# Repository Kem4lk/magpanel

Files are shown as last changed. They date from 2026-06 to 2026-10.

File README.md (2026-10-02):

# FM6363C 80x40 1/20-scan HUB75E panel - ESP32-S3 driver (deneysel port)

mrcodetastic'in **ESP32-PWM-MatrixPanel-DMA** (MBI5153, ESP32-S3) implementasyonunun
FM6363C cipine portu. Panel: P4 indoor 80x40, 1/20 scan, 74HC138 satir decode,
FM6363C S-PWM surucu. Register degerleri panelin fabrika .ssx profilinden alindi.

## Mimari
- **LCD peripheral (DMA)**: DCLK + 6 RGB SDI hatti + LE/LAT -> grayscale verisi ve komutlar
- **GPSPI2 octal (DMA, sonsuz dongu)**: GCLK + A..E adres hatlari (satir tarama)

## Kablolama (mevcut HUB75 baglantin korunuyor)
| HUB75 | Islev | GPIO |
|---|---|---|
| R1 G1 B1 | ust yari SDI | 4, 5, 6 |
| R2 G2 B2 | alt yari SDI | 7, 15, 16 |
| A B C D E | satir adresi | 18, 8, 3, 9, 13 |
| CLK | DCLK | 12 |
| LAT | LE (komut) | 10 |
| OE | **GCLK** | 11 |

## Sensörler ve tam bağlantı şeması
`hardware/` klasöründe koddan üretilen şema (`gen_schematic.py` → `schematic.svg/png`) ve
pin tablosu var: [hardware/README.md](hardware/README.md). HUB75 kablolaması değişmedi;
beş JSUMO modülü ESP'nin SAĞ başlığına takılır (hepsi 3V3 ile beslenir):

| Modül | Pin | GPIO |
|---|-----|---|
| LDR Sensor Board (3 pin, dijital) | DO | 1 (ADC1) |
| Microphone Sound Sensor (3 pin, dijital) | OUT | 42 |
| KY-040 Mechanic Encoder | CLK / DT / SW | 41 / 40 / 39 |
| DHT11 Temperature & Humidity | OUT | 47 |
| TTP223B Digital Touch | SIG | 21 |

Firmware tarafı (`include/sensors.h`, `include/sensor_logic.h`): enkoder = parlaklık,
enkoder/dokunmatik/çift alkış → uyku-uyan / sonraki uygulama / sonraki galeri / oto parlaklık
(web UI "Sensörler & kontroller" kartından eşlenir, NVS'te kalır); LDR ile oto parlaklık;
"Oda" (sıcaklık/nem/ışık/saat) ve "Ses" (VU) uygulamaları; 1 Hz `S:` telemetri + `/api/sensors`.

**KiCad taşıyıcı kart:** ESP32-S3-DevKitC-1 soketi, 2× 74HCT245 DIP-20 (3.3 → 5 V), üç HUB75E
çıkışı ve sensör başlıkları olan 2 katmanlı PCB. Şematik, PCB, gerber ve BOM koddan üretilir:
[hardware/kicad/README.md](hardware/kicad/README.md).

## Derleme
VS Code + PlatformIO eklentisi. Proje klasorunu ac -> Build -> Upload.
(`platformio.ini` ESP32-S3 DevKitC-1 icin hazir.)

## Test asamalari ve sorun giderme
1. **Duz kirmizi/yesil/mavi dolgular**: Temizse config + veri yolu calisiyor demektir.
   - Panel tamamen karanliksa: once `FM_GCLKS_PER_ROW`'u 148 yap (cift-kenar sayim ihtimali),
     olmadi GCLK frekansini dusur (spi_dma_seg_tx_loop.c).
   - Renkler yer degistirmisse: app_constants.hpp'de R/G/B pinlerini duzelt.
2. **Kose pikselleri**: Dort kose dogru yerde ve dogru renkteyse haritalama tamam.
   - Ust/alt yarilar ters ise R1<->R2 gruplarini degistir.
   - Satirlar 2'serli atliyorsa D ve E pinlerini degistir.
3. **Piksel yurutme**: x=0..79 duzgun soldan saga akmiyorsa izledigi sirayi not et:
   - 16'sarlik bloklar ters siradaysa: `FM6363_REVERSE_CHANNEL_ORDER 1` yap.
   - Daha karmasik bir desen varsa fabrika .ssx LookUpTab remap'ini ekleyecegiz (bende cozumu hazir).

## Bilinen belirsizlikler (ilk testte netlesecek)
- GCLK cift-kenar sayimi: 74 vs 148 GCLK/satir denemesi gerekebilir.
- VSYNC sirasinda GCLK duraklatma zamanlamasi hassas olabilir.
- Kanal sirasi (ch15 ilk mi) panel PCB'sine bagli.

## Guncelleme (OTA) ve tek komutla deploy
- Her panel `GITHUB_AUTO_OTA` ile `releases/latest`'teki `version.txt`'i yoklar; build
  numarasi artmissa `firmware.bin`'i indirip kurar. Kurulum sirasinda panelde **tum
  piksellerden olusan, alttan dolan loading ekrani** gosterilir (`drawOtaLoading`).
- "Yukle/deploy" demek icin: `tools/magpanel-mcp/` altindaki MCP sunucusu (repo kokundeki
  `.mcp.json` ile otomatik kayitli). Claude'a **"yukle"** dediginizde `deploy_update` araci
  CI'yi tetikler; firmware `latest` release'e gider ve internete bagli tum paneller otomatik
  guncellenir. Kurulum: [tools/magpanel-mcp/README.md](tools/magpanel-mcp/README.md).

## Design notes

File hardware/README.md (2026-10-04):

# MagPanel donanım — bağlantı şeması ve sensörler

ESP32-S3-DevKitC-1 + HUB75E LED panel (P4 80×120 ya da P1.86 172×86, 1–3 modül) +
beş JSUMO sensör/kontrol modülü. Şema **koddan üretilir** (`gen_schematic.py`, sadece
stdlib) — kasa gibi (`enclosure/generate_case.py`) parametrik: pin değişince script'i
düzelt, yeniden üret. Pin ataması `include/sensors.h` ve `include/app_constants.hpp`
ile birebir aynı olmalı.

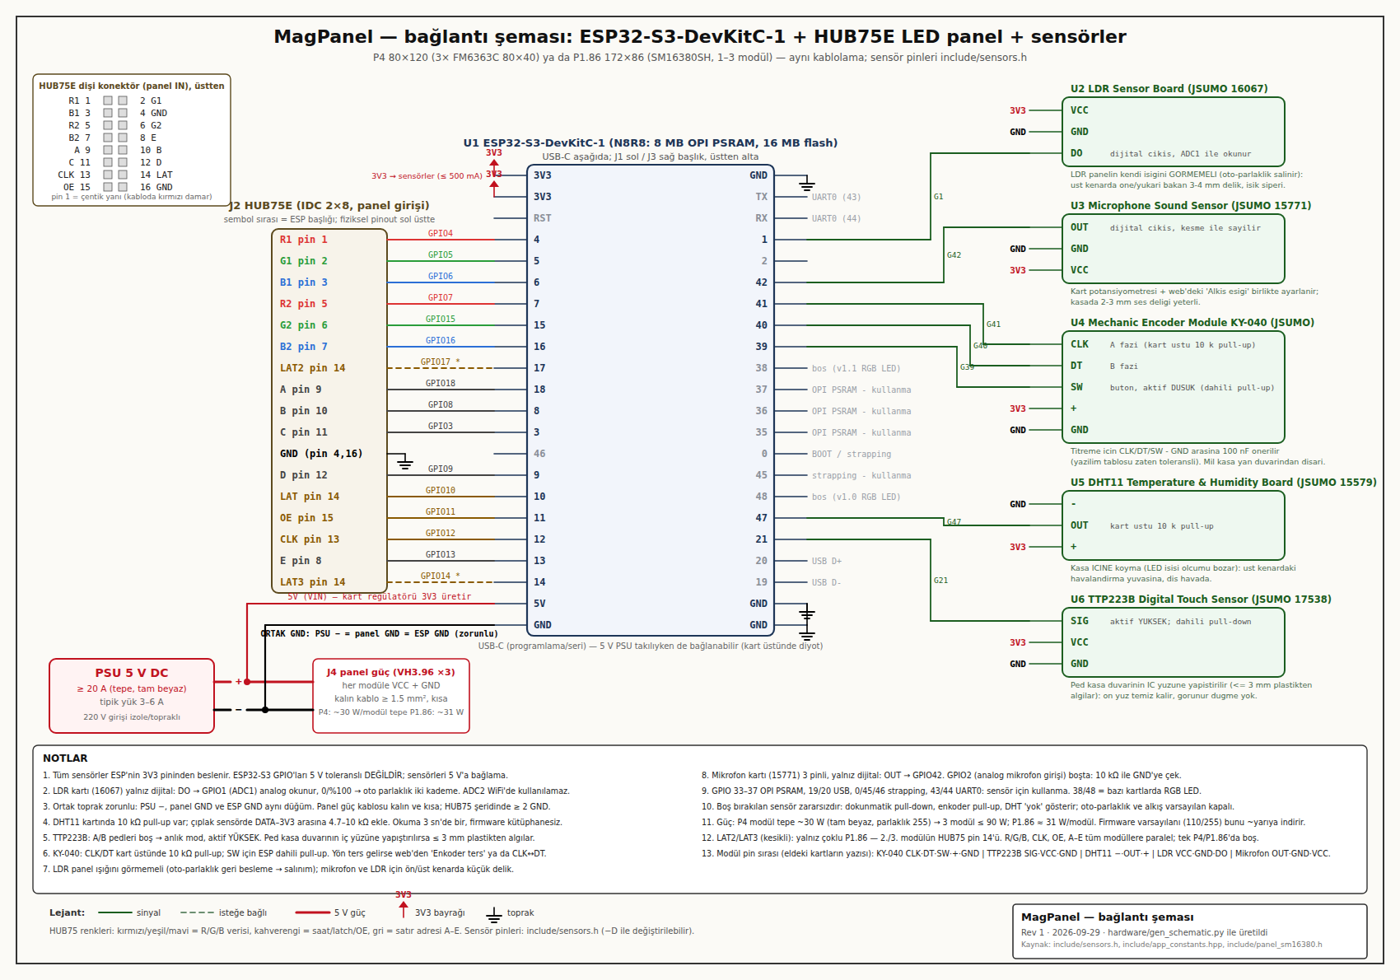
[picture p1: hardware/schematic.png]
MagPanel bağlantı şeması


Vektör: [`schematic.svg`](schematic.svg) · Üretici: [`gen_schematic.py`](gen_schematic.py)

## KiCad taşıyıcı kart (şematik + PCB)
Aynı bağlantıların üretilebilir hâli: DevKit soketi, 2× 74HCT245 (DIP-20) seviye dönüştürücü,
3× HUB75E çıkışı (LAT panel başına), 5 V giriş koruması ve sensör başlıkları. KiCad 8
projesi, gerber/BOM/CPL dosyaları ve üretici [`kicad/`](kicad/README.md) klasöründe.

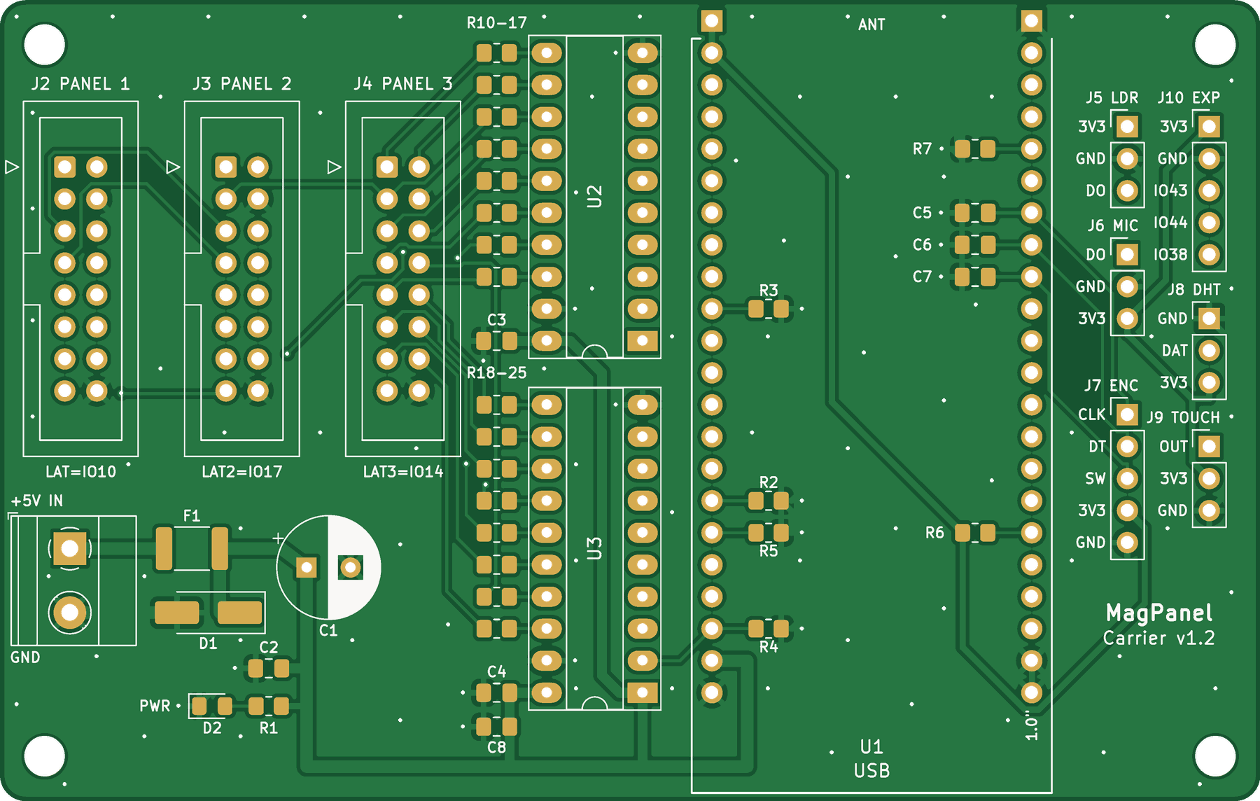
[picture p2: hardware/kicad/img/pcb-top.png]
MagPanel taşıyıcı kart


## Pin tablosu (ESP32-S3-DevKitC-1)

### HUB75E (değişmedi — `include/app_constants.hpp`)
| HUB75 pin | İşlev | GPIO | | HUB75 pin | İşlev | GPIO |
|---|---|---|---|---|---|---|
| 1 | R1 | 4 | | 9 | A | 18 |
| 2 | G1 | 5 | | 10 | B | 8 |
| 3 | B1 | 6 | | 11 | C | 3 |
| 4 | GND | GND | | 12 | D | 9 |
| 5 | R2 | 7 | | 13 | CLK (DCLK) | 12 |
| 6 | G2 | 15 | | 14 | LAT (LE) | 10 |
| 7 | B2 | 16 | | 15 | OE (P4: GCLK) | 11 |
| 8 | E | 13 | | 16 | GND | GND |

Çoklu P1.86 (2–3 modül, `include/panel_sm16380.h`): tüm modüller R/G/B, CLK, OE, A–E
hattını paylaşır; **2. modülün LAT'ı GPIO17, 3. modülün LAT'ı GPIO14** (şemada kesikli).

### Sensörler (`include/sensors.h`; `-DSENS_PIN_*` ile değiştirilebilir)
| Modül (JSUMO kodu) | Modül pini | GPIO | Mod | Not |
|---|---|---|---|---|
| LDR Sensor Board (16067) | DO | **1** (ADC1_CH0) | analog okuma | kart yalnız dijital: oto parlaklık iki kademe |
| Microphone Sound Sensor (15771) | OUT | **42** | giriş, pull-up | kart yalnız dijital: kesme sayımı, VU + çift alkış |
| (analog mikrofon girişi) | — | **2** (ADC1_CH1) | analog | eldeki kartta yok; boşta kalmasın (taşıyıcıda R7 10 kΩ GND) |
| Mechanic Encoder Module KY-040 | CLK (A) | **41** | giriş, pull-up | kesme, tam-adım tablo |
| KY-040 | DT (B) | **40** | giriş, pull-up | |
| KY-040 | SW | **39** | giriş, pull-up | aktif düşük; kısa/uzun basma |
| DHT11 Temperature & Humidity Board (15579) | OUT | **47** | open-drain + pull-up | 3 sn'de bir okuma |
| TTP223B Digital Touch Sensor (17538) | SIG | **21** | giriş, pull-down | aktif yüksek, anlık mod |
| hepsi | VCC / + | **3V3** | | 5 V'a BAĞLAMA (GPIO 5 V toleranslı değil) |
| hepsi | GND / − | GND | | |

Eldeki modüllerin pin sırası (kart baskısı, 2026-10-02 fotoğrafları): LDR **VCC GND DO**,
mikrofon **OUT GND VCC**, KY-040 **CLK DT SW + GND**, DHT11 **− OUT +**, TTP223B **SIG VCC GND**.
KiCad taşıyıcı kartındaki başlıklar aynı sırada; düz kablo çaprazlamaz.

**Neden bu pinler:** HUB75 ESP'nin sol başlığını (3–18) kullanır; sensörlerin hepsi sağ
başlığa düşer → şemada kablolar çaprazlaşmaz, kablolama kolay. Analog girişler zorunlu
olarak ADC1'de (GPIO1–10; ADC2 = GPIO11–20 WiFi açıkken okunamaz). Kullanılmayanlar:
19/20 USB, 33–37 OPI PSRAM, 0/45/46 strapping, 43/44 UART0, 38/48 devkit RGB LED'i.

## Güç
| | |
|---|---|
| PSU | 5 V DC, tepe için ≥ 20 A (P4 modül tam beyaz ~30 W ×3; P1.86 ≈ 31 W/modül). Tipik yük 3–6 A. |
| Panel | J4: her modüle VCC+GND, ≥ 1.5 mm² kısa kablo. HUB75 şeridinde en az 2 GND (pin 4 + 16). |
| ESP32 | PSU +5 V → devkit **5V** pini (VIN); kart regülatörü 3V3 üretir (sensörler ≤ 500 mA bütçesinde). USB aynı anda takılı olabilir (kart diyotlu). |
| Toprak | PSU −, panel GND ve ESP GND **aynı düğüm** (ortak GND şart; `BULGULAR.md`). |

Firmware varsayılan parlaklığı (110/255) tepe gücü kabaca yarıya indirir; oto parlaklık
karanlıkta daha da düşürür.

## Modül notları
- **TTP223B:** A/B pedleri boş → anlık mod, aktif YÜKSEK. Ped **kasa duvarının iç yüzüne**
  yapıştırılırsa ≤ 3 mm plastikten algılar; ön yüz temiz kalır (görünür düğme yok).
  Firmware GPIO21'i pull-down tutar → modül takılı değilken sahte tetik yok.
- **DHT11 kartı:** üzerinde 10 kΩ pull-up var; çıplak sensörde DATA–3V3 arasına 4.7–10 kΩ.
  Kasa **içine** koyma: LED paneli ısınır, oda sıcaklığı yanlış çıkar → üst kenardaki
  havalandırma yuvasına, dış havada. DHT22/AM2302 takılırsa `-DSENS_DHT22=1`.
- **KY-040:** CLK/DT kart üstünde 10 kΩ pull-up; SW için ESP dahili pull-up. Titreme için
  CLK/DT/SW–GND 100 nF önerilir (yazılım tablosu zaten sıçrama toleranslı; KiCad
  taşıyıcı kartında C5–C7 olarak var). Yön ters
  gelirse web'den "Enkoder ters" ya da CLK↔DT değiştir. Mil kasa yan duvarından dışarı,
  düğme takılır.
- **LDR kartı:** panelin **kendi ışığını görmemeli** (geri besleme → oto parlaklık salınımı):
  üst kenarda öne/yukarı bakan 3–4 mm delik + küçük ışık siperi. Eldeki kart 3 pinli ve
  yalnız karşılaştırıcı çıkışı (DO) veriyor: firmware GPIO1'i okur, sonuç 0 ya da %100 olur.
  Oto parlaklık böylece iki kademe çalışır; geçiş eşiği kart üstündeki trimpotla ayarlanır.
  Aydınlıkta parlaklık düşüyorsa web'den "LDR ters" işaretle. Kademesiz ayar için AO'lu
  (4 pinli) LDR kartı ya da çıplak LDR + 10 kΩ bölücü GPIO1'e bağlanmalı.
- **Mikrofon kartı:** eldeki kart 3 pinli (OUT, GND, VCC) ve yalnız dijital: OUT → GPIO42.
  Firmware DO tetiklerini "yüksek ses" sayar; VU göstergesi açık/kapalı çalışır.
  GPIO2 (analog mikrofon girişi) boşta kalırsa gürültü okur: taşıyıcı kartta R7 (10 kΩ) GND'ye çeker.
  Kart potansiyometresi + web'deki "Alkış eşiği" birlikte ayarlanır (ses çubuğu alkışta
  eşik çizgisini geçmeli, konuşmada geçmemeli). Kasada 2–3 mm ses deliği yeter.

## Kasa yerleşimi (enclosure/ ile uyum)
Kapalı difüzör ön yüz korunur; hiçbir sensör önden görünmez:
- **Üst kenar:** LDR deliği (öne bakan), mikrofon deliği, DHT11 havalandırma yuvası
  (mevcut kablo çıkışının yanı). `generate_case.py`'ye üst duvara üç delik + bir yuva
  eklemek yeterli (henüz eklenmedi — bkz. açık sorular).
- **Yan kenar:** enkoder mili (7 mm delik + somun), dokunmatik ped iç yüzde (işaret için
  dışa küçük bir kabartma/sticker).
- Modüller ESP'ye kısa (≤ 30 cm) jumper ile; DHT11 ve LDR için 3 damar, enkoder 5 damar.

## Yazılım tarafı (özet — ayrıntı `CLAUDE.md`)
- `include/sensor_logic.h`: saf C++ durum makineleri (enkoder tablosu, DHT çözme, alkış,
  buton, oto parlaklık) — `tools/test_sensor_logic.cpp` ile host'ta test edilir.
- `include/sensors.h`: pinler, kesmeler, bloklamayan DHT okuma, NVS `sensors`.
- Web UI "Sensörler & kontroller" kartı: canlı değerler, oto parlaklık, eylem eşlemeleri
  (enkoder bas / uzun bas / dokunmatik / çift alkış → uyku, sonraki uygulama, sonraki galeri,
  oto parlaklık), alkış eşiği, uyku düğmesi. WS `0x11` ayar, `0x12` uyku; `"S:"` 1 Hz
  telemetri, `"C:"` ayar, `"B:"` parlaklık; HTTP `/api/sensors`.
- Yeni uygulamalar: **Oda** (sıcaklık/nem/ışık/saat), **Ses** (VU geçmişi). Hava
  uygulamasına iç mekan satırı eklendi.

## Yeniden üretmek
```bash
python3 hardware/gen_schematic.py                     # schematic.svg (kesişim kontrolü yapar)
# PNG (Chromium headless; herhangi bir SVG→PNG aracı da olur):
chromium --headless=new --hide-scrollbars --window-size=1700,1400 \
  --screenshot=/tmp/s.png file://$PWD/hardware/schematic.svg
python3 -c "from PIL import Image; Image.open('/tmp/s.png').crop((0,0,1700,1190)).save('hardware/schematic.png')"
```

## Açık sorular / doğrulanacaklar
1. LDR yönü (ışıkta artan mı azalan mı) → web'de "LDR ters".
2. Kademesiz oto parlaklık istenirse AO'lu LDR kartı ya da çıplak LDR gerekir (eldeki kart dijital).
3. Kasaya sensör delikleri eklenecek mi (generate_case.py)?
4. Enkoder/dokunmatik varsayılan eylemleri: basma = uyku/uyan, uzun basma = sonraki
   uygulama, dokunmatik = uyku/uyan, çift alkış = kapalı. Web'den değiştirilebilir.

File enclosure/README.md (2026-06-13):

# MagPanel Difüzör Kasası — 320×480 mm (P4 / 80×120 px)

`case20mm.stl` (162×162×32 mm, **kare**, ince kabuk difüzör + egg-crate takviye)
tasarımının **32×48 cm** panele uyarlanmış hâli. Aspect-ratio 1:1 → 2:3
değiştiği ve duvarlar baskıya uygun kalınlaştırıldığı için basit ölçekleme
yerine **parametrik olarak yeniden üretildi** (`generate_case.py`).

Seçimler: **kapalı difüzör ön** · **2×2 fayans** (yatağa sığsın) · **duvar montaj özelliği yok**.

## Ölçüler
| | |
|---|---|
| Dış ölçü | **326.3 × 486.3 × 31.2 mm** |
| Panel yuvası (iç) | **321.5 × 481.5 mm**, derinlik **14 mm** (panel 320×480 + 0.75 mm boşluk/kenar) |
| Ön difüzör kabuğu | 1.2 mm (ışık süzülür) |
| Egg-crate / ışık boşluğu | 16 mm, hücre adımı ~20 mm (16 hücre/genişlik) |
| Dış duvar | 2.4 mm |
| Fayans (×4) | **163.1 × 243.1 × 31.2 mm** → en az ~**245 × 170 mm** yatak gerekir |

## Parçalar (`stl/`)
- `tile_top_left/right`, `tile_bottom_left/right` — 4 fayans
- `splice_center` (4 vida) + `splice_Vtop/Vbot/Hrt/Hlf` (2'şer vida) — 5 ek plaka
- `full_case_1piece.stl` — referans tek parça (büyük yatak / CNC / dış üretim için)
- **Vida:** ~12 × **M3 kendinden kılavuzlu (self-tapping) × 12 mm**, silindir/düz baş

## Baskı
- **Yön:** her fayansı **ön yüz (difüzör) yatağa dönük** bas → düz, pürüzsüz ön; kaburgalar yukarı, destek gerekmez.
- **Difüzör için yarı saydam malzeme** (natürel/beyaz PLA, ya da "ışık geçiren" filament). Işığı eşit dağıtmak için ön kabuk dolu (%100) basılmalı; ön yüzde 4-5 katı düz tut.
- Duvarlar 1.2–2.4 mm → 0.4 mm nozül, **3–6 duvar (perimeter)** yeterli, iç dolgu ~%10.
- Plakalar düz, desteksiz basılır.

## Montaj
1. 4 fayansı ön yüz aşağı, masaya diz (egg-crate yukarı).
2. Ek plakaları arka (egg-crate) tarafından dikişlerin üstüne yerleştir; plakalar yuvalara gömülür, üstü kaburga düzlemiyle aynı hizada kalır. `splice_center` ortadaki 4'lü kavşağı, diğer 4 plaka dikiş ortalarını kenetler.
3. M3 vidaları plakadan boss'lara sık (kendinden kılavuz). Vida başları gömülü kalır, **panel düzlemini engellemez.**
4. LED paneli **LED yüzü öne (difüzöre) bakacak** şekilde yuvaya yatır; kaburga üstüne oturur. Kabloyu üst kenardaki yuvadan çıkar.

## ⚠️ Bilmen gerekenler / seçenekler
- **Ağırlık/süre:** ~**616 cm³ ≈ 764 g** plastik, toplam baskı uzun. Hafifletmek için `generate_case.py` içinde `n_cells_x`'i azalt (örn. 10 → daha seyrek ızgara), `t_front`/`rib_t`'yi 1.0'a indir.
- **Egg-crate ışık yolunda:** orijinaldeki gibi kaburgalar difüzör ile LED arasında → difüzörde **hafif ızgara/gölge deseni** olur (dekoratif "glow" görünümü). **Net görüntü** istiyorsan kaburgaları ışık yolundan çıkaran **"temiz ışık odası"** varyantını üretebilirim (söyle, yaparım).
- **Dikiş çizgisi:** fayanslar düz birleşir (butt); ön yüzde çok ince bir dikiş izi görülebilir. İstersen ışık sızdırmaz bindirme (ship-lap) eklerim.
- **Panel tutuşu:** yuvanın arkası açık; duvara asılınca panel duvarla tutulur. Taşımada düşmemesi için köşelere küçük tutucu tırnak/bant eklenebilir.
- **Panel ölçüsünü doğrula:** yuva, modülün **fiziksel dış ölçüsü 320×480 mm** ve **≤14 mm kalınlık** varsayımıyla yapıldı. Seninki farklıysa `panel_W/H`, `pocket_d`, `clr`'yi güncelle.

## Yeniden üretmek / ayarlamak
```bash
pip install trimesh manifold3d numpy
python3 generate_case.py        # stl/ klasörünü üretir
```
Tüm ölçüler `generate_case.py` başındaki `P` sözlüğünde. Panel boyutu, duvar,
derinlik, hücre sıklığı, bölme ve vida ölçüleri oradan değiştirilir.

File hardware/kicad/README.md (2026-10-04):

# MagPanel Carrier — KiCad 8 şematik + PCB

ESP32-S3-DevKitC-1'i soketle taşıyan, üç HUB75E çıkışı (P4 tek panel ya da P1.86 1–3 modül)
ve beş JSUMO sensör başlığı olan iki katmanlı taşıyıcı kart. Kasa (`enclosure/generate_case.py`)
ve bağlantı şeması (`hardware/gen_schematic.py`) gibi her şey **koddan üretilir**:
[`gen_carrier.py`](gen_carrier.py). Pin, parça ya da yerleşim değişirse dosyanın başındaki
tabloları düzelt ve yeniden üret. KiCad'de elle yapılan değişiklik bir sonraki üretimde kaybolur.

Kart üst yüz

| | |
|---|---|
| Kart | 100 × 63.5 mm, 2 katman, 1.6 mm FR4, köşelerde 4× M3 |
| İz genişliği | sinyal 0.25 mm, 3V3 0.5 mm, 5 V / VIN 0.8–1.0 mm |
| Kurallar | boşluk ≥ 0.15 mm, via 0.6/0.3 mm, kenar 0.3 mm (JLCPCB standart 2 katman) |
| El lehimi | en küçük parça 0805, el lehimi pedleri, parçalar arası ≥ 0.5 mm (DRC kuralı) |
| GND | iki katmanda döküm + dikiş via'ları |
| Doğrulama | ERC 0, DRC 0 ihlal, 0 bağlanmamış, şematik↔PCB farkı 0 |

Doğrulama satırı `fab` aşamasında her seferinde yeniden kontrol edilir. Biri sıfır değilse
gerber üretilmez.

**Evde yapmak için** iki sürüm var. İkisi de Elegoo Saturn 3 Ultra ile pozlanır ve yazıcıya hazır
`.goo` dosyalarıyla gelir: negatif dry film için `saturn3/`, Positiv 20 gibi pozitif lak için
`saturn3-pozitif/`.
- Tek yüz, 150 × 100 mm: yalnız alt bakır, tek pozlama, bakır yüzde 3 tel. DevKit pin adları
  soket sıralarının iç tarafında bakırda yazılı. Anlatım: [`TEK-YUZ.md`](TEK-YUZ.md).
- Çift yüz, 100 × 63.5 mm: kaplamasız delik, SMD'ler altta, 33 telli via. Anlatım:
  [`DIY.md`](DIY.md).

## Dosyalar
| Yol | İçerik |
|---|---|
| `magpanel-carrier/` | KiCad 8 projesi: `.kicad_pro`, `.kicad_sch`, `.kicad_pcb`, `.kicad_dru` |
| `magpanel-carrier/MagPanel.kicad_sym`, `MagPanel.pretty/` | DevKit sembolü ve soket footprint'i |
| `fab/magpanel-carrier-gerber.zip` | gerber + delik dosyaları (doğrudan yüklenir) |
| `fab/magpanel-carrier-bom.csv` | tam malzeme listesi |
| `fab/magpanel-carrier-jlc-bom.csv`, `fab/magpanel-carrier-jlc-cpl.csv` | JLCPCB SMT montajı (yalnız SMD, LCSC numaralı) |
| `fab/magpanel-carrier-robotistan-bom.xlsx`, `fab/magpanel-carrier-robotistan-pnp.xlsx` | Robotistan SMT montajı (yalnız SMD, LCSC numaralı) |
| `fab/magpanel-carrier-bomlist.xlsx` | Türkçe BOM şablonu: Fabrika Kodu, Açıklama, Designatör, Malzeme Kılıfı, Adet (yalnız SMD) |
| `fab/magpanel-carrier-schematic.pdf` | şematik (A3) |
| `fab/magpanel-carrier-1to1.pdf` | 1:1 yerleşim testi (A4, ölçek çubuklu) |
| `magpanel-carrier-ss/`, `fab-ss/` | ev yapımı tek yüz sürüm, 150 × 100 mm, bkz. [`TEK-YUZ.md`](TEK-YUZ.md) |
| `magpanel-carrier-diy/`, `fab-diy/` | ev yapımı çift yüz sürüm, bkz. [`DIY.md`](DIY.md) |
| `img/` | şematik ve kart görselleri |

Şematik: [`img/schematic.png`](img/schematic.png) · Alt yüz: [`img/pcb-bottom.png`](img/pcb-bottom.png)

## Devre
1. **5 V giriş ve koruma.** Vida klemensi J1, 1.5 A PTC sigorta F1 ve SMAJ5.0A TVS D1'den
   geçer. Ters kutupta D1 iletir ve F1 açar. Ardından 470 µF + 10 µF ile DevKit'in **5V**
   pinine ve tamponlara gider. Panel gücü bu karttan geçmez: PSU'dan panele kalın kablo.
   Kartın kendi tüketimi 1 A'in altındadır.
2. **DevKit soketi U1.** İki adet 1×22 dişi soket. Sağ sıra 1.0" (25.40 mm) uzakta: eldeki
   N16R8 klonu (2× USB-C) 1:1 baskı testinde bu sıraya oturdu. Resmi Espressif kartı 0.9"
   (22.86 mm) kullanır; onun için `DEVKIT_RIGHT_ROWS` değiştirilip yeniden üretilir. Anten
   kartın üst kenarından dışarı taşar, USB alt kenardadır.
3. **Seviye dönüştürücü.** İki CD74HCT245E (DIP-20, soketli), 3.3 V mantığı 5 V'a çevirir
   (DIR = 5 V, /OE = GND). HCT girişleri TTL eşiklidir, 3.3 V yüksek seviyeyi 5 V beslemede
   güvenle okur; düz 74HC245 bu iş için uygun değildir. A pinleri DevKit pinleriyle aynı
   2.54 mm adımda, bir iki satır kayarak kısa ve kesişmeyen izlerle bağlanır.
   LAT, LAT2, LAT3 ve OE'de 10 kΩ pull-down var: açılışta GPIO'lar sürülmezken panel karanlık
   kalır. P4'te OE hattı GCLK taşır, P1.86'da aktif-yüksek OE darbesi.
4. **HUB75E çıkışları J2–J4.** Her hatta bir 33 Ω seri direnç (R10–R25, 0805) kablo
   yansımalarını bastırır. Dirençler tek sütundadır, her biri kendi tampon pininin hizasında.
   Bütün hatlar paraleldir, yalnız LAT panel başına ayrıdır:

   | Konnektör | LAT | Kullanım |
   |---|---|---|
   | J2 PANEL 1 | IO10 | P4 ve P1.86 |
   | J3 PANEL 2 | IO17 | yalnız çoklu P1.86 |
   | J4 PANEL 3 | IO14 | yalnız çoklu P1.86 |

5. **Sensör başlıkları (3.3 V).** Pin sırası eldeki JSUMO modüllerinin baskısıyla aynıdır,
   düz kablo çaprazlamaz. GPIO'lar `include/sensors.h` ile aynıdır, her pin serigrafide yazılıdır.

   | Başlık | Modül baskısı | Kart sırası | GPIO |
   |---|---|---|---|
   | J5 LDR | VCC GND DO | 3V3, GND, DO | DO → IO1 |
   | J6 MIC | OUT GND VCC | DO, GND, 3V3 | OUT → IO42 |
   | J7 ENC | CLK DT SW + GND | CLK, DT, SW, 3V3, GND | IO41 / IO40 / IO39 |
   | J8 DHT | − OUT + | GND, DAT, 3V3 | OUT → IO47 |
   | J9 TOUCH | SIG VCC GND | OUT, 3V3, GND | SIG → IO21 |
   | J10 EXP | | 3V3, GND, IO43, IO44, IO38 | genişleme |

   LDR ve mikrofon modülleri yalnız dijital çıkışlıdır. LDR'nin DO'su IO1'den okunur ve oto
   parlaklık iki kademe çalışır. Mikrofonun OUT'u IO42 kesmesine gider. Analog mikrofon girişi
   IO2 boşta gürültü okumasın diye R7 (10 kΩ) onu GND'ye çeker. C5–C7 enkoder için RC filtre,
   R6 DHT11 veri hattı pull-up'ıdır.

GPIO tablosu ve modül notları: [`../README.md`](../README.md).

## Yeniden üretmek
Gerekenler: KiCad 8 (`pcbnew` python modülü ve `kicad-cli`), Java 21+ (Freerouting için),
görseller için Chromium ya da Chrome (`CHROME=/yol` ile verilebilir).

```bash
cd hardware/kicad
PY=/usr/bin/python3        # Linux: KiCad'in python'u
# macOS: PY=/Applications/KiCad/KiCad.app/Contents/Frameworks/Python.framework/Versions/Current/bin/python3
$PY gen_carrier.py sch     # şematik + proje + semboller (yalnız stdlib)
$PY gen_carrier.py pcb     # yerleşim, kart çerçevesi, kilitli 5 V ana hat, SMD GND via'ları
$PY gen_carrier.py route   # Freerouting 2.1.0 + GND dökümü + dikiş via'ları
$PY gen_carrier.py fab     # ERC/DRC kapısı + gerber/delik/BOM/CPL/PDF + görseller
$PY gen_carrier.py all     # hepsi sırayla
$PY gen_carrier.py --ss all    # ev yapımı tek yüz: magpanel-carrier-ss/ ve fab-ss/ (TEK-YUZ.md)
$PY gen_carrier.py --diy all   # ev yapımı çift yüz: magpanel-carrier-diy/ ve fab-diy/ (DIY.md)
```

- `route` Freerouting jar'ını yoksa `work/` altına indirir (yaklaşık 67 MB).
- Freerouting deterministik değildir: her çalıştırma farklı ama eşdeğer bir yönlendirme
  verir. Aşama, DRC temiz çıkana kadar en çok 10 kez dener. Freerouting bağlantıyı tamam
  sayıp KiCad kopuk görürse mevcut izlerle bir tamamlama turu daha çalışır.
- `work/` ara dosyalar içindir ve git'e girmez.

## Sipariş ve montaj
- **PCB:** `fab/magpanel-carrier-gerber.zip` yükle. 2 katman, 1.6 mm, HASL ya da ENIG.
- **Önce 1:1 test:** `fab/magpanel-carrier-1to1.pdf` dosyasını yazıcıda %100 ölçekle bas,
  alttaki 100 mm çizgiyi cetvelle doğrula, gerçek parçaları deliklere oturt.
- **SMT montaj (isteğe bağlı):** bütün SMD parçalar üst yüzdedir. Montaj dosyalarında yalnız
  bunlar var (33 parça, 8 satır); delikli parçalar elle lehimlenir. Koordinatlar kartın sol-alt
  köşesine göredir, gerber ve delik dosyaları da aynı orijini kullanır. Parçaların LCSC
  numaraları `gen_carrier.py` içindeki `SMT_PARTS` tablosundadır ve LCSC'de stoklu olarak
  doğrulandı (2026-10-02). Yönler KiCad'den gelir: yerleşim önizlemesinde D1'in katot bandı
  sağda (+5V), D2'nin katodu solda (GND) olmalı.
  - JLCPCB: `jlc-bom.csv` ve `jlc-cpl.csv`.
  - Robotistan: `robotistan-bom.xlsx` ve `robotistan-pnp.xlsx` (örnek dosyalarıyla aynı sütunlar).
    BOM'daki Quantity kart başına adettir.
  - Türkçe şablon isteyen servisler: `bomlist.xlsx` (Fabrika Kodu = MPN, Adet kart başına).

### Robotistan PCB servisi
| Form alanı | Seçim |
|---|---|
| Gerber | `fab/magpanel-carrier-gerber.zip` |
| Katman, kalınlık, ölçü | 2 katman, 1.6 mm, 100 × 63.5 mm |
| Via kaplaması | Tented (maskeli), tasarım buna göre |
| Dizgi yüzeyi | Üst |
| Edge Rails/Fiducials | Robotistan tarafından eklenecek (kartta ray ve fiducial yok) |
| Komponent yerleşimi onayı | Evet (D1 ve D2'nin yönü kontrol edilsin) |
| BOM / Pick and Place | `robotistan-bom.xlsx` / `robotistan-pnp.xlsx` |

Raylar eklenirse kartlar raylı gelir. Ray kırılarak ayrılır ya da "Teslimattan önce panel ayırma"
seçilir.

### Elle lehim
Kart havyayla lehimlenecek şekilde çizildi:

| | v1.1 | v1.2 |
|---|---|---|
| Seri dirençler | 4× dizi 4×0603, komşu pedler arası 0.35 mm | 16× 0805, komşu pedler arası 1.14 mm |
| SMD ayak izi | standart ped | el lehimi pedi (dışa uzun) |
| En dar parça aralığı (courtyard) | 0.16 mm | 0.58 mm |
| 0.5 mm kuralına göre ihlal | 13 | 0 |
| HUB75 başlık gövdeleri arası | 2.4 mm | 3.8 mm |
| DevKit altındaki SMD pedi ile soket gövdesi arası | 1.2 mm | 1.6 mm |
| DIP soket pedi | 1.6 mm yuvarlak | 2.4 × 1.6 mm uzun |

- Parçalar arası en az 0.5 mm bir DRC kuralıdır (`el_lehim_aralik`). İhlal varsa gerber çıkmaz.
- Via'lar maskeyle örtülüdür, pede yakın via lehimi emmez. GND pinleri dökümle termal kolla
  bağlıdır, havya ısıyı kaybetmez.
- D1 (TVS) anodu J1'in GND pinine doğrudan kalın izle gider. Ters kutupta F1'i açan akım yolu kısadır.

Montaj sırası (alçaktan yükseğe, kart masada düz durur):
1. SMD'ler: 0805 dirençler ve kondansatörler, D2, sonra F1 ve D1. D1 ve D2'nin katodu serigrafideki
   kapalı uca bakar. DevKit altındakiler (R2–R7, C5–C7) soketlerden önce lehimlenmeli.
   SMT dizgi yaptırıldıysa bu adım hazır gelir.
2. İki DIP-20 soket. Çentik serigrafideki çentikle aynı yöne.
3. Altı pin başlık (sensörler).
4. Üç HUB75 kutu başlığı. Kutunun çentiği serigrafideki boşluğa (sola) gelir.
5. Vida klemensi J1, kablo girişi kart kenarına bakar.
6. Elektrolitik C1, uzun bacak (+) kare pede.
7. DevKit'in iki 1×22 dişi soketi en son. DevKit soketlere takılıyken lehimlenirse sıralar hizalı kalır.

İlk açılış: tamponlar ve DevKit takılı değilken 5 V ver. PWR yanmalı, DevKit soketinin 5V ve GND
pinleri arasında 5 V ölçülmeli. Sonra 74HCT245'leri (çentik aynı yöne) ve DevKit'i tak.

Başlıkların yan yana durması sorun değildir: hatlar zaten paraleldir, fiş kutunun içine oturur.
Çok çıkışlı HUB75 adaptör kartlarında başlıklar genelde bundan da sık dizilir. BOM düz kutu başlık
der. Kollu (kilitli) başlıklar daha uzundur ve bu yerleşime sığmaz.

## Açık sorular
1. Pasifler SMD varsayıldı: 0805 direnç ve kondansatör, 1812 PTC, SMA TVS (hepsi el lehimi pedli).
   Elinde delikli parçalar varsa ayak izleri `FP` tablosundan değiştirilip yeniden üretilir.
2. 5 V klemens 5.08 mm adımlı, elektrolitik 8 mm çaplı ve 3.5 mm bacak aralıklı varsayıldı.
3. Kasa: `enclosure/generate_case.py` henüz bu kart için ayak ve sensör deliği içermiyor.
   Montaj delikleri köşelerden 3.5 mm içeride.
4. Yönlendirme otomatiktir ve 10–20 MHz HUB75 için yeterlidir. KiCad'de elle güzelleştirme
   yapılabilir ama `route` yeniden çalışınca kaybolur.

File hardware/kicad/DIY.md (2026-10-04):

# Ev yapımı çift yüz kart: Elegoo Saturn 3 Ultra + dry film ya da Positiv 20

Aynı şematiğin evde yapılacak sürümü. Kart çizimi ayrı bir KiCad projesidir
(`magpanel-carrier-diy/`), çıktılar `fab-diy/` altındadır. Hepsi `gen_carrier.py --diy` ile
üretilir, fabrika kartının dosyalarına dokunmaz. Pozlama dosyaları Saturn 3 Ultra içindir (12K
ekran, 11520 × 5120 piksel). Düz Saturn 3 için bkz. 1. adım.

Tek yüz plaket için ayrı, daha büyük bir kart var: 150 × 100 mm, tek pozlama, 3 tel. Bkz.
[TEK-YUZ.md](TEK-YUZ.md).

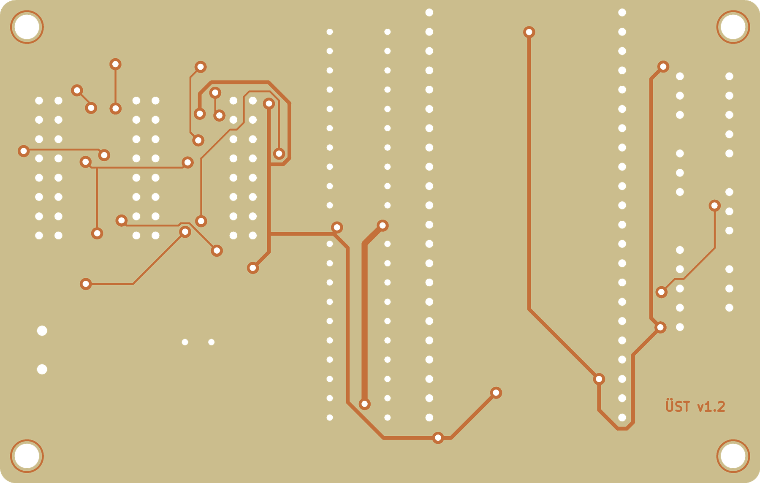
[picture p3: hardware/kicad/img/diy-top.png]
Ev yapımı kart, üst yüz


## Fabrika kartından farkı
| | Fabrika kartı (`fab/`) | Ev yapımı kart (`fab-diy/`) |
|---|---|---|
| Delik kaplaması | var | yok, her via'ya tel |
| Delikli parça pedleri | iki yüzde | yalnız altta, lehim alttan |
| SMD parçalar | üstte | altta |
| Üst katman | sinyal ve GND | yalnız via'lar arası köprü izleri |
| Sinyal izi / boşluk | 0.25 / 0.2 mm | 0.25 / 0.2 mm |
| Güç ve GND | 0.5–1.0 mm | 0.5–1.0 mm, boşluk 0.3 mm |
| Via | 0.6 / 0.3 mm | 1.6 / 0.8 mm, 33 adet |
| GND dökümü | iki yüzde | yalnız altta |
| Lehim maskesi, serigrafi | var | yok, montaj için 1:1 çizim |

Delikler kaplamasız olduğu için soket ve başlık pinleri yalnız alttan lehimlenir. Bu yüzden
delikli pedlerin bakırı sadece alttadır. Üst katmandaki izler iki via arasında köprü kurar,
parça pinine dokunmaz. Her via bir tel parçasıdır ve iki yüzden lehimlenir.

Üç HUB75 başlığı aynı yönde yan yana durur. Ortak hatlar başlık pinlerinin arasından geçmek
zorundadır, via'ların çoğu bu bölgededir. 0.3 mm iz ve 0.25 mm boşlukla aynı kart 40–45 via
istiyordu. Üst katmanda montaj deliklerinin çevresinde hizalama halkaları ve köşede "ÜST v1.2",
altta "ALT v1.2" yazısı var. Yazılar pozlamanın yönünü doğrular.

## Dosyalar
| Dosya | İçerik |
|---|---|
| `fab-diy/saturn3/*.goo` | yazıcıya hazır pozlama dosyaları, tablo 1. adımda |
| `fab-diy/magpanel-carrier-diy-gerber.zip` | gerber ve delik dosyaları, tablo aşağıda |
| `fab-diy/magpanel-carrier-diy-assembly-bottom.pdf` | alt yüz 1:1, alttan bakış: SMD'ler ve izler |
| `fab-diy/magpanel-carrier-diy-assembly-top.pdf` | üst yüz 1:1: delikli parçalar, köprü izleri, via'lar |
| `fab-diy/magpanel-carrier-diy-bom.csv` | malzeme listesi |
| `img/diy-top.png`, `img/diy-bottom.png` | görseller |

Zip içindekiler:
| Dosya | Ne için |
|---|---|
| `…-B_Cu.gbl` | alt bakır |
| `…-F_Cu.gtl` | üst bakır |
| `…-Edge_Cuts.gko` | kart dış hattı. UVtools kartın yerini bundan bulur, ışık vermez |
| `…-Hizalama.gbr` | hizalama çerçevesi: kart kenarından 0.5 mm dışarıda 3 mm ışıklı bant |
| `…-PTH.drl`, `…-NPTH.drl` | delikler. PTH.drl pozlamada pedlere matkap merkez noktası da koyar |
| `…-B_Mask.gbs`, `…-F_Mask.gts` | isteğe bağlı UV lehim maskesi |

## Malzemeler
| Malzeme | Not |
|---|---|
| Çift yüz bakır plaket | FR4 1.6 mm, 35 µm |
| Negatif dry film | mavi fotorezist film, iki yüz için |
| Laminatör ya da ütü | 100–110 °C |
| Sodyum karbonat (çamaşır sodası) | banyo: litrede 10 g, 25–30 °C |
| Sodyum persülfat ya da demir 3 klorür | aşındırma |
| Sodyum hidroksit (kostik) | film sökme: litrede 30–50 g |
| Matkap uçları | tablodaki çaplar, matkap standı |
| Via teli | 0.6 mm kalaylı bakır tel ya da kesilmiş direnç bacağı |
| Koruma | UV gözlük, eldiven, plastik kaplar |

Delikler:
| Çap | Adet | Nerede |
|---|---|---|
| 0.8 mm | 75 | 33 via, iki DIP soket, C1 |
| 1.0 mm | 114 | DevKit soketleri, HUB75 başlıkları, sensör başlıkları |
| 1.3 mm | 2 | klemens J1 |
| 3.2 mm | 4 | montaj delikleri |

## 1. Pozlama dosyaları
`fab-diy/saturn3/` içindeki dosyalar USB belleğe kopyalanıp doğrudan basılır.

| Dosya | Ne yapar | Süre |
|---|---|---|
| `pozlama-testi.goo` | 6 şerit: 60, 65 … 85 s. 5 s'lik eşit pozlamalar birikir | 120 s + 17 × 5 s |
| `alt-60s.goo` … `alt-85s.goo` | alt bakır + çerçeve + pedlerde matkap merkez noktası | 120 s + adındaki süre |
| `ust-60s.goo` … `ust-85s.goo` | üst bakır, aynalı + çerçeve | 120 s + adındaki süre |
| `cerceve.goo` | yalnız hizalama çerçevesi: yerleştirmeyi denemek için, şart değil | 120 s |

Her dosyanın ilk katmanı 2 dakika yalnız hizalama çerçevesini yakar. Kart bu sürede yerleştirilir,
pozlama sonra kendiliğinden başlar. Dosyayı durdurup yenisini başlatmak gerekmez, kart kaymaz.
Bakır dosyaları testteki altı süre için ayrı ayrı var: testte en iyi şerit hangisiyse aynı süreli
dosyayı bas. Bu filmle Saturn 3 Ultra'da 70–80 s iyi sonuç veriyor, test bu aralığı ortalar. Başka bir süre için: `DIY_EXPOSURE=25 $PY gen_carrier.py --diy fab` (virgülle birden
çok süre), ya da [UVtools](https://github.com/sn4k3/UVtools)'ta dosyayı aç, **Tools → Edit print
parameters**, yalnız Exposure time'ı değiştir. Bottom exposure time yerleştirme süresidir.

**Pozitif lak (Positiv 20).** Işık alan yer çözülür, negatif filmin tersi. `fab-diy/saturn3-pozitif/`
dosyalarını kullan: kartın içinde renkler ters, adlar `pozitif-` ile başlar. Kaplama, banyo ve sökme
farkları [TEK-YUZ.md](TEK-YUZ.md)'deki tabloda.

**Yazıcı modeli.** Dosyaların başlığındaki makine adı `ELEGOO Saturn 3 Ultra`. Yazıcı başka modelin
dosyasını format hatasıyla reddedebilir. Ekran iki modelde aynıdır. Düz Saturn 3 için:
`GOO_MACHINE='ELEGOO Saturn 3' $PY gen_carrier.py --diy fab`.

**Kendi dosyanı yapmak istersen** ya da yazıcı dosyayı açmazsa: Chitubox ya da Lychee'de kendi
yazıcın için küçük bir küp dilimle, `.goo` olarak kaydet, UVtools 7'de aç ve **Tools → PCB
exposure** aracını seç. Araç dosyanın katmanlarını silip pozlama görüntüsünü koyar. Bu dosyada
yerleştirme katmanı olmaz: kartı önce `cerceve.goo` ile yerleştir, durdur, sonra bakır dosyasını
başlat.

| Kaydet | Eklenecek dosyalar | Mirror |
|---|---|---|
| `cerceve.goo` | Edge_Cuts.gko, Hizalama.gbr | kapalı |
| `alt.goo` | Edge_Cuts.gko, B_Cu.gbl, Hizalama.gbr, PTH.drl | kapalı |
| `ust.goo` | Edge_Cuts.gko, F_Cu.gtl, Hizalama.gbr | açık |

| Ayar | Değer | Neden |
|---|---|---|
| Merge files into a single layer | açık | bakır, çerçeve ve delik noktaları tek pozlamada |
| Invert color | kapalı | negatif film: ışık alan yer sertleşir, altındaki bakır kalır |
| Anchor | Middle center | kart ekranın ortasına gelir, ışık orada en düzgün |
| Offset X / Y | 0 | |
| Exposure time | test süresi, `cerceve.goo` için 120 s | |
| Flip vertically | açık | varsayılan |
| Enable anti-aliasing | kapalı | |
| PTH.drl satırı | Size scale 0.4, Invert polarity işaretsiz | UVtools delikleri zaten karanlık çizer: pedin ortasında bakırsız nokta kalır |
| Edge_Cuts.gko satırı | board outline işaretli | `.gko` uzantısını kendisi tanır. Kartın yeri bu dosyadan hesaplanır |

Çerçeve simetriktir. Mirror görüntüyü çerçevenin, yani kartın tam ortasından aynalar. Bu ayarlarla
üç dosyada çerçeve aynı yere, ekranın ortasına düşer: UVtools 7.0.1 komut satırıyla üretilip
ölçüldü.

## 2. Kâğıtla prova
Hazneyi ve tablayı çıkar. Ekrana beyaz kâğıt koy, `alt-60s.goo`'yu ve `ust-60s.goo`'yu sırayla
başlat: her biri 2 dakika çerçeve, sonra 60 s desen. Telefon kamerasıyla yukarıdan bak. 405 nm
ışığa çıplak gözle uzun bakma.
- Çerçevenin tamamı ekranda görünmeli.
- `alt-60s.goo`'da "ALT v1.2", `ust-60s.goo`'da "ÜST v1.2" yazısı **ters** görünmeli. Bakır yüz
  ekrana bakar, yukarıdan kartın sırtını görürsün. Bir dosyada yazı düz görünüyorsa o dosyanın
  Mirror ayarını değiştir.
- İki yazı çerçevenin aynı köşesinde olmalı. Öyleyse kart 5. adımda sağdan sola çevrilir.
  Farklı köşelerdeyse yazıcı dikey aynalıyor: kartı çevirirken ön ve arka kenar yer değiştirsin.
- Yazıcı başlarken kolunu aşağı indirir. Tabla takılı değilken kol ekrana inmez, ama kolun nereye
  kadar indiğine bu provada bak. Kartın üstüne koyacağın ağırlık ondan alçak olsun.

## 3. Pozlama süresi testi
Filmin hassasiyeti markadan markaya değişir. `pozlama-testi.goo` altı süreyi tek seferde dener.
1. Yaklaşık 100 × 28 mm'lik bir plaket şeridine film lamine et (4. adımdaki gibi).
2. Dosyayı başlat. İlk 2 dakika yalnız çerçeve yanar, iç boşluğu 101 × 29 mm. Bu sürede şeridi
   film yüzü aşağıda çerçevenin ortasına koy, üstüne cam ve ağırlık. Altı şeridin tamamı
   plaketin altında kalmalı (96 × 24 mm). Pozlama sonra kendiliğinden başlar.
3. Banyo et (6. adım). Etiketler film yüzünde düz okunur, yukarıdan bakınca terstir.
4. Doğru süre: film kalkmayan şeritler içinde 0.2 mm çizgi aralıkları açık kalan ve pedlerin
   arasından geçen iz pedlere değmeyen en kısa süre. Uzun süre aralıkları kapatır, kısa süre
   filmi banyoda kaldırır.

## 4. Kartı hazırla
1. Plaketi 100.0 × 63.5 mm kes. Kenarları zımparala: çapak ekranı çizer.
2. Bakırı ince bulaşık teli ve deterjanla parlayana kadar temizle, durula, kurula.
   Parmak izi bırakma.
3. Sarı ışıkta ya da loş odada iki yüze film lamine et. Filmin yumuşak iç koruyucusunu soy,
   sert dış koruyucu üstte kalsın. Kabarcık bırakma.
4. Kartın bir uzun kenarının kalınlık yüzüne keçeli kalemle çizgi çek. Bu ön kenardır, iki
   pozlamada da yazıcının önüne bakar.

## 5. Hizala ve pozla
1. Hazne ve tabla takılı değil. Ekranı alkolle sil.
2. Testte seçtiğin sürenin alt dosyasını başlat, örneğin `alt-75s.goo`. İlk 2 dakika yalnız
   çerçeve yanar. Kartı film yüzü aşağıda, ön kenarı öne bakacak şekilde çerçevenin içine koy.
   Dört kenarda da eşit, ince karanlık boşluk kalsın (0.5 mm). Telefonla yakından bak.
3. Üstüne düz bir cam ve hafif bir ağırlık koy. Kart ekrana tam otursun ve kaymasın. 2 dakika
   dolunca bakır kendiliğinden pozlanır, bitmesini bekle. Yetişemezsen dosyayı durdur, baştan başlat.
4. Kartı kitap sayfası çevirir gibi çevir: sol ve sağ kenar yer değiştirir, ön kenar yine önde.
5. Aynı süreli üst dosyasını başlat, örneğin `ust-75s.goo`, ve kartı aynı şekilde ortala.

Sağ ve sol boşluğun eşitliği önemlidir. Çevirme yüzünden sağ-sol kayma iki yüz arasında iki
katına çıkar: 0.1 mm kayma via'larda 0.2 mm kaçıklık yapar. Via halkası 0.4 mm, buna dayanır.
Ön-arka kayma iki yüzü birlikte kaydırır, hizalamayı bozmaz.

## 6. Banyo, aşındırma, film sökme
1. Pozlamadan sonra 15 dakika beklet. İki yüzün dış koruyucusunu soy.
2. Banyo: litrede 10 g sodyum karbonat, 25–30 °C. Yumuşak fırçayla 1–3 dakika. Işık almamış film
   erir, altındaki bakır parlar. Bol suyla durula.
3. Kontrol: iki yazı da kendi yüzünde düz okunmalı. Kopuk izi asetat kalemiyle tamamla,
   köprüyü maket bıçağıyla kazı.
4. Aşındır: sodyum persülfat 40–50 °C'de 10–20 dakika, kabı salla. İki yüz birlikte aşınır.
5. Filmi sök: sodyum hidroksit çözeltisinde 1–2 dakika, sonra durula.
6. Bakır çabuk kararır. Hemen lehimlenmeyecekse kimyasal kalay ya da ince lak sür.

## 7. Delme
- Alt yüzden, pedlerin ortasından del. Merkez noktaları ucu ortalar.
- Önce bütün delikleri 0.8 mm ile aç, sonra büyükleri büyüt. Kayma azalır.
- Montaj delikleri hizalama halkalarının tam ortasındadır.

## 8. Via telleri ve montaj
1. **Via telleri ilk iş.** Teli geçir, iki yüzden lehimle, iki yüzde de dibinden kes. 12 via
   HUB75 başlıklarının, biri U3 soketinin altında kalır. Üstteki lehimi yassı bırak, başlık düz
   otursun.
2. **SMD'ler alt yüze.** `assembly-bottom.pdf` alttan bakıştır. D1 ve D2'nin katot bandı
   çizimdeki kapalı uca gelir.
3. **Delikli parçalar** üstten takılır, alttan lehimlenir: DIP soketler, sensör başlıkları,
   HUB75 başlıkları, klemens, C1. DevKit soketleri en son.
4. **Ölçüm.** Her via'nın iki pedi arasında süreklilik olmalı. HUB75 başlıklarında komşu pinler
   arasında kısa devre olmamalı. Sonra [README](README.md)'deki ilk açılış adımları.

## Tek yüz sürüm
Tek yüz plaketle yapılacak sürüm ayrı bir karttır: 150 × 100 mm, tek pozlama, bakır yüzde 3 tel,
DevKit pin adları bakırda yazılı. Anlatım ve dosyalar: [TEK-YUZ.md](TEK-YUZ.md).

## İsteğe bağlı: UV lehim maskesi
Delmeden önce alt yüze UV lehim maskesi sür. UVtools'ta Edge_Cuts.gko ve B_Mask.gbs ile yeni dosya
yap: **Invert color açık**, Invert area "Inside the board outline only". Ped açıklıkları karanlık
kalır, gerisi sertleşir. Pozlamadan sonra sertleşmeyen maskeyi alkolle sil.

## Yeniden üretmek
```bash
cd hardware/kicad
$PY gen_carrier.py --diy sch     # aynı şematik, ayrı proje
$PY gen_carrier.py --diy pcb     # SMD'ler alta, delikli pedler yalnız altta, üstte delik yasakları
$PY gen_carrier.py --diy route   # 6 deneme, DRC temiz olanlardan en az vialı kalır
$PY gen_carrier.py --diy fab     # gerber + çerçeve + delik + montaj çizimleri + .goo + görseller
```

- `fab` aşaması ERC/DRC sıfır değilse durur. Ayrıca iki bakır katmanın sınır kutusunun kartın
  tam ortasında olduğunu denetler: çerçeve eklenmese de aynalama ekseni kartın ortasında kalır.
- `.goo` dosyaları için UVtools 7 komut satırı gerekir (`UVtoolsCmd`, PATH'te ya da
  `UVTOOLS_CMD=/yol`). Yoksa bu adım atlanır, gerber'ler yine üretilir.
- Freerouting 2.1.0 komut satırında geçiş sınırını uygulamıyor. Bu yüzden her çalıştırmaya süre
  sınırı verilir (4 dakika, tamamlama turu 2 dakika). Takılan deneme elenir.

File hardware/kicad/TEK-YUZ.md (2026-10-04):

# Tek yüz kart, 150 × 100 mm: Elegoo Saturn 3 Ultra + dry film ya da Positiv 20

Aynı şematiğin tek yüz plaketle yapılan sürümü. Bakır yalnız alt yüzde, kart 150 × 100 mm.
Ayrı KiCad projesidir (`magpanel-carrier-ss/`), çıktılar `fab-ss/` altındadır. Hepsi
`gen_carrier.py --ss` ile üretilir, fabrika ve çift yüz kartın dosyalarına dokunmaz. Pozlama ve
kimya adımları çift yüz kartla aynıdır, ayrıntılar [DIY.md](DIY.md)'de. Bu sayfa farkları anlatır.

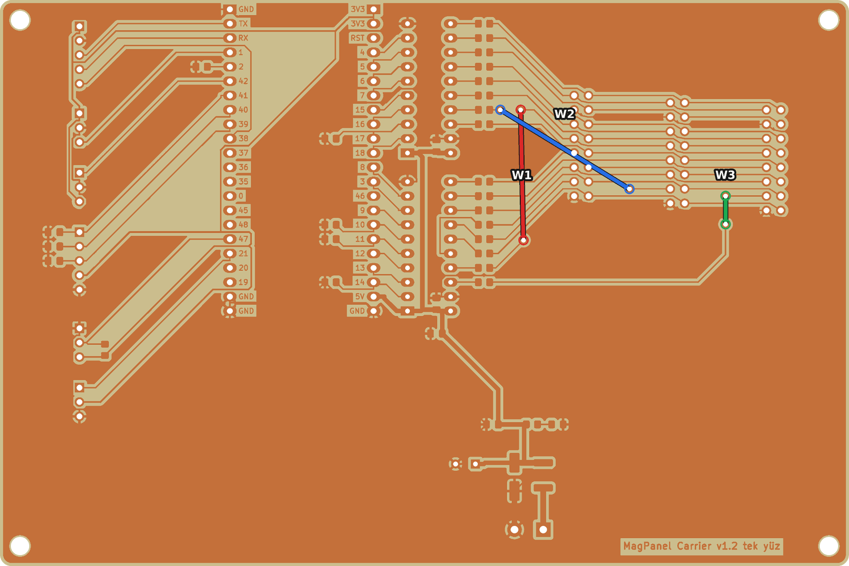
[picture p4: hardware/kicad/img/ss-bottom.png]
Tek yüz kart, bakır yüz, alttan bakış


| | Çift yüz ev yapımı (`fab-diy/`) | Tek yüz (`fab-ss/`) |
|---|---|---|
| Kart | 100 × 63.5 mm | 150 × 100 mm |
| Plaket | çift yüz | tek yüz, FR4 1.6 mm |
| Pozlama | 2, kart çevrilerek | 1 |
| Tel | 33 via teli | 3 köprü teli, toplam kesim 105 mm |
| Sinyal izi / boşluk | 0.25 / 0.2 mm | 0.25 / 0.25 mm |
| DevKit pin adları | yok | bakır yüzde, soket sıralarının iç tarafında |

## Yerleşim
Soldan sağa: üç HUB75 başlığı (J4 PANEL 3, J3 PANEL 2, J2 PANEL 1), seri 33R sütunu, iki
74HCT245, DevKit, sensör başlıkları. 5 V girişi alt kenarda, klemensin kablosu aşağıdan girer.
DevKit'in altı boştur, USB fişleri takılabilir.

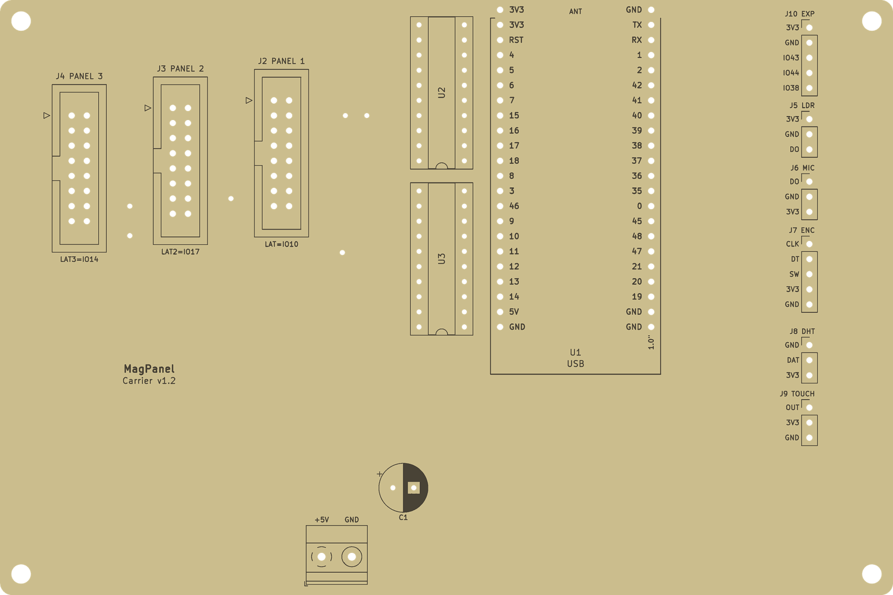
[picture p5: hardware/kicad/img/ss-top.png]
Tek yüz kart, parça yüzü


- HUB75 şeridi elle yerleştirilmiş sabit izlerdir. Başlıklar 1.27 mm kademelidir. Şerit üç
  başlıktan pinlerin arasından geçer: 2.54 mm adımlı iki pinin arasından bir iz, iz 0.25 mm, pede
  en az 0.27 mm boşluk. Şeritteki sıra başlığın pin sırasıdır.
- CLK, U3 soketinin içinden dolaşıp sütundaki yerine girer. Bunun için tel gerekmez.
- HUB75 başlıklarının 1 numaralı pedi yuvarlaktır. Kare pedin köşesi şerit izine fazla
  yaklaşıyordu. Pin 1'i başlığın kilit çentiğinden ve üst yüz çiziminden bul.
- Geri kalanı Freerouting çeker, ama yalnız alt katmanı kullanmaya zorlanır. Üst katman
  kullanmak çok pahalıya sayılır. Her deneme KiCad DRC'siyle denetlenir. DRC temiz olanlardan en az
  telli olan kalır.

## DevKit pin adları
Soket sıralarının iç tarafında, her pinin yanında yazılıdır. Adlar modülün üzerindeki baskıyla
aynıdır: GPIO numarası (4, 5, 15 …), TX, RX, 3V3, 5V, GND, RST. Bakır yüzden bakınca düz okunur.
Yazıların çevresi bakırsızdır. Yazı 0.9 mm, çizgi 0.18 mm. İki yazının arasından bir iz geçer.
Aynı adlar üst yüz çiziminde de var.

## Teller
Üç hat tek katmanda yol bulamaz. Üç başlığa giden 13 ortak hat bir şerit oluşturur ve şeritteki
sıra başlık pin sırasıdır. Firmware'in ESP32 pin sırası ise E'yi şeridin altına, LAT2'yi
şeridin içine koyar. LAT2 ve LAT3'ün başlık pinleri de şeridin içinde, CLK ile OE arasında kalır.

| Tel | Hat | Nereden nereye | Düz | Kesim |
|---|---|---|---|---|
| W1 | E (HUB_ADDR_E) | 33R sütununun altı, OE'nin altı → J2'nin önü, B2 ile A arası | 23 mm | 40 mm |
| W2 | LAT2 | 33R sütunu, B2 ile A arası → J2 ile J3 arası | 27 mm | 45 mm |
| W3 | LAT3 | J3 ile J4 arası: şeridin altından CLK ile OE arasına | 5 mm | 20 mm |

Teller bakır yüzdedir ve yalıtımlıdır, uçları tel pedlerine lehimlenir. İletkeni 0.5–0.6 mm
olan tek damarlı tel kullan. Haritadaki çizgi yalnız hangi iki pedin bağlanacağını gösterir. Teli
lehim noktalarının üstünden geçirmeden götür, gerekirse bir damla yapıştırıcıyla sabitle. Kesim
boyu, düz mesafenin 1.3 katı artı iki uç için 10 mm'dir, 5 mm'ye yuvarlanır.

Teller ister parça yüzünden de geçebilir. Tel pedlerini 0.8 mm del ve teli üstten geçir. Altı
pedin hiçbiri bir parçanın altında kalmaz. W2 ise J2 başlığının gövdesinin etrafından dolaşır.

## Dosyalar
| Dosya | İçerik |
|---|---|
| `fab-ss/saturn3/pozlama-testi.goo` | 6 şeritli süre testi: 60, 65 … 85 s |
| `fab-ss/saturn3/alt-60s.goo` … `alt-85s.goo` | bakır + çerçeve + pedlerde matkap merkez noktası, adındaki süre kadar |
| `fab-ss/saturn3/cerceve.goo` | yalnız hizalama çerçevesi, 120 s. Yerleştirmeyi denemek için, şart değil |
| `fab-ss/saturn3-pozitif/` | Positiv 20 gibi pozitif lak için aynı dosyalar, kartın içinde renkler ters: `pozitif-pozlama-testi.goo`, `pozitif-alt-60s.goo` … `pozitif-alt-85s.goo` |
| `fab-ss/magpanel-carrier-ss-gerber.zip` | B_Cu, Edge_Cuts (`.gko`), Hizalama, PTH/NPTH delik, B_Mask |
| `fab-ss/magpanel-carrier-ss-teller.pdf` | A4, %100 ölçek: alttan bakış tel haritası, tel listesi, tellerin olduğu bölge büyük |
| `fab-ss/magpanel-carrier-ss-teller.csv` | tel listesi: uçların koordinatı (alttan bakış, sol-alt köşeden), mesafe, kesim |
| `fab-ss/magpanel-carrier-ss-assembly-bottom.pdf` | bakır yüz 1:1, alttan bakış: SMD'ler, izler, tel pedleri |
| `fab-ss/magpanel-carrier-ss-assembly-top.pdf` | parça yüzü 1:1: delikli parçalar, pin adları |
| `fab-ss/magpanel-carrier-ss-bom.csv` | malzeme listesi, çift yüz kartla aynı parçalar |
| `img/ss-bottom.png`, `img/ss-top.png` | görseller |

Her `.goo` dosyasının ilk 2 dakikasında yalnız hizalama çerçevesi yanar. Plaket bu sürede
yerleştirilir, pozlama sonra kendiliğinden başlar. Bakır dosyası testteki altı süre için ayrı ayrı
var: testte en iyi şerit hangisiyse aynı süreli dosyayı bas. Bu filmle Saturn 3 Ultra'da 70–80 s
iyi sonuç veriyor, test bu aralığı ortalar.

Dosyalar Saturn 3 Ultra içindir, başlıktaki makine adı `ELEGOO Saturn 3 Ultra`. Yazıcı başka
modelin dosyasını format hatasıyla reddedebilir. Ekran iki modelde aynıdır. Düz Saturn 3 için
dosyaları `GOO_MACHINE='ELEGOO Saturn 3'` ile yeniden üret (aşağıda).

Kendi pozlama dosyanı UVtools ile yaparsan [DIY.md](DIY.md)'deki tablo geçerli. Alt bakır için
Edge_Cuts.gko, B_Cu.gbl, Hizalama.gbr ve PTH.drl dosyalarını ekle, Mirror kapalı kalsın.

## Pozitif lak (Positiv 20)
Kontakt Chemie Positiv 20 gibi pozitif lakta ışık alan yer banyoda çözülür. Bu, negatif filmin
tersidir: `saturn3/` dosyalarıyla kart ters çıkar, izler aşınır, aralıklar kalır. Pozitif lak için
`fab-ss/saturn3-pozitif/` dosyalarını kullan. Kartın içinde renkler ters, çerçeve aynı. Adlar
`pozitif-` ile başlar, yazıcının belleğinde negatif dosyalarla karışmaz.

| Adım | Negatif dry film | Positiv 20 |
|---|---|---|
| Kaplama | lamine, 100–110 °C | ince ve eşit sprey, karanlıkta 24 saat ya da 70 °C'de 15–20 dakika kurut |
| Pozlamadan sonra | 15 dakika bekle | beklemek gerekmez |
| Banyo | litrede 10 g sodyum karbonat, 25–30 °C | litrede 7 g sodyum hidroksit, oda sıcaklığı, 30–90 s |
| Testte doğru süre | film kalkmamış, aralıklar açık | zemin tamamen açılmış, ince çizgiler yerinde |
| Sökme | litrede 30–50 g sodyum hidroksit | aseton ya da izopropil alkol |

Kâğıtla provada kartın çoğu karanlık, izlerin çevresindeki ince aralıklar aydınlık görünür. Yazılar
yine yukarıdan ters görünmeli. Lak tamamen kurumamışsa ekrana yapışır.

## Yapım
[DIY.md](DIY.md)'deki adımlar, şu farklarla:

1. **Plaket** 150 × 100 mm tek yüz. Eldeki plaket bu ölçüdeyse kesmek gerekmez. Kenarları
   zımparala, bakırı temizle.
2. **Pozlama testi** aynı: `fab-ss/saturn3/pozlama-testi.goo`.
3. **Kâğıtla prova.** Ekrana beyaz kâğıt koy, `alt-60s.goo`'yu bas: 2 dakika çerçeve, sonra
   60 s desen. Desende kart adı ve pin adları **ters** görünmeli: bakır yüz ekrana bakar,
   yukarıdan kartın sırtını görürsün. Çerçeve 157 × 107 mm, ekranın ortasındadır. Ekran
   218.88 × 122.88 mm, yanlarda 31 mm, üstte ve altta 8 mm kalır.
4. **Pozlama.** Tek yüze film lamine et. Testte seçtiğin sürenin dosyasını başlat, örneğin
   `alt-75s.goo`. İlk 2 dakika yalnız çerçeve yanar: plaketi film yüzü aşağıda çerçevenin
   ortasına koy, üstüne cam ve hafif ağırlık. Sonra bakır kendiliğinden pozlanır. Kart çevrilmez.
5. **Banyo, aşındırma, film sökme** aynı. Kontrolde pin adları bakır yüzde düz okunmalı.
6. **Delme.** Bakır yüzden, pedlerin ortasından del:

| Çap | Adet | Nerede |
|---|---|---|
| 0.8 mm | 42 | iki DIP soket, C1 |
| 1.0 mm | 114 | DevKit soketleri, HUB75 başlıkları, sensör başlıkları |
| 1.3 mm | 2 | klemens J1 |
| 3.2 mm | 4 | montaj delikleri |
| 0.8 mm | 6 | tel pedleri, isteğe bağlı |

## Montaj sırası
1. **SMD'ler bakır yüze.** `assembly-bottom.pdf` alttan bakıştır. D1 ve D2'nin katot bandı
   çizimdeki kapalı uca gelir. Kart düz yatarken lehimlemek kolay, bu yüzden ilk iş.
2. **Delikli parçalar** üstten takılır, alttan lehimlenir: DIP soketler, sensör başlıkları,
   HUB75 başlıkları, klemens, C1. DevKit soketleri en son.
3. **Teller**, bakır yüzde, tablodaki gibi.
4. **Ölçüm.** Her telin iki ucu arasında süreklilik olmalı. HUB75 başlıklarında komşu pinler
   arasında kısa devre olmamalı. Sonra [README](README.md)'deki ilk açılış adımları.

PWR LED'i (D2) bakır yüzdedir. Kart DevKit dışarı bakacak şekilde takılırsa LED panele bakar.

## Doğrulama
| Kontrol | Sonuç |
|---|---|
| ERC | 0 bulgu |
| DRC | 0 ihlal, 0 bağlanmamış, 0 şematik farkı |
| Teller | KiCad bağlantı denetimi: üst katman silinip teller iz olarak eklenince 0 bağlanmamış |
| Pozlama dosyaları | UVtools 7.0.1 katman görüntüsünde çerçeve 157.0 × 107.0 mm, ekranın ortasında. Yerleştirme katmanının çerçevesi bakır katmanındakiyle piksel piksel aynı |
| Pozitif dosyalar | kart dış hattının içinde negatifin tam tersi, dışı aynı. Test şeritlerinin zemini 60–85 s, deseni 0 s ışık alıyor |

Kartın kendisi henüz yapılıp denenmedi. Pozlama süresini önce test şeridiyle bul.

## Yeniden üretmek
```bash
cd hardware/kicad
$PY gen_carrier.py --ss sch     # aynı şematik, ayrı proje
$PY gen_carrier.py --ss pcb     # yerleşim, sabit HUB75 şeridi ve 3 tel, pin adları
$PY gen_carrier.py --ss route   # Freerouting, 6 deneme: DRC temiz olanlardan en az telli kalır
UVTOOLS_CMD=/yol/UVtoolsCmd $PY gen_carrier.py --ss fab
```

- Başka pozlama süreleri: `DIY_EXPOSURE=25` ya da `DIY_EXPOSURE=25,35` ile `fab`. Düz Saturn 3:
  `GOO_MACHINE='ELEGOO Saturn 3'`.

- Freerouting bazen "tamam" der ama çıktı dosyasına birkaç ağı hiç yazmaz. KiCad bunları kopuk
  görür. `route` önce tamamlama turu çalıştırır, yine kopuk kalan denemeyi eler.
- Yerleşim `ss_place()`, sabit izler `ss_hub_tracks()` içindedir. Başlık aralığını ya da
  sütunu değiştirirsen sabit izler kendi kendine uyar. Kontroller yanlış geometride durur.

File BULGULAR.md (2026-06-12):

# FM6363C 80x40 1/20 Panel + ESP32-S3 — Teknik Bulgular ve Durum

## Panel kimliği
- KingColor P4-2121-80x40-2S, FM6363C S-PWM sürücü (DriveChipType=51074), 74HC138 satır decode
- Renk başına 10 çip (UR1-10/UG/UB): yarı başına 5'li zincir, 16 kanal/çip
- Konnektör: standart HUB75E pinout (serigrafiyle doğrulandı)
- Fabrika .ssx profili çözüldü: CFG1 R/G/B=0x13F0/0x13B0/0x13B0, CFG2=0xF39D/0xE79D/0xD79D,
  CFG3=0x60B6, CFG4(default)=0x5A00/0x5A70/0x5A70; GCLKMaxNum=73 (74 GCLK/satır),
  GCLKDeadTime=3, VSYNC LE=3, PRE_ACT=14; LookUpTab = birebir kimlik (remap yok)

## Kanıtlanmış protokol bilgisi
- LE komutları: DATA_LATCH=1, VSYNC=3, WR_CFG1/2/3/4=4/6/8/10, EN_OP=12, DIS_OP=13, PRE_ACT=14
- Init: PRE_ACT, EN_OP, sonra her register öncesi PRE_ACT (calismasi dogrulandi)
- Frame başı (gerçek kontrolcü kaydı): LE=14,12,3 (PRE_ACT, EN_OP, VSYNC)
- KRİTİK KEŞİF: HUB75 modunda (cfg1[5:4]=11) çip, gelen satır verisini O ANKİ HARİCİ
  ADRESİN seçtiği SRAM satırına yazıyor (adres-eşzamanlı yazım). Asenkron tarama+veri
  mimarisi bu yüzden satır-değişken içeriği dağıtıyor; satır-sabit içerik (dolgular) etkilenmiyor.
  Gerçek alıcı kartlar her satırın verisini o satırın tarama dilimi içinde gönderir.

## Ölçülmüş eşleme (kalibrasyonla)
- X tam aynalı: x' = 79 - x (blok sırası b→4-b VE blok içi kanal c→15-c, ikisi de ters)
- Yarılar takaslı: fiziksel ÜST yarı ← R2/G2/B2, ALT yarı ← R1/G1/B1
- Satır eşleme: senkron motorda kimlik + ofset (runtime row_offset ile taranabilir)

## Donanım notları
- Ortak GND şart; 2 GND bağlı. Jumper'larla DCLK ≤ 2.5MHz güvenli; 7MHz sınırda
- HUB75 OE pini = GCLK; CLK = DCLK; LAT = LE

## Yazılım mimarileri
1. v13 (çift motor: LCD=veri, GPSPI2=GCLK+adres): Dolgu/RGB döngüsü/satır-sabit içerik KUSURSUZ.
   Satır-değişken içerik adres-eşzamanlı yazım yüzünden dağılıyor. Yedeği: include/Matrix_v13_backup.h
2. syncengine (tek motor: LCD d0-d6=veri/LAT, d7=GCLK, d8-12=A-E): Yatay içerik artık
   görünüyor; satır hizası (row_offset) ve segment-içi renk karışması (veri/GCLK bit zamanlaması)
   henüz çözülmedi. Mevcut kod bu mimaride.

## Kalan iş ve önerilen yol
- Logic analyzer ile DCLK/LE/GCLK dalga biçimini kılavuz Şekil/Tablolarıyla karşılaştırmak
  (en hızlı bitirme yolu). Şüpheliler: LE kenarının DCLK fazına göre konumu, GCLK'nın
  latch anındaki durumu, satır dilimi içinde veri→GCLK sıralaması.
- Alternatif: HD-R500 benzeri alıcı kart (garanti çözüm, .ssx hazır).
- Topluluk: mrcodetastic/ESP32-PWM-MatrixPanel-DMA issue'larında FM6363 portu açıkça davet
  edilmiş durumda; bu bulgular oraya taşınabilir.

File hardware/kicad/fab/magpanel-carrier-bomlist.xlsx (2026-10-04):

Fabrika Kodu | Açıklama | Designatör | Malzeme Kılıfı | Adet
CL21A106KAYNNNE | 10uF 25VDC ±10% X5R (Samsung) | C2,C8 | 0805 | 2
CC0805KRX7R9BB104 | 100nF 50VDC ±10% X7R (YAGEO) | C3,C4,C5,C6,C7 | 0805 | 5
SMAJ5.0A | TVS Diode 5V 400W Unidirectional (Littelfuse) | D1 | SMA (DO-214AC) | 1
KT-0805G | Green LED 525nm (Hubei KENTO) | D2 | 0805 | 1
MF-MSMF150-2 | PTC Resettable Fuse 6V 1.5A hold 3A trip (BOURNS) | F1 | 1812 | 1
0805W8F2201T5E | 0805 2.2K Ohms 1% 1/8W (UNI-ROYAL) | R1 | 0805 | 1
0805W8F1002T5E | 0805 10K Ohms 1% 1/8W (UNI-ROYAL) | R2,R3,R4,R5,R6,R7 | 0805 | 6
0805W8F330JT5E | 0805 33 Ohms 1% 1/8W (UNI-ROYAL) | R10,R11,R12,R13,R14,R15,R16,R17,R18,R19,R20,R21,R22,R23,R24,R25 | 0805 | 16

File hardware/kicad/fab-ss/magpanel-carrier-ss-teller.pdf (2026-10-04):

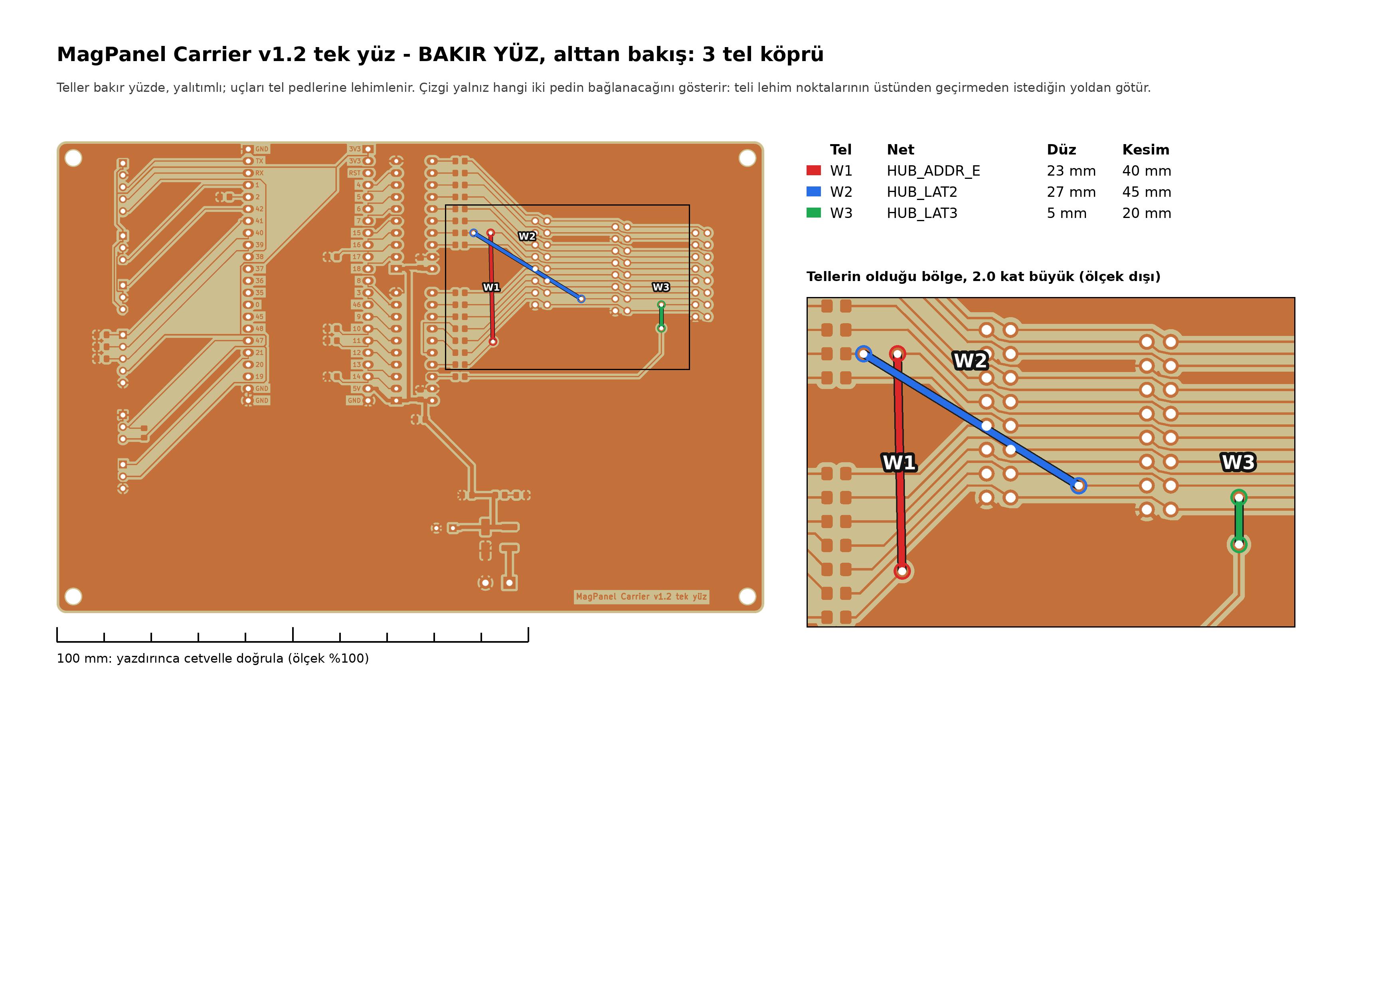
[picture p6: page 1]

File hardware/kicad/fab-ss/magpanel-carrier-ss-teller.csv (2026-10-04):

Tel,Net,Uc A alttan bakis (x | y mm),Uc B alttan bakis (x | y mm),Duz mesafe (mm),Kesim (mm)
W1,HUB_ADDR_E,92.00 | 80.62,92.50 | 57.58,23.0,40
W2,HUB_LAT2,88.40 | 80.62,111.23 | 66.65,26.8,45
W3,HUB_LAT3,128.23 | 60.40,128.23 | 65.38,5.0,20

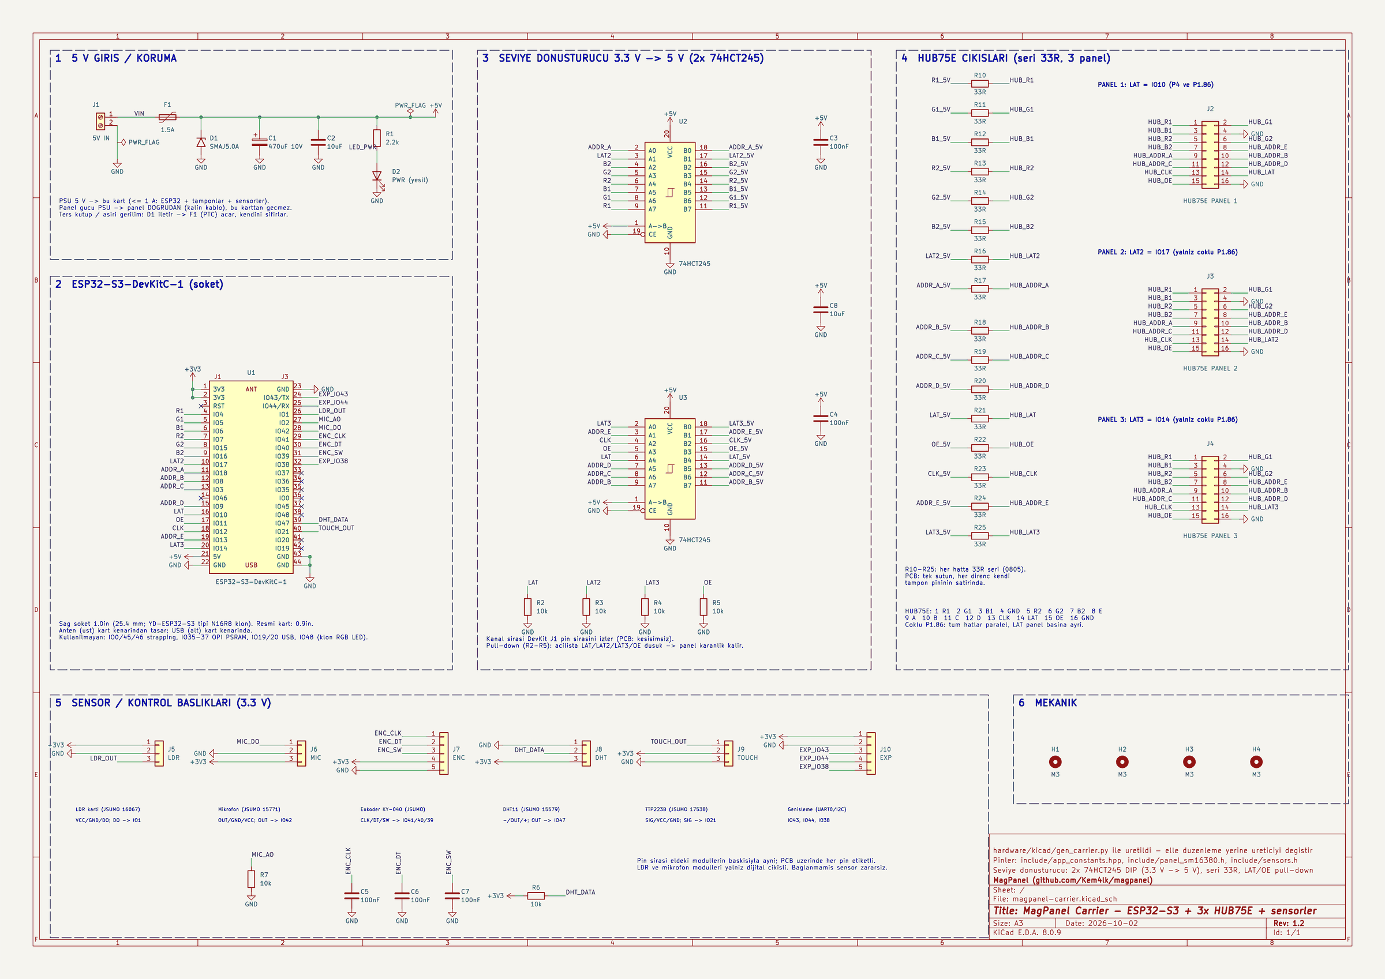
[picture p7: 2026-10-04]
hardware/kicad/img/schematic.png

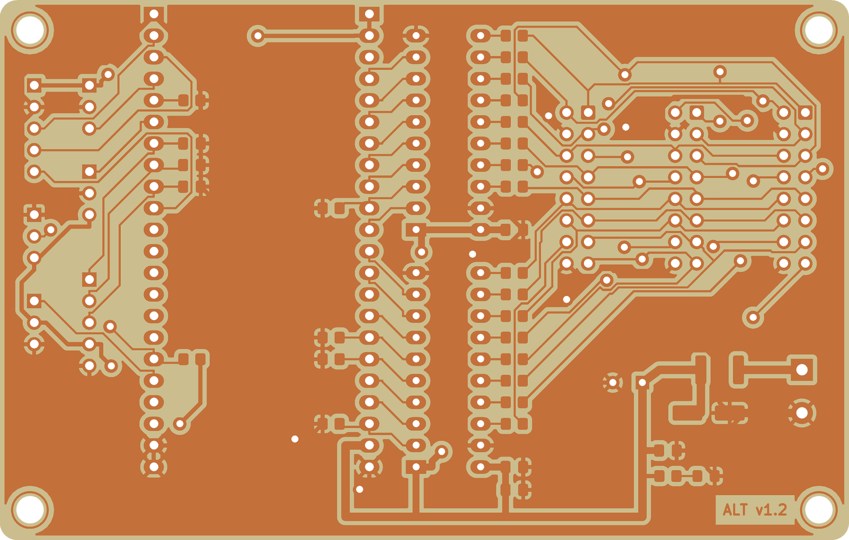
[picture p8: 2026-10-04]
hardware/kicad/img/diy-bottom.png

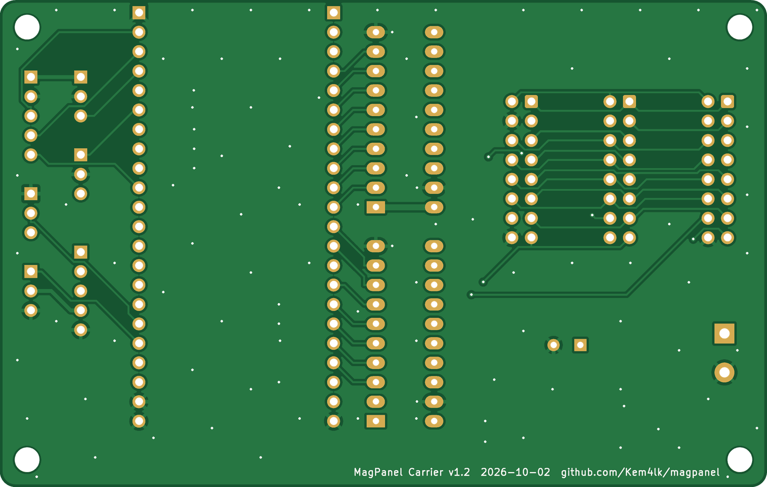
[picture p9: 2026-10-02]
hardware/kicad/img/pcb-bottom.png

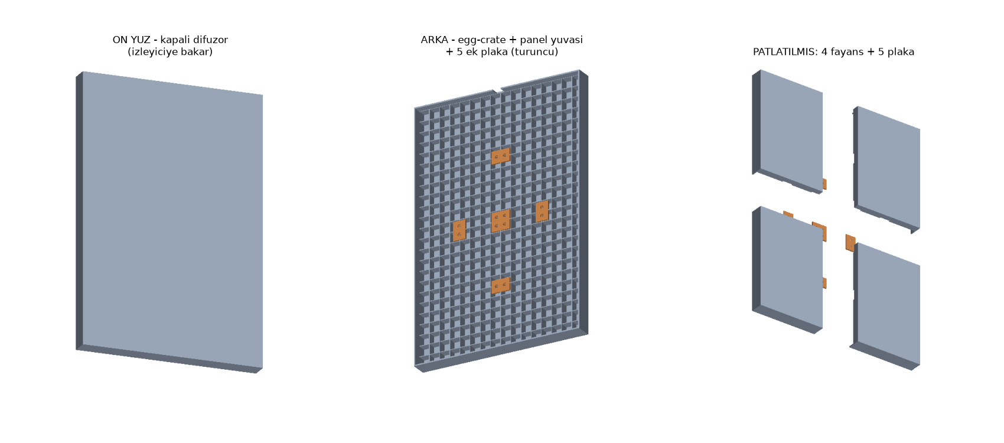
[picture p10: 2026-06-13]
enclosure/preview_hero.png

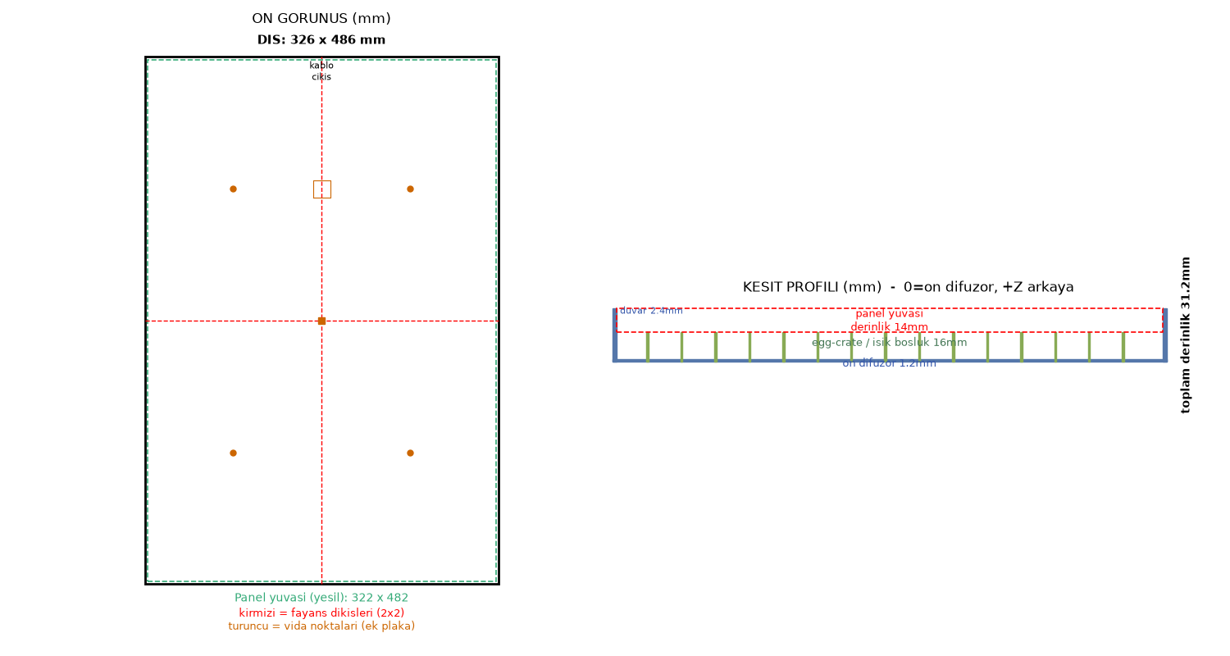
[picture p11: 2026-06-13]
enclosure/dimensions.png

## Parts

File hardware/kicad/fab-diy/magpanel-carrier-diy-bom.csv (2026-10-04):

Ref | Adet | Deger | Footprint | Montaj | Uretici | Parca / MPN | LCSC | Not
C1 | 1 | 470uF 10V | CP_Radial_D8.0mm_P3.50mm | THT |  | Elektrolitik 470 uF 10 V, D8 P3.5 (low ESR) |  | 5 V giris tamponu (kablo enduktansi, tampon anahtarlama akimlari)
C2 | 1 | 10uF | C_0805_2012Metric_Pad1.18x1.45mm_HandSolder | SMD | Samsung | CL21A106KAYNNNE | C15850 | 5 V giris seramik dekuplaj
C3 C4 | 2 | 100nF | C_0805_2012Metric_Pad1.18x1.45mm_HandSolder | SMD | YAGEO | CC0805KRX7R9BB104 | C49678 | 74HCT245 VCC dekuplaj (pin 20 yaninda)
C5 C6 C7 | 3 | 100nF | C_0805_2012Metric_Pad1.18x1.45mm_HandSolder | SMD | YAGEO | CC0805KRX7R9BB104 | C49678 | Enkoder RC debounce (modul 10k + 100nF ~ 1 ms)
C8 | 1 | 10uF | C_0805_2012Metric_Pad1.18x1.45mm_HandSolder | SMD | Samsung | CL21A106KAYNNNE | C15850 | Tamponlar icin yerel 5 V yigin kapasitesi
D1 | 1 | SMAJ5.0A | D_SMA_Handsoldering | SMD | Littelfuse | SMAJ5.0A | C83329 | TVS: ters kutup/asiri gerilimde iletir -> F1 acar
D2 | 1 | PWR (yesil) | LED_0805_2012Metric_Pad1.15x1.40mm_HandSolder | SMD | Hubei KENTO | KT-0805G | C2297 | 5 V var gostergesi
F1 | 1 | 1.5A | Fuse_1812_4532Metric_Pad1.30x3.40mm_HandSolder | SMD | BOURNS | MF-MSMF150-2 | C89648 | Kendini sifirlayan sigorta: asiri akim / ters kutupta (D1 iletir) acar
J1 | 1 | 5V IN | TerminalBlock_Phoenix_MKDS-1,5-2-5.08_1x02_P5.08mm_Horizontal | THT |  | Phoenix MKDS 1,5/2-5,08 (1714955) ya da esdegeri |  | 5 V DC giris (PSU). Panel gucu PSU -> panel dogrudan; bu kart <= 1 A ceker.
J2 | 1 | HUB75E PANEL 1 | IDC-Header_2x08_P2.54mm_Vertical | THT |  | Kutu baslik (box header) 2x8 2.54 mm, duz |  | HUB75E panel cikisi: LAT = IO10 (P4 ve P1.86)
J3 | 1 | HUB75E PANEL 2 | IDC-Header_2x08_P2.54mm_Vertical | THT |  | Kutu baslik (box header) 2x8 2.54 mm, duz |  | HUB75E panel cikisi: LAT2 = IO17 (yalniz coklu P1.86)
J4 | 1 | HUB75E PANEL 3 | IDC-Header_2x08_P2.54mm_Vertical | THT |  | Kutu baslik (box header) 2x8 2.54 mm, duz |  | HUB75E panel cikisi: LAT3 = IO14 (yalniz coklu P1.86)
J5 | 1 | LDR | PinHeader_1x03_P2.54mm_Vertical | THT |  | Pin header 1x3 2.54 mm erkek (Dupont) |  | LDR karti (JSUMO 16067) - VCC/GND/DO; DO -> IO1
J6 | 1 | MIC | PinHeader_1x03_P2.54mm_Vertical | THT |  | Pin header 1x3 2.54 mm erkek (Dupont) |  | Mikrofon (JSUMO 15771) - OUT/GND/VCC; OUT -> IO42
J7 | 1 | ENC | PinHeader_1x05_P2.54mm_Vertical | THT |  | Pin header 1x5 2.54 mm erkek (Dupont) |  | Enkoder KY-040 (JSUMO) - CLK/DT/SW -> IO41/40/39
J8 | 1 | DHT | PinHeader_1x03_P2.54mm_Vertical | THT |  | Pin header 1x3 2.54 mm erkek (Dupont) |  | DHT11 (JSUMO 15579) - -/OUT/+; OUT -> IO47
J9 | 1 | TOUCH | PinHeader_1x03_P2.54mm_Vertical | THT |  | Pin header 1x3 2.54 mm erkek (Dupont) |  | TTP223B (JSUMO 17538) - SIG/VCC/GND; SIG -> IO21
J10 | 1 | EXP | PinHeader_1x05_P2.54mm_Vertical | THT |  | Pin header 1x5 2.54 mm erkek (Dupont) |  | Genisleme (UART0/I2C) - IO43, IO44, IO38
R1 | 1 | 2.2k | R_0805_2012Metric_Pad1.20x1.40mm_HandSolder | SMD | UNI-ROYAL | 0805W8F2201T5E | C17520 | PWR LED akim siniri (~1 mA)
R2 R3 R4 R5 | 4 | 10k | R_0805_2012Metric_Pad1.20x1.40mm_HandSolder | SMD | UNI-ROYAL | 0805W8F1002T5E | C17414 | Pull-down: acilista GPIO surulmezken LAT/OE dusuk -> panel karanlik
R6 | 1 | 10k | R_0805_2012Metric_Pad1.20x1.40mm_HandSolder | SMD | UNI-ROYAL | 0805W8F1002T5E | C17414 | DHT11 DATA pull-up (ciplak sensor icin; modul uzerindekiyle paralel sorun degil)
R7 | 1 | 10k | R_0805_2012Metric_Pad1.20x1.40mm_HandSolder | SMD | UNI-ROYAL | 0805W8F1002T5E | C17414 | IO2 (analog mikrofon girisi) bosta gurultu okumasin: eldeki mikrofon modulu yalniz dijital
R10 R11 R12 R13 R14 R15 R16 R17 R18 R19 R20 R21 R22 R23 R24 R25 | 16 | 33R | R_0805_2012Metric_Pad1.20x1.40mm_HandSolder | SMD | UNI-ROYAL | 0805W8F330JT5E | C17634 | Seri sonlandirma: kablo yansimalarini/zil (ringing) bastirir
U1 | 1 | ESP32-S3-DevKitC-1 | ESP32-S3-DevKitC-1_Socket | THT |  | ESP32-S3 N16R8 klon (YD-ESP32-S3 tipi, siralar arasi 1.0in) + 2x 1x22 disi soket (2.54 mm) |  | ESP32-S3-DevKitC-1 uyumlu gelistirme karti (eldeki: N16R8 klon, 2x USB-C); 2x22 disi soket. Sag sira 1.0in (25.4 mm); resmi Espressif karti 0.9in.
U2 U3 | 2 | 74HCT245 | DIP-20_W7.62mm_Socket_LongPads | THT |  | CD74HCT245E (PDIP-20) + 20 pin DIP soket |  | Octal bus transceiver, HCT = TTL girisli (3.3 V mantik 5 V beslemede gecerli); DIR=+5V (A->B), /OE=GND

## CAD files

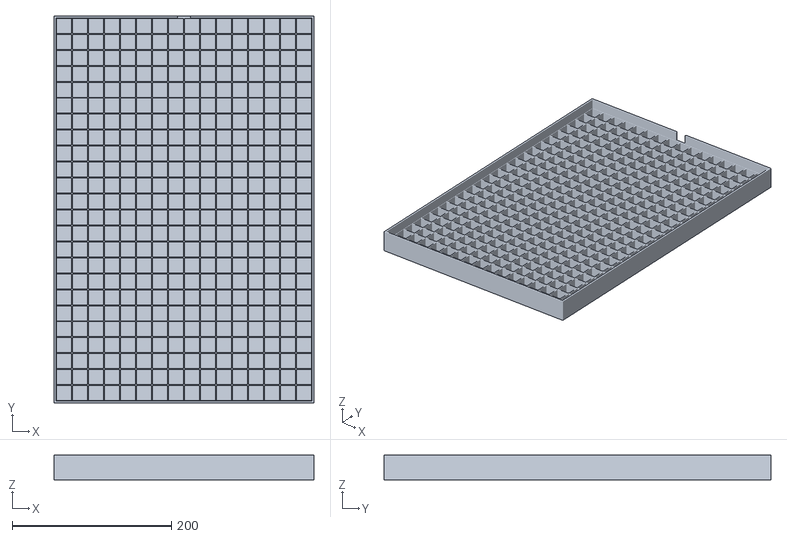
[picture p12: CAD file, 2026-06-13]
enclosure/stl/full_case_1piece.stl
326.3 x 486.3 x 31.2

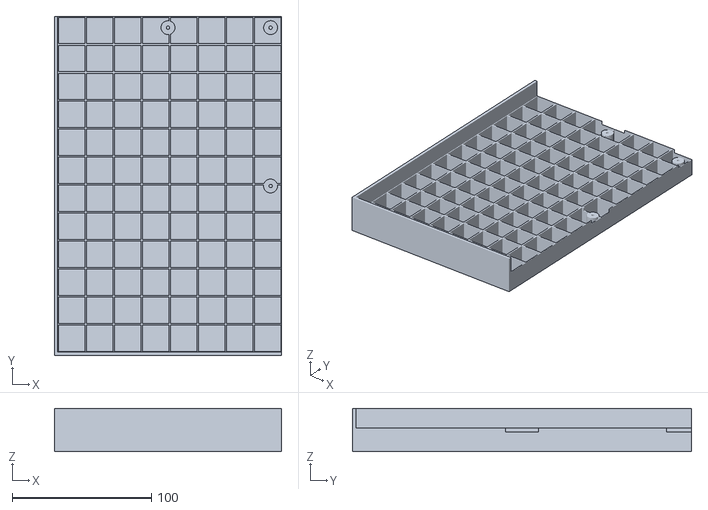
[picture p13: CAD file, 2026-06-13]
enclosure/stl/tile_bottom_left.stl
163.1 x 243.1 x 31.2

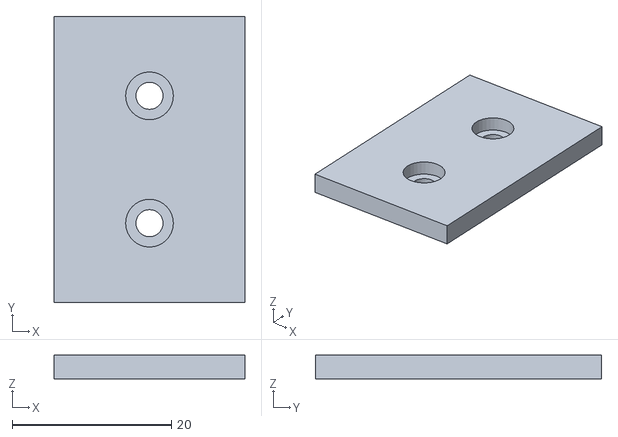
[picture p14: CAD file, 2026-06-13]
enclosure/stl/splice_Hrt.stl
24.0 x 36.0 x 3.00

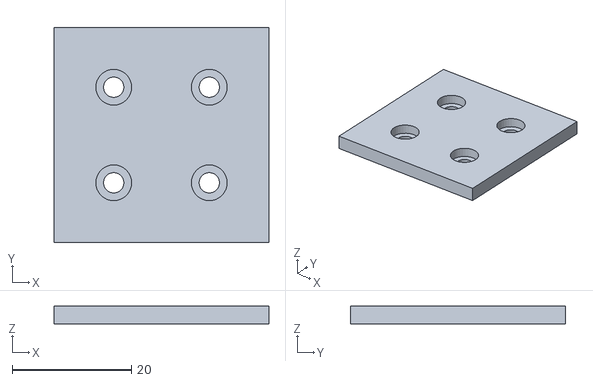
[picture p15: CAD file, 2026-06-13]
enclosure/stl/splice_center.stl
36.0 x 36.0 x 3.00

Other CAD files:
enclosure/stl/tile_top_right.stl
enclosure/stl/tile_bottom_right.stl
enclosure/stl/splice_Hlf.stl
enclosure/stl/splice_Vbot.stl
enclosure/stl/tile_top_left.stl
enclosure/stl/splice_Vtop.stl

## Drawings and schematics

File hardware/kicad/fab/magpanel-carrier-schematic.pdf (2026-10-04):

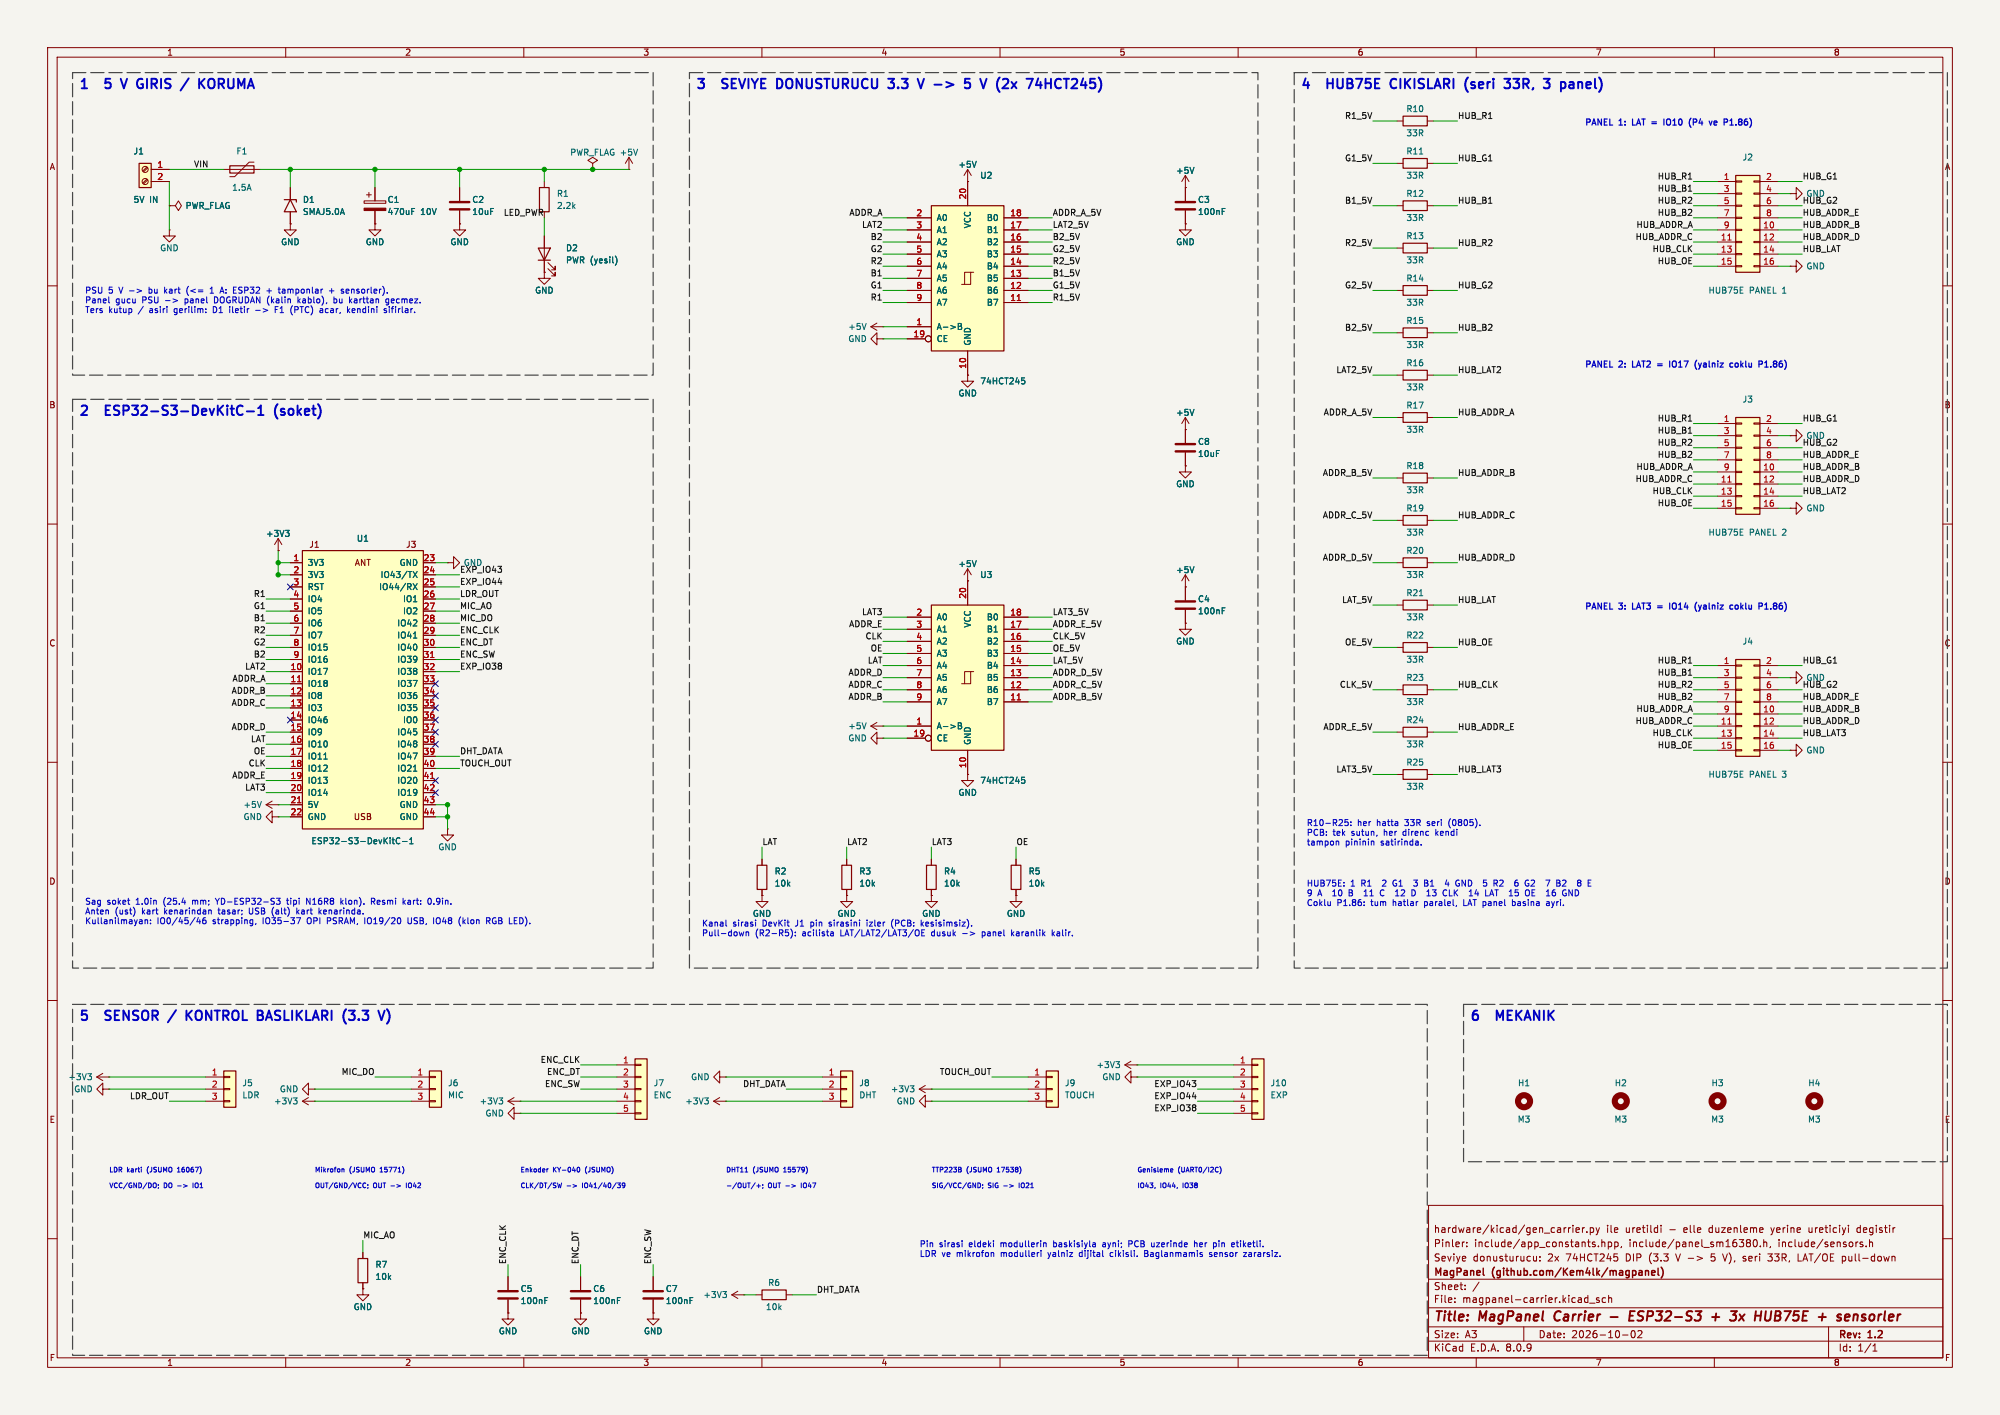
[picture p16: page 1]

9 A 10 B 11 C 12 D 13 CLK 14 LAT 15 OE 16 GND

Seviye donusturucu: | | 2x 74HCT245 | DIP (3.3 V -> include/panel_sm16380.h, | 5 V), seri 33R, | include/sensors.h | LAT/OE pull-down Pinler: include/app_constants.hpp,

+ 3x HUB75E + sensorler File: magpanel-carrier.kicad_sch Sheet: / MagPanel (github.com/Kem4lk/magpanel) Id: 1/1 Title: MagPanel Carrier - ESP32-S3

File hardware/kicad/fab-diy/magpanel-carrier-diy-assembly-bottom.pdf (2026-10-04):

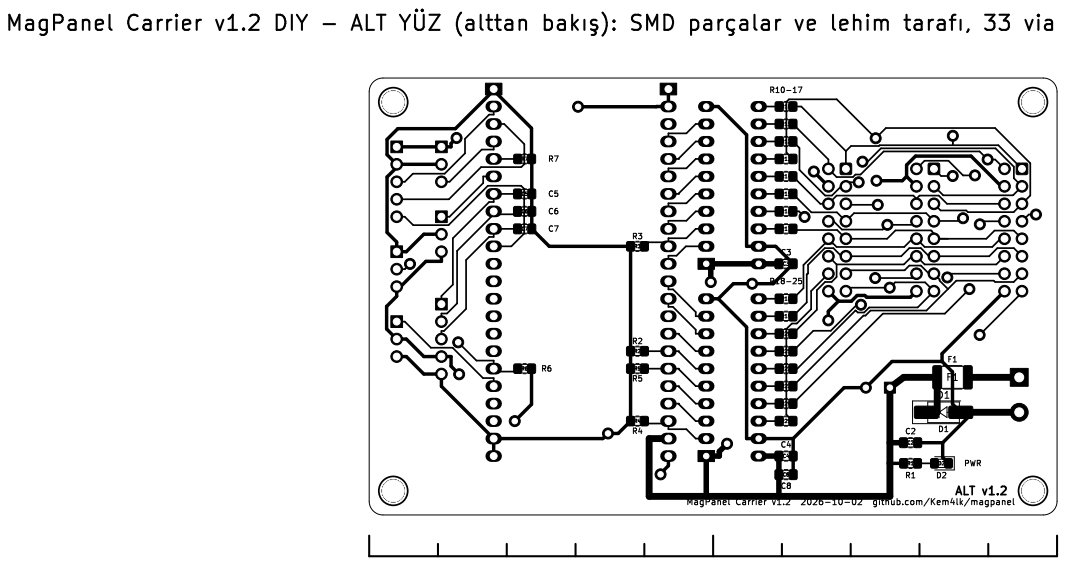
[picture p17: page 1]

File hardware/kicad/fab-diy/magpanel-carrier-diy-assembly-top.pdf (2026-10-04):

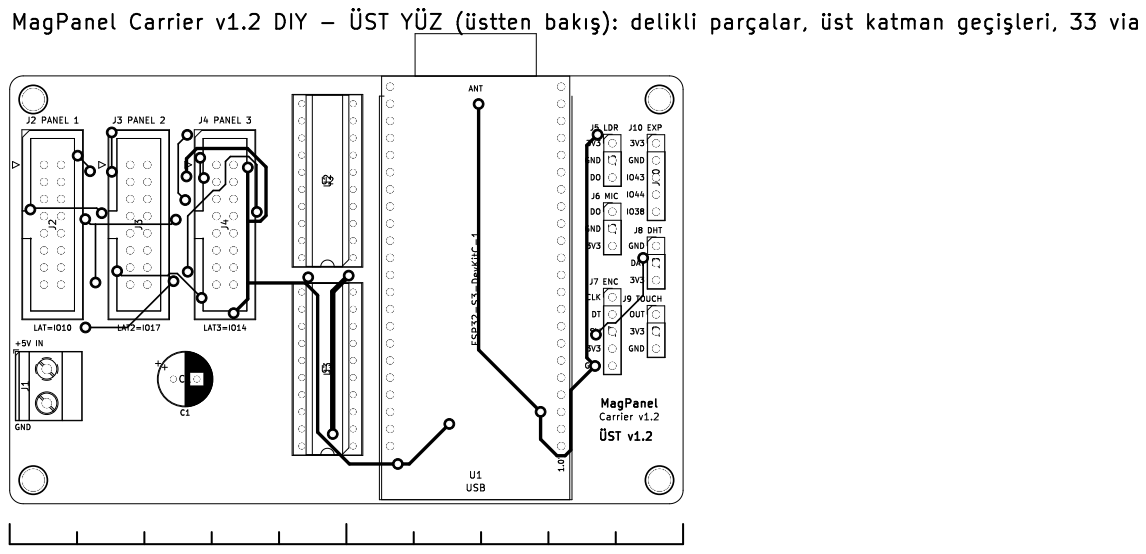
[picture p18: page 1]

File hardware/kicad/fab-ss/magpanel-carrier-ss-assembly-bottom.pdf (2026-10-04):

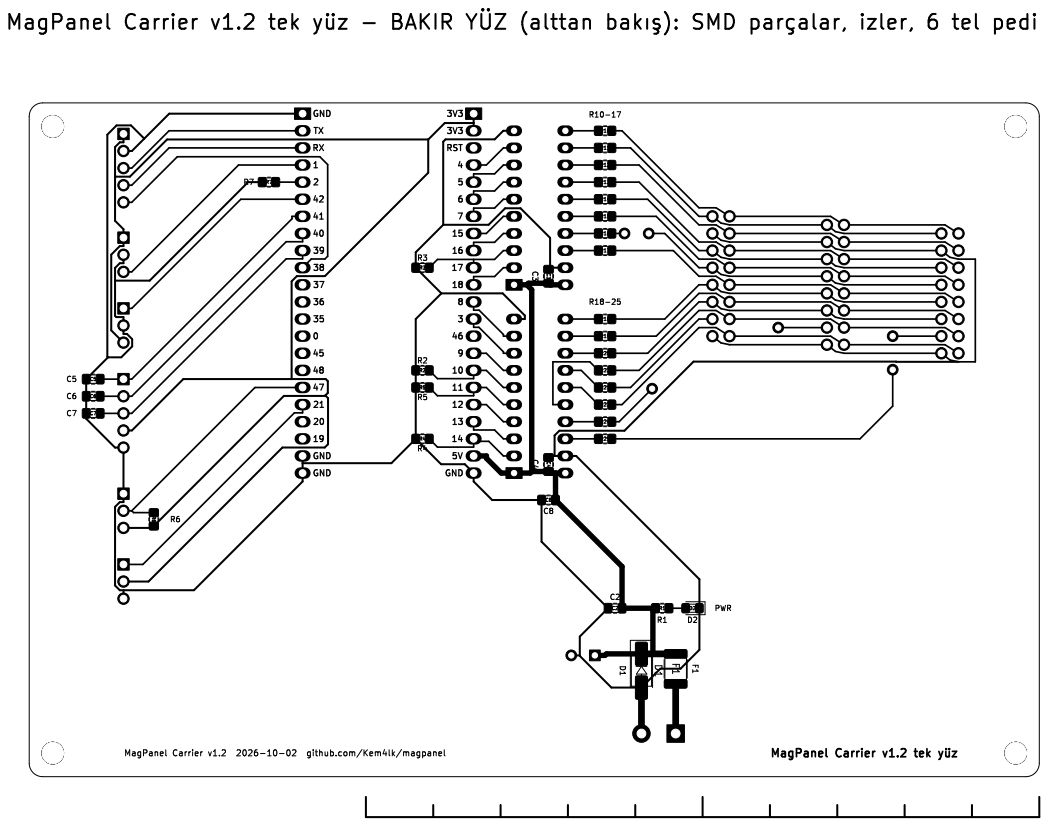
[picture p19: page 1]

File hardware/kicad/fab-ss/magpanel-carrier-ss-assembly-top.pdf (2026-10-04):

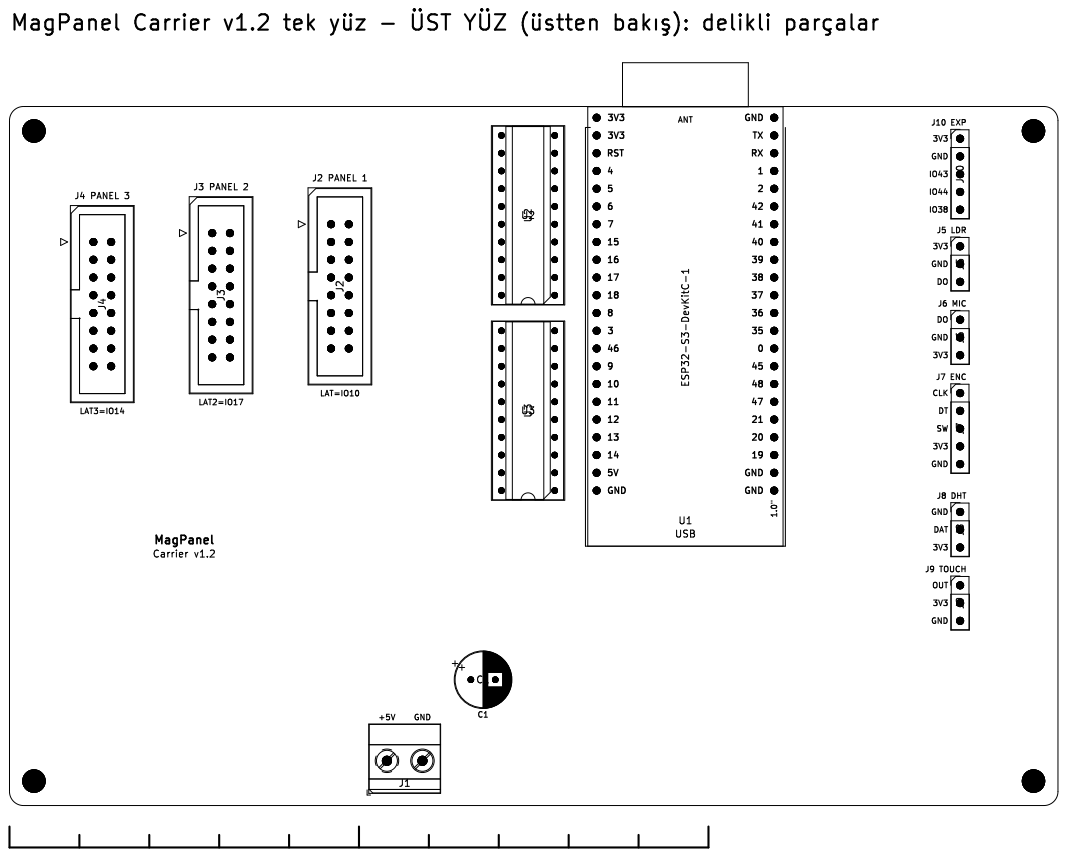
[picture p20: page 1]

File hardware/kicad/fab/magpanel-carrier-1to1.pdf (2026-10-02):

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

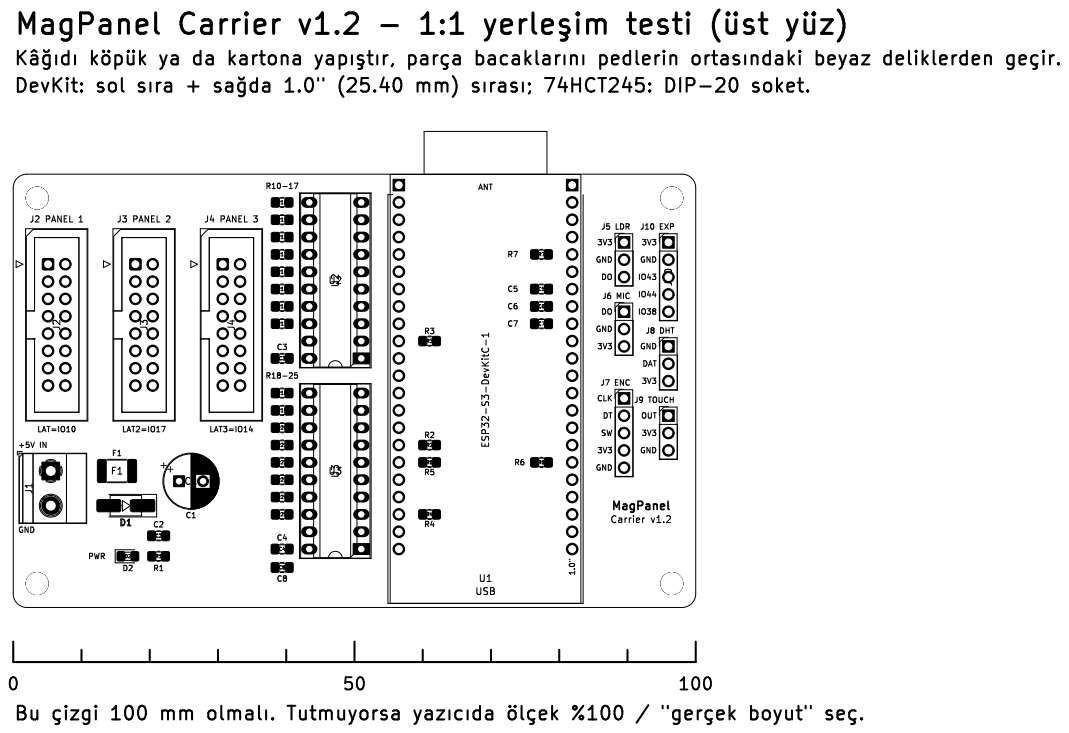
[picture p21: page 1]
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

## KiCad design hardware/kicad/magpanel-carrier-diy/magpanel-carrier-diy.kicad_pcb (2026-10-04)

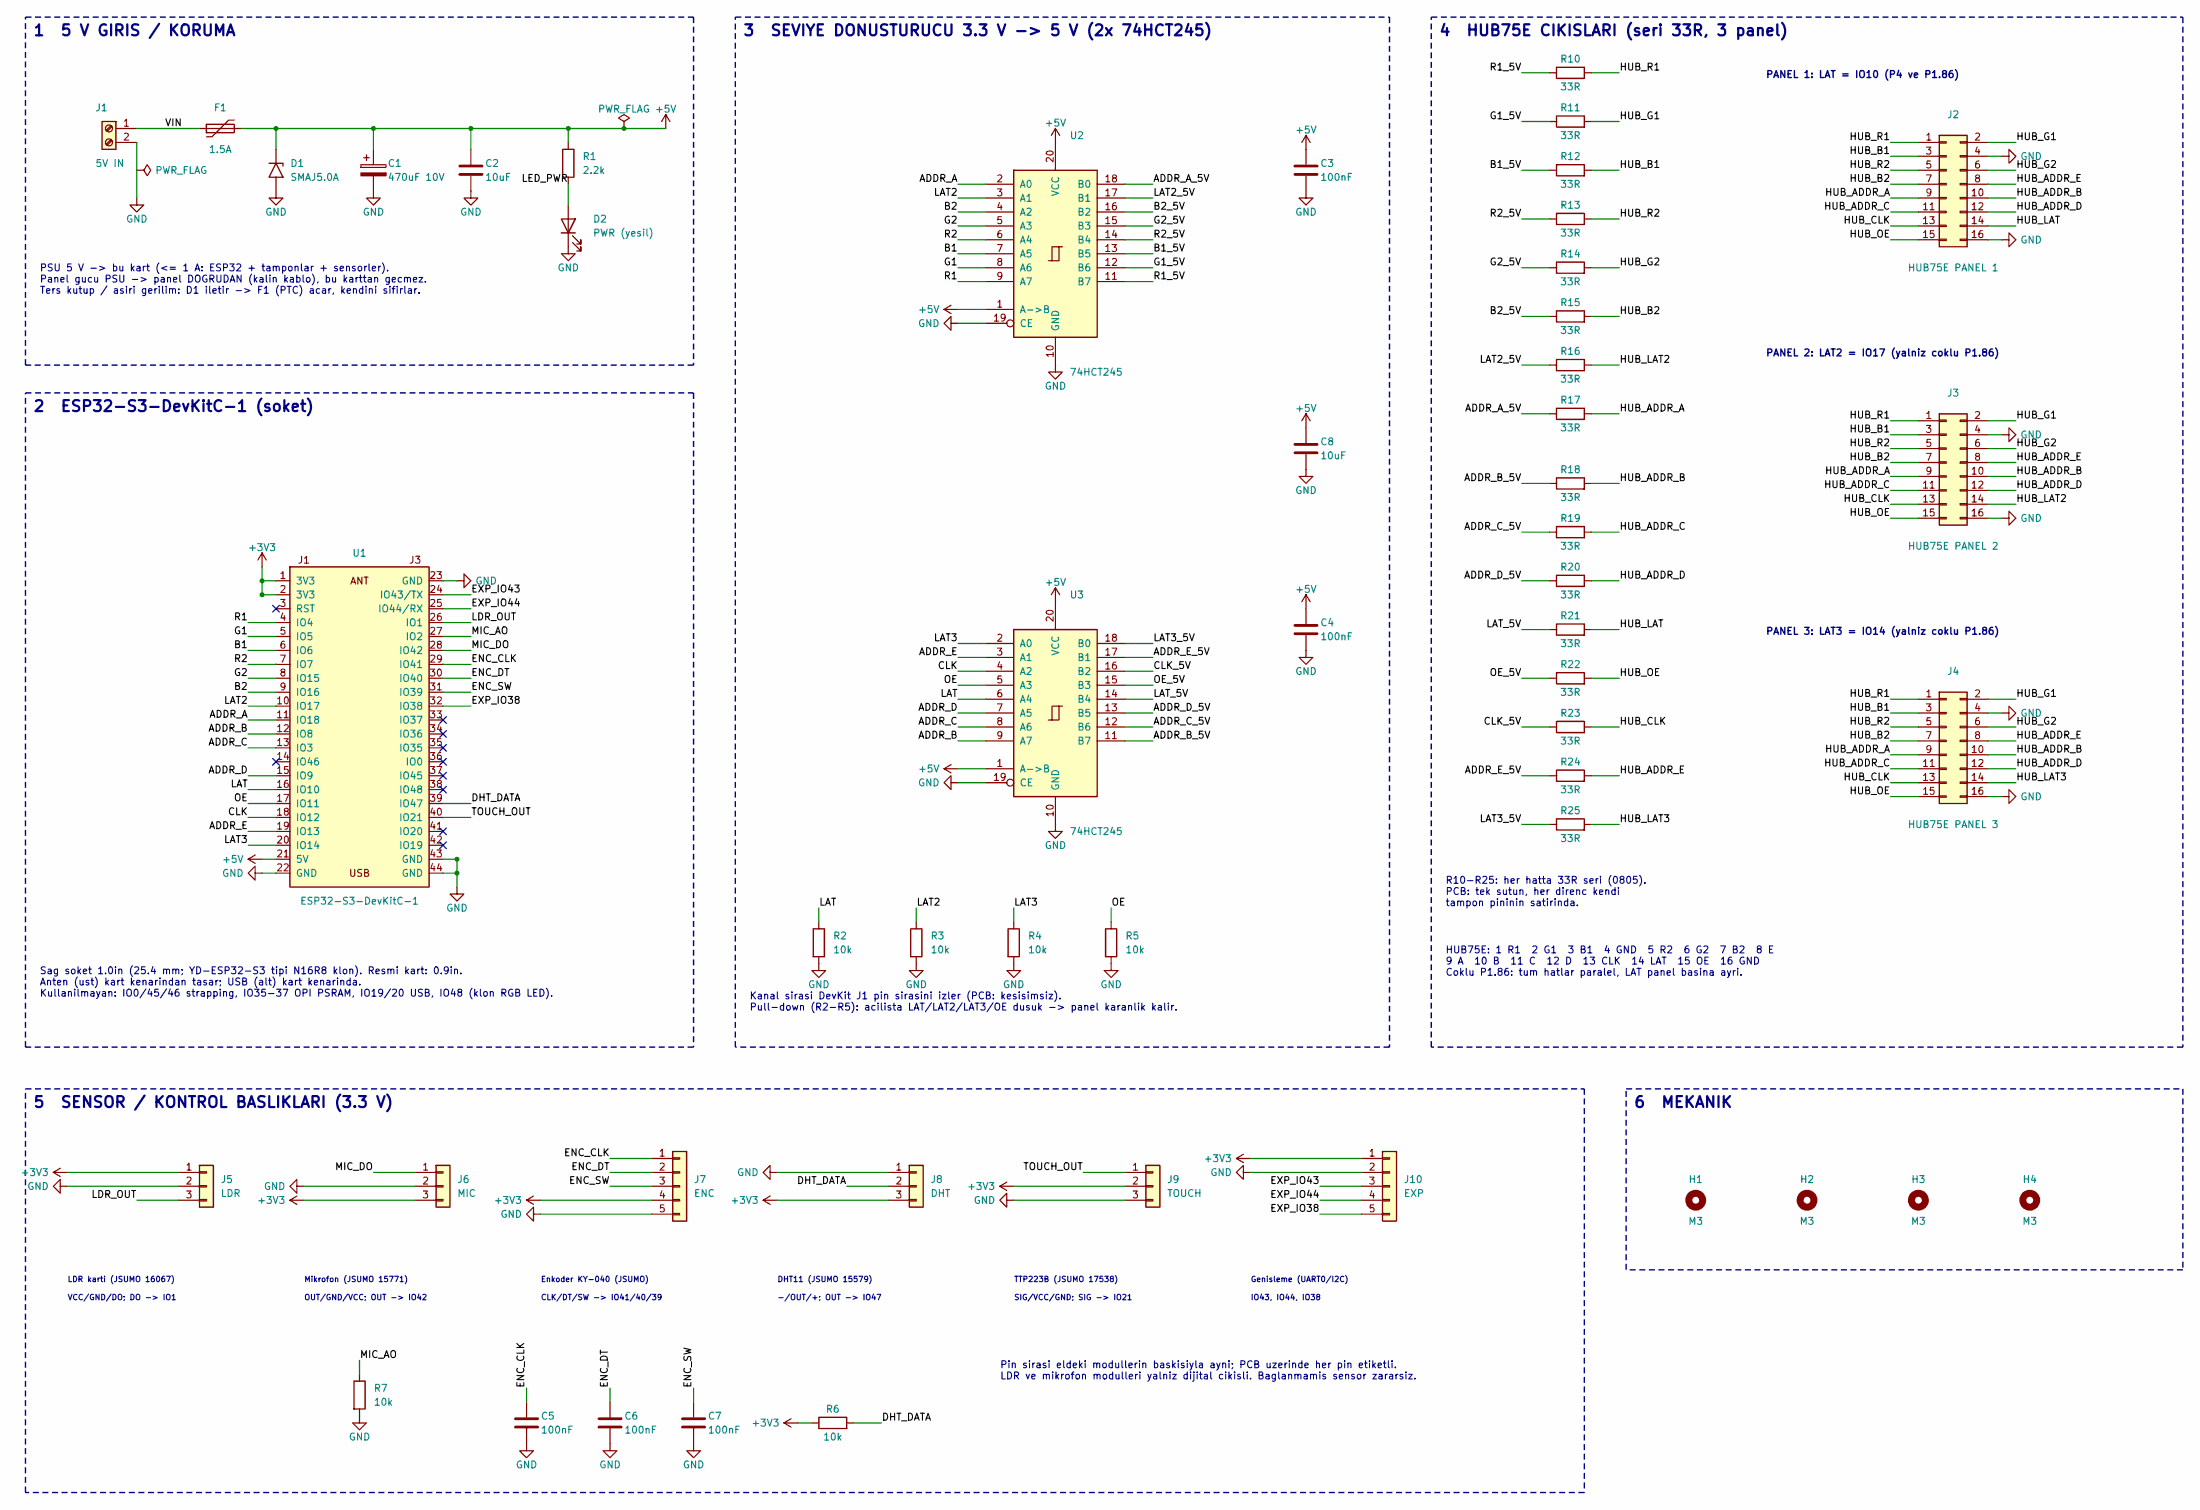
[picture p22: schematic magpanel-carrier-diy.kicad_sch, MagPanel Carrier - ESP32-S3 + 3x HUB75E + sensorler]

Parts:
C1: 470uF 10V; CP_Radial_D8.0mm_P3.50mm; MPN Elektrolitik 470 uF 10 V, D8 P3.5 (low 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
C2, C8: 10uF; C_0805_2012Metric_Pad1.18x1.45mm_HandSolder; MPN CL21A106KAYNNNE; LCSC C15850
C3, C4, C5, C6, C7: 100nF; C_0805_2012Metric_Pad1.18x1.45mm_HandSolder; MPN CC0805KRX7R9BB104; LCSC C49678
D1: SMAJ5.0A; D_SMA_Handsoldering; MPN SMAJ5.0A; LCSC C83329
D2: PWR (yesil); LED_0805_2012Metric_Pad1.15x1.40mm_HandSolder; MPN KT-0805G; LCSC C2297
F1: 1.5A; Fuse_1812_4532Metric_Pad1.30x3.40mm_HandSolder; MPN MF-MSMF150-2; LCSC C89648
H1, H2, H3, H4: M3; MountingHole_3.2mm_M3
J1: 5V IN; TerminalBlock_Phoenix_MKDS-1,5-2-5.08_1x02_P5.08mm_Horizont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; MPN Phoenix MKDS 1,5/2-5,08 (1714955) ya da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
J2: HUB75E PANEL 1; IDC-Header_2x08_P2.54mm_Vertical; MPN Kutu baslik (box header) 2x8 2.54 mm, d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
J3: HUB75E PANEL 2; IDC-Header_2x08_P2.54mm_Vertical; MPN Kutu baslik (box header) 2x8 2.54 mm, d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
J4: HUB75E PANEL 3; IDC-Header_2x08_P2.54mm_Vertical; MPN Kutu baslik (box header) 2x8 2.54 mm, d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
J5: LDR; PinHeader_1x03_P2.54mm_Vertical; MPN Pin header 1x3 2.54 mm erkek (Dupont)
J6: MIC; PinHeader_1x03_P2.54mm_Vertical; MPN Pin header 1x3 2.54 mm erkek (Dupont)
J7: ENC; PinHeader_1x05_P2.54mm_Vertical; MPN Pin header 1x5 2.54 mm erkek (Dupont)
J8: DHT; PinHeader_1x03_P2.54mm_Vertical; MPN Pin header 1x3 2.54 mm erkek (Dupont)
J9: TOUCH; PinHeader_1x03_P2.54mm_Vertical; MPN Pin header 1x3 2.54 mm erkek (Dupont)
J10: EXP; PinHeader_1x05_P2.54mm_Vertical; MPN Pin header 1x5 2.54 mm erkek (Dupont)
R1: 2.2k; R_0805_2012Metric_Pad1.20x1.40mm_HandSolder; MPN 0805W8F2201T5E; LCSC C17520
R2, R3, R4, R5, R6, R7: 10k; R_0805_2012Metric_Pad1.20x1.40mm_HandSolder; MPN 0805W8F1002T5E; LCSC C17414
R10, R11, R12, R13, R14, R15, R16, R17, R18, R19, R20, R21, R22, R23, R24, R25: 33R; R_0805_2012Metric_Pad1.20x1.40mm_HandSolder; MPN 0805W8F330JT5E; LCSC C17634
U1: ESP32-S3-DevKitC-1; ESP32-S3-DevKitC-1_Socket; MPN ESP32-S3 N16R8 klon (YD-ESP32-S3 tipi, 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
U2, U3: 74HCT245; DIP-20_W7.62mm_Socket_LongPads; MPN CD74HCT245E (PDIP-20) + 20 pin DIP soket

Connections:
+3V3: J5.1, J6.3, J7.4, J8.3, J9.2, J10.1, R6.1, U1.1 (3V3), U1.2 (3V3)
+5V: C1.1, C2.1, C3.1, C4.1, C8.1, D1.1 (A1), F1.2, R1.1, U1.21 (5V), U2.1 (A->B), U2.20 (VCC), U3.1 (A->B), U3.20 (VCC)
/ADDR_A: U1.11 (IO18), U2.2 (A0)
/ADDR_A_5V: R17.1, U2.18 (B0)
/ADDR_B: U1.12 (IO8), U3.9 (A7)
/ADDR_B_5V: R18.1, U3.11 (B7)
/ADDR_C: U1.13 (IO3), U3.8 (A6)
/ADDR_C_5V: R19.1, U3.12 (B6)
/ADDR_D: U1.15 (IO9), U3.7 (A5)
/ADDR_D_5V: R20.1, U3.13 (B5)
/ADDR_E: U1.19 (IO13), U3.3 (A1)
/ADDR_E_5V: R24.1, U3.17 (B1)
/B1: U1.6 (IO6), U2.7 (A5)
/B1_5V: R12.1, U2.13 (B5)
/B2: U1.9 (IO16), U2.4 (A2)
/B2_5V: R15.1, U2.16 (B2)
/CLK: U1.18 (IO12), U3.4 (A2)
/CLK_5V: R23.1, U3.16 (B2)
/DHT_DATA: J8.2, R6.2, U1.39 (IO47)
/ENC_CLK: C5.1, J7.1, U1.29 (IO41)
/ENC_DT: C6.1, J7.2, U1.30 (IO40)
/ENC_SW: C7.1, J7.3, U1.31 (IO39)
/EXP_IO38: J10.5, U1.32 (IO38)
/EXP_IO43: J10.3, U1.24 (IO43/TX)
/EXP_IO44: J10.4, U1.25 (IO44/RX)
/G1: U1.5 (IO5), U2.8 (A6)
/G1_5V: R11.1, U2.12 (B6)
/G2: U1.8 (IO15), U2.5 (A3)
/G2_5V: R14.1, U2.15 (B3)
/HUB_ADDR_A: J2.9, J3.9, J4.9, R17.2
/HUB_ADDR_B: J2.10, J3.10, J4.10, R18.2
/HUB_ADDR_C: J2.11, J3.11, J4.11, R19.2
/HUB_ADDR_D: J2.12, J3.12, J4.12, R20.2
/HUB_ADDR_E: J2.8, J3.8, J4.8, R24.2
/HUB_B1: J2.3, J3.3, J4.3, R12.2
/HUB_B2: J2.7, J3.7, J4.7, R15.2
/HUB_CLK: J2.13, J3.13, J4.13, R23.2
/HUB_G1: J2.2, J3.2, J4.2, R11.2
/HUB_G2: J2.6, J3.6, J4.6, R14.2
/HUB_LAT: J2.14, R21.2
/HUB_LAT2: J3.14, R16.2
/HUB_LAT3: J4.14, R25.2
/HUB_OE: J2.15, J3.15, J4.15, R22.2
/HUB_R1: J2.1, J3.1, J4.1, R10.2
/HUB_R2: J2.5, J3.5, J4.5, R13.2
/LAT: R2.1, U1.16 (IO10), U3.6 (A4)
/LAT2: R3.1, U1.10 (IO17), U2.3 (A1)
/LAT2_5V: R16.1, U2.17 (B1)
/LAT3: R4.1, U1.20 (IO14), U3.2 (A0)
/LAT3_5V: R25.1, U3.18 (B0)
/LAT_5V: R21.1, U3.14 (B4)
/LDR_OUT: J5.3, U1.26 (IO1)
/LED_PWR: D2.2 (A), R1.2
/MIC_AO: R7.1, U1.27 (IO2)
/MIC_DO: J6.1, U1.28 (IO42)
/OE: R5.1, U1.17 (IO11), U3.5 (A3)
/OE_5V: R22.1, U3.15 (B3)
/R1: U1.4 (IO4), U2.9 (A7)
/R1_5V: R10.1, U2.11 (B7)
/R2: U1.7 (IO7), U2.6 (A4)
/R2_5V: R13.1, U2.14 (B4)
/TOUCH_OUT: J9.1, U1.40 (IO21)
/VIN: F1.1, J1.1
GND: C1.2, C2.2, C3.2, C4.2, C5.2, C6.2, C7.2, C8.2, D1.2 (A2), D2.1 (K), J1.2, J2.4, J2.16, J3.4, J3.16, J4.4, J4.16, J5.2, J6.2, J7.5, J8.1, J9.3, J10.2, R2.2, R3.2, R4.2, R5.2, R7.2, U1.22 (GND), U1.23 (GND), U1.43 (GND), U1.44 (GND), U2.10 (GND), U2.19 (CE), U3.10 (GND), U3.19 (CE)

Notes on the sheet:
1 5 V GIRIS / KORUMA
PSU 5 V -> bu kart (<= 1 A: ESP32 + tamponlar + sensorler). Panel gucu PSU -> panel DOGRUDAN (kalin kablo), bu karttan gecmez. Ters kutup / asiri gerilim: D1 iletir -> F1 (PTC) acar, kendini sifirlar.
2 ESP32-S3-DevKitC-1 (soket)
Sag soket 1.0in (25.4 mm; YD-ESP32-S3 tipi N16R8 klon). Resmi kart: 0.9in. Anten (ust) kart kenarindan tasar; USB (alt) kart kenarinda. Kullanilmayan: IO0/45/46 strapping, IO35-37 OPI PSRAM, IO19/20 USB, IO48 (klon RGB LED).
3 SEVIYE DONUSTURUCU 3.3 V -> 5 V (2x 74HCT245)
Kanal sirasi DevKit J1 pin sirasini izler (PCB: kesisimsiz). Pull-down (R2-R5): acilista LAT/LAT2/LAT3/OE dusuk -> panel karanlik kalir.
4 HUB75E CIKISLARI (seri 33R, 3 panel)
R10-R25: her hatta 33R seri (0805). PCB: tek sutun, her direnc kendi tampon pininin satirinda.
PANEL 1: LAT = IO10 (P4 ve P1.86)
PANEL 2: LAT2 = IO17 (yalniz coklu P1.86)
PANEL 3: LAT3 = IO14 (yalniz coklu P1.86)
HUB75E: 1 R1 2 G1 3 B1 4 GND 5 R2 6 G2 7 B2 8 E 9 A 10 B 11 C 12 D 13 CLK 14 LAT 15 OE 16 GND Coklu P1.86: tum hatlar paralel, LAT panel basina ayri.
5 SENSOR / KONTROL BASLIKLARI (3.3 V)
LDR karti (JSUMO 16067)
VCC/GND/DO; DO -> IO1
Mikrofon (JSUMO 15771)
OUT/GND/VCC; OUT -> IO42
Enkoder KY-040 (JSUMO)
CLK/DT/SW -> IO41/40/39
DHT11 (JSUMO 15579)
-/OUT/+; OUT -> IO47
TTP223B (JSUMO 17538)
SIG/VCC/GND; SIG -> IO21
Genisleme (UART0/I2C)
IO43, IO44, IO38
Pin sirasi eldeki modullerin baskisiyla ayni; PCB uzerinde her pin etiketli. LDR ve mikrofon modulleri yalniz dijital cikisli. Baglanmamis sensor zararsiz.
6 MEKANIK

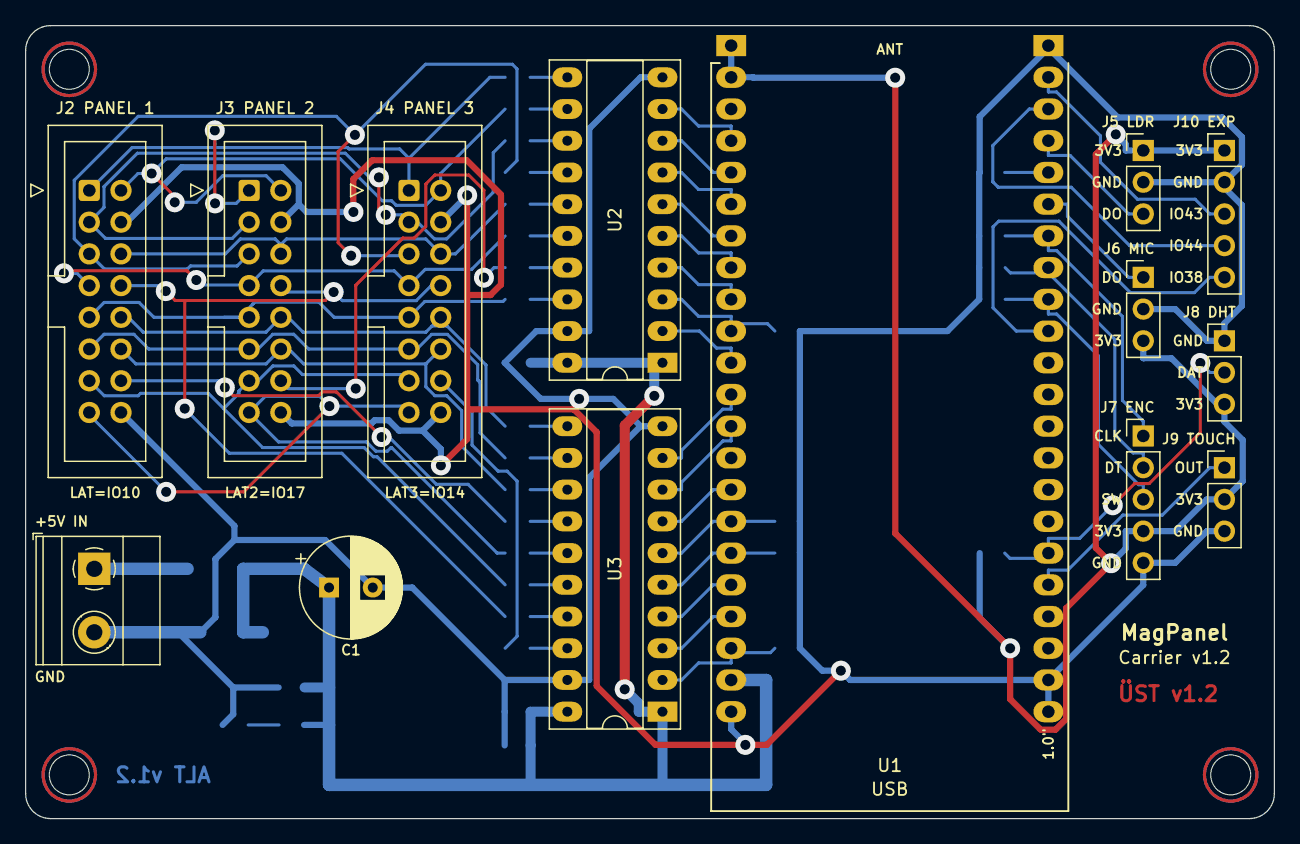
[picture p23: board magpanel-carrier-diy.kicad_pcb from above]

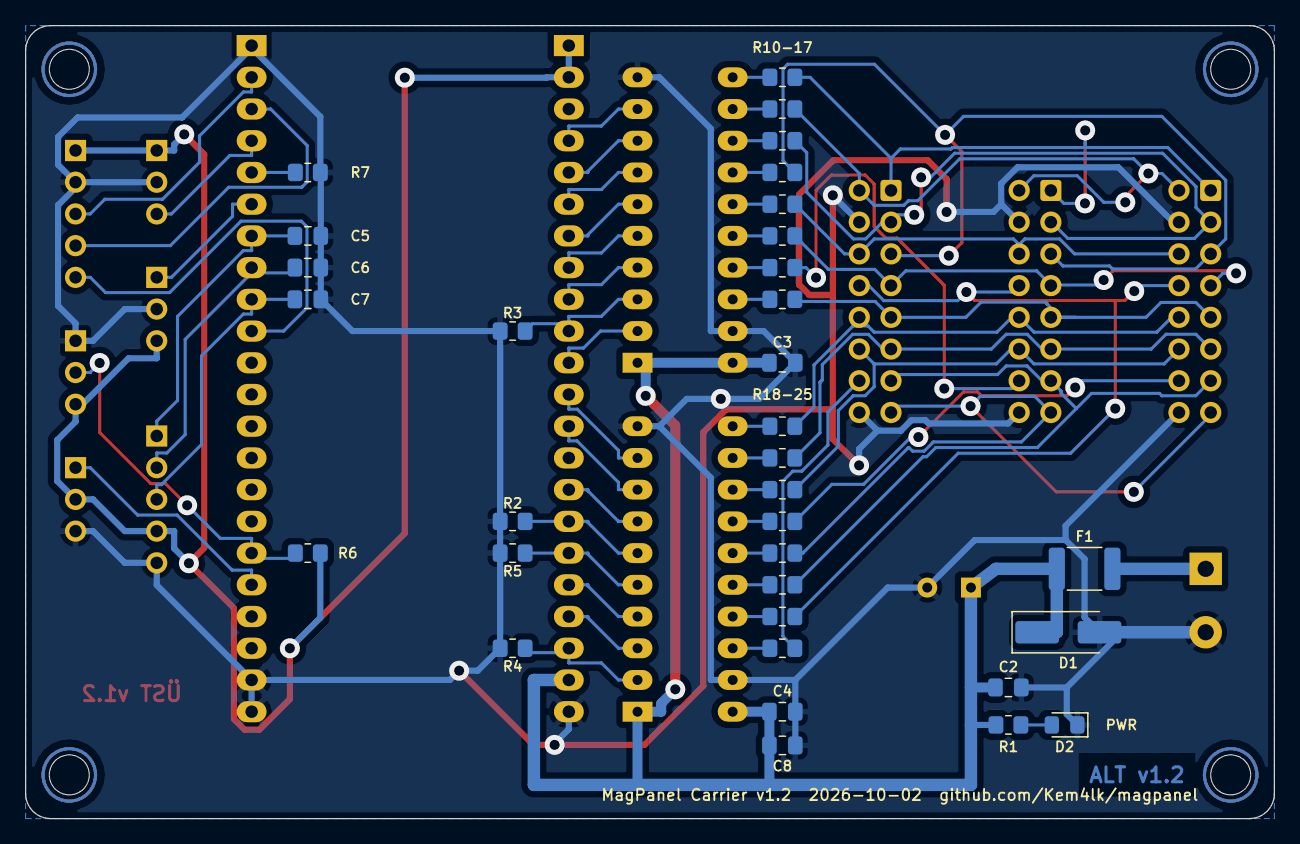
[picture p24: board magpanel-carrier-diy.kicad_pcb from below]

Board: 2 copper layers, 100.0 x 63.5 mm, 51 parts (33 on the bottom side), 64 nets.

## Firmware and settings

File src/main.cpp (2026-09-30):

/* MagPanel - WiFi + WebSocket sunucu. Panel derleme zamaninda secilir (include/panel.h):
   P4 FM6363C 80x120 (varsayilan env'ler) ya da P1.86 SM16380SH 172x86 (-DPANEL_P186).
   Kare boyutu = PANEL_W x PANEL_H; web sayfasi/istemci bunu "D:WxH" WS mesajiyla ogrenir.
   Protokol (binary WS, ilk bayt opcode):
     0x04 + 1B     : global parlaklik (0-255)
     0x05 + 1B     : gomulu galeri tablosu (0..GALLERY_COUNT-1)
     0x06 + 3B     : kanal kazanclari R,G,B (beyaz nokta kalibrasyonu)
     0x07 + 2B     : kontrast, doygunluk (128 = notr)
     0x0E + 1B     : blur kademesi (0=kapalı, 1=2x2, idx≥2 → (2*idx-1) kenarlı box blur, maks 12 = 23x23)
     0x08 + 1B     : mozaik blok boyutu (1=kapali, 2..40)
     0x01 + W*H*3B : tam kare RGB888 (satir-major, y0:x0..W-1); P4 28800B, P1.86 44376B
     0x02 + N*5B   : piksel paketi (x,y,r,g,b)
     0x03          : temizle
     0x0A + 1B     : canli DCLK bolen (flicker tuner)
     0x0B + 1B[+N] : uygulama sec (0=kapat,1=saat,2=timer[+2B sn],3=hava,4=dunyakupasi,5=spotify)
     0x0C + 8B[+s] : hava konumu lat(f32 LE),lon(f32 LE),sehir
     0x0D + s      : Spotify access token (tarayici PKCE)
     0x0F          : flicker self-test baslat/durdur (panelde otomatik desen dizisi)
     0x10 + 2B     : (P1.86) panel duzeni: sayi (1..3), yon (0=alt alta, 1=yan yana) -> NVS + restart
     0x11 + sub..  : sensor/kontrol ayarlari (include/sensors.h): 1=oto parlaklik(on,min,LDR ters)
                     2=eylemler(enkoder bas,uzun bas,dokunmatik,cift alkis) 3=alkis esigi 4=enkoder(adim,ters)
                     -> NVS "sensors"; tum istemcilere "C:" yayini
     0x12 + 1B     : uyku: 0 uyan, 1 uyu, 2 degistir (panel karanlik; icerik/uygulama/ayarlar korunur)
   Firmware -> istemci metin frame'leri: "L:" log, "G:" galeri, "D:" boyut, "C:" sensor ayarlari + parlaklik
     + uyku durumu (baglaninca ve her degisimde), "S:" 1 Hz telemetri (sicaklik/nem/isik/ses/dokunmatik),
     "B:" parlaklik degisti (enkoder cevrilince slider izlesin). Ayni bilgi HTTP: /api/sensors
   Acilista Mona gosterilir; IP seri porta yazilir; http://magpanel.local
   uzerinden gomulu test sayfasi acilir (iOS app ayni protokolu konusur). */
#include <stdarg.h>
#include <WiFi.h>
#include <ESPmDNS.h>
#include <AsyncTCP.h>
#include <ESPAsyncWebServer.h>
#include <ArduinoOTA.h>
#include <HTTPClient.h>
#include <WiFiClientSecure.h>
#include "esp_wifi.h"
#include "esp_log.h"
#include "esp_task_wdt.h"
#include <Update.h>
#include <Preferences.h>
#include "panel.h"
#include "gallery.h"
#include "wifi_config.h"
#include "web_page.h"
#include "apps.h"
#include "sensors.h"

Panel  matrix;                     // P4: Matrix, P1.86: PanelSM16380 (include/panel.h)
Apps   apps;                       // firmware-tarafi uygulamalar (saat/timer/hava/dunya kupasi/spotify/oda/ses)
Sensors sensors;                   // DHT11 / LDR / mikrofon / dokunmatik / enkoder (include/sensors.h)
AsyncWebServer server(80);
AsyncWebSocket ws("/ws");

// ---- AP-modu WiFi Provisioning (USB'siz kablosuz kurulum) ----
// WiFi baglanamazsa panel 'MagPanel-Setup' adli acik bir WiFi agi yayinlar.
// Telefon/laptop o aga baglanir, http://192.168.4.1 acar, yeni SSID+sifre girer.
// Kimlik NVS'e kaydedilir; panel yeniden baslar ve yeni agla baglanir. App gerekmez.
static Preferences prefs;
static volatile bool apSaved = false;
static const char PROV_HTML[] =
  "<!DOCTYPE html><html><head><meta charset=utf-8>"
  "<meta name=viewport content='width=device-width,initial-scale=1'>"
  "<title>MagPanel WiFi Kurulum</title><style>"
  "body{font-family:sans-serif;max-width:420px;margin:32px auto;padding:0 16px}"
  "input{width:100%;padding:11px;margin:6px 0;box-sizing:border-box;font-size:16px}"
  "button{width:100%;padding:13px;margin-top:8px;font-size:16px;background:#06f;color:#fff;border:0;border-radius:8px}"
  "</style></head><body><h2>MagPanel WiFi Kurulum</h2>"
  "<form method=POST action=/save>"
  "<label>WiFi Adi (SSID)</label><input name=ssid required>"
  "<label>Sifre</label><input name=pass type=password>"
  "<button type=submit>Kaydet ve Baglan</button></form></body></html>";

static void runAPProvisioning(){
  Serial.println("WiFi yok - AP modu: 'MagPanel-Setup' agina baglanip http://192.168.4.1 acin");
  for(int y=0;y<PANEL_H;y++) for(int x=0;x<PANEL_W;x++) matrix.drawPixel(x,y,0,0,60);
  matrix.update();

  WiFi.mode(WIFI_AP);
  WiFi.softAP("MagPanel-Setup");
  Serial.printf("AP IP: %s\n", WiFi.softAPIP().toString().c_str());

  static AsyncWebServer apsrv(80);
  apsrv.on("/", HTTP_GET, [](AsyncWebServerRequest *r){
    r->send(200, "text/html", PROV_HTML);
  });
  apsrv.on("/save", HTTP_POST, [](AsyncWebServerRequest *r){
    String ssid, pass;
    if(r->hasParam("ssid", true)) ssid = r->getParam("ssid", true)->value();
    if(r->hasParam("pass", true)) pass = r->getParam("pass", true)->value();
    if(ssid.length()){
      prefs.begin("wificfg", false);
      prefs.putString("ssid", ssid);
      prefs.putString("pass", pass);
      prefs.end();
      r->send(200, "text/html",
        "<meta charset=utf-8><h2>Kaydedildi. Panel yeniden baslatiliyor...</h2>");
      apSaved = true;
    } else r->send(400, "text/plain", "SSID bos olamaz");
  });
  apsrv.begin();

  while(true){                       // kayit gelene kadar AP'de bekle (panel mavi)
    matrix.refresh(); delay(20);
    if(apSaved){ delay(1000); ESP.restart(); }
  }
}

// ---- Kablosuz log: seri + WebSocket'e ayni anda yazar, son satirlari tamponlar ----
#define LOG_LINES 50
#define LOG_LINE_LEN 120
static char     logBuf[LOG_LINES][LOG_LINE_LEN];
static uint8_t  logHead = 0;     // siradaki yazilacak slot
static uint8_t  logCount = 0;    // dolu slot sayisi
static void logf(const char *fmt, ...){
  char line[LOG_LINE_LEN];
  va_list ap; va_start(ap, fmt);
  vsnprintf(line, sizeof(line), fmt, ap);
  va_end(ap);
  Serial.println(line);                                  // her zaman seri porta
  strncpy(logBuf[logHead], line, LOG_LINE_LEN-1);
  logBuf[logHead][LOG_LINE_LEN-1]=0;
  logHead = (logHead+1) % LOG_LINES;
  if(logCount < LOG_LINES) logCount++;
  // canli izleyenlere yayinla (metin frame, "L:" onekli)
  if(ws.count()){
    String msg = "L:"; msg += line;
    ws.textAll(msg);
  }
}
// Yeni baglanan istemciye gecmis loglari sirayla gonder
static void sendLogHistory(AsyncWebSocketClient *c){
  uint8_t idx = (logHead + LOG_LINES - logCount) % LOG_LINES;
  for(uint8_t i=0;i<logCount;i++){
    String msg = "L:"; msg += logBuf[idx];
    c->text(msg);
    idx = (idx+1) % LOG_LINES;
  }
}
// Galeri isimlerini WS metin frame'i olarak gonder ("G:" onekli JSON dizi).
// Boylece tarayici ayri bir /api/gallery HTTP baglantisi acmaz (dusuk heap'te
// yeni TCP soketi ayrilamayip ERR_TIMED_OUT olmasini onler); zaten acik olan
// WebSocket uzerinden gelir.
static void sendGallery(AsyncWebSocketClient *c){
  String j = "G:[";
  for(int i=0; i<GALLERY_COUNT; i++){
    if(i) j += ",";
    j += "\""; j += GALLERY_NAMES[i]; j += "\"";
  }
  j += "]";
  c->text(j);
}
// Panel boyutu + tipi ("D:172x86:P1.86"): istemci kanvasi ve kare boyutunu buna gore kurar
static void sendDims(AsyncWebSocketClient *c){
  char d[40]; snprintf(d, sizeof(d), "D:%dx%d:%s:%d:%d", PANEL_W, PANEL_H, PANEL_NAME, PANEL_COUNT, PANEL_LAYOUT);
  c->text(d);
}
static int8_t lastGallery = 0;   // kazanc degisince yeniden cizim icin
static uint8_t mosaicBlock = 1;  // 1 = tam cozunurluk; N = NxN blok mozaik
static volatile bool otaActive = false;
static volatile uint32_t lastOtaActivity = 0;   // OTA ilerleme zaman damgasi (takilma kurtarma icin)
static volatile bool otaNowRequested = false;    // 0x09 WS opcode: manuel GitHub OTA tetikle
// ---- Uyku + parlaklik durumu (sensors.h olaylari ve 0x04/0x11/0x12 kullanir) ----
static bool     standby     = false;   // uyku: panel karanlik, icerik/uygulama/ayarlar korunur
static uint8_t  userBri     = 110;     // kullanicinin istedigi parlaklik (slider/enkoder); NVS "bri"
static uint32_t briDirty    = 0;       // !=0: userBri NVS'e yazilacak (3 sn debounce, asinma olmasin)
static uint32_t lastAutoBri = 0;       // oto parlaklik son uygulama zamani
#ifndef FW_BUILD
#define FW_BUILD 0
#endif
void drawGallery(uint8_t idx);
void renderFrame();
void redrawCurrent();

#if defined(PANEL_P186)
// P1.86: boyut panel sayisi/duzenine bagli (setup'ta NVS'ten) -> tamponlar PSRAM'de,
// setup'ta ayrilir (1 panel 2 x ~44 KB, 3 panel 2 x ~133 KB); dahili RAM WiFi/async icin kalsin
static size_t FRAME_BYTES = 0;
static size_t RXBUF_BYTES = 0;
static uint8_t *rxbuf    = nullptr;
static uint8_t *framebuf = nullptr;              // son gosterilen kare (ayar degisiminde yeniden cizim)
#else
static const size_t FRAME_BYTES = (size_t)PANEL_W * PANEL_H * 3;  // 28800
static const size_t RXBUF_BYTES = 1 + FRAME_BYTES;
static uint8_t rxbuf[RXBUF_BYTES];
static uint8_t framebuf[FRAME_BYTES];           // son gosterilen kare (ayar degisiminde yeniden cizim)
#endif
static bool    haveFrame = false;
static volatile size_t  msgLen   = 0;
static volatile bool    msgReady = false;

// framebuf'tan (x,y) pikselinin blur uygulanmis rengini dondurur.
// img_blur bir kademe indeksidir: 0=kapalı, 1=2x2, idx≥2 → yarıçap=idx-1
// simetrik box blur ((2*idx-1) kenarlı). Maks 12 (23x23). 2x2 asimetrik
// (piksel + sağ + alt + sağ-alt), digerleri simetrik box blur.
static inline void blurredPixel(int x, int y, uint8_t &ro, uint8_t &go, uint8_t &bo){
  int idx = matrix.img_blur;
  if(idx == 0){
    const uint8_t *p = framebuf + (y*PANEL_W+x)*3;
    ro=p[0]; go=p[1]; bo=p[2]; return;
  }
  int x0,x1,y0,y1;
  if(idx == 1){                 // 2x2: piksel + sağ + alt + sağ-alt
    x0 = x;     x1 = x+1;
    y0 = y;     y1 = y+1;
  } else {                      // simetrik box blur, yarıçap = idx-1
    int r = idx - 1;
    x0 = x-r;   x1 = x+r;
    y0 = y-r;   y1 = y+r;
  }
  uint32_t sr=0,sg=0,sb=0,cnt=0;
  for(int ny=y0; ny<=y1; ny++){
    int cy = ny<0 ? 0 : (ny>=PANEL_H ? PANEL_H-1 : ny);
    for(int nx=x0; nx<=x1; nx++){
      int cx = nx<0 ? 0 : (nx>=PANEL_W ? PANEL_W-1 : nx);
      const uint8_t *q = framebuf + (cy*PANEL_W+cx)*3;
      sr+=q[0]; sg+=q[1]; sb+=q[2]; cnt++;
    }
  }
  ro=(uint8_t)(sr/cnt); go=(uint8_t)(sg/cnt); bo=(uint8_t)(sb/cnt);
}

void renderFrame(){
  uint8_t b = mosaicBlock < 1 ? 1 : mosaicBlock;
  if(b == 1){
    // Doldurma (drawPixel) saf CPU ve hizli (~1ms). Araya refresh() koymak
    // onceki kareyi parlak gosterip update()'in 30ms'lik dim sweep'iyle KONTRAST
    // yaratiyordu (flicker'i artiriyordu) + kare hizini dusuruyordu. Kaldirildi:
    // sadece doldur, sonra tek update().
    for(int y=0;y<PANEL_H;y++)
      for(int x=0;x<PANEL_W;x++){
        uint8_t r,g,bl; blurredPixel(x,y,r,g,bl);
        matrix.drawPixel((uint8_t)x,(uint8_t)y,r,g,bl);
      }
  } else {
    // NxN bloklara bol, her blogun ortalama rengini tum bloga yaz
    for(int by=0; by<PANEL_H; by+=b){
      for(int bx=0; bx<PANEL_W; bx+=b){
        uint32_t sr=0,sg=0,sb=0,cnt=0;
        for(int dy=0; dy<b && by+dy<PANEL_H; dy++)
          for(int dx=0; dx<b && bx+dx<PANEL_W; dx++){
            const uint8_t *q = framebuf + ((by+dy)*PANEL_W + (bx+dx))*3;
            sr+=q[0]; sg+=q[1]; sb+=q[2]; cnt++;
          }
        uint8_t r=sr/cnt, g=sg/cnt, bl=sb/cnt;
        for(int dy=0; dy<b && by+dy<PANEL_H; dy++)
          for(int dx=0; dx<b && bx+dx<PANEL_W; dx++)
            matrix.drawPixel((uint8_t)(bx+dx),(uint8_t)(by+dy),r,g,bl);
      }
    }
  }
  matrix.update();                                     // tek latch: dim sweep'i bir kez yap
}
// Parlaklik/kazanc/kontrast degisince panel kendi icerigini yeniden cizer -
// istemcinin (bos olabilecek) kanvasini yeniden gondermesine gerek kalmaz.
void redrawCurrent(){
  if(standby) return;                              // uykuda cizme; setStandby(false) uyaninca cizer
  if(lastGallery>=0) drawGallery((uint8_t)lastGallery);
  else if(haveFrame) renderFrame();
}
// Galeri tablolari 80x120 (dikey) saklanir. Panel farkli boyuttaysa (P1.86 172x86)
// en-boy korunarak sigdirilir (bilinear), kenarlar siyah.
static const int GAL_W = 80, GAL_H = 120;
static void loadGalleryFrame(const uint8_t *src){
  if(PANEL_W == GAL_W && PANEL_H == GAL_H){ memcpy(framebuf, src, FRAME_BYTES); return; }
  memset(framebuf, 0, FRAME_BYTES);
  // olcek = min(PW/GW, PH/GH): sinirlayan kenar tam dolar, digeri yuvarlanir
  int dw, dh;
  if(PANEL_W * GAL_H <= PANEL_H * GAL_W){ dw = PANEL_W; dh = (GAL_H * PANEL_W + GAL_W/2) / GAL_W; }
  else                                  { dh = PANEL_H; dw = (GAL_W * PANEL_H + GAL_H/2) / GAL_H; }
  int ox = (PANEL_W - dw) / 2, oy = (PANEL_H - dh) / 2;
  for(int y=0; y<dh; y++){
    uint32_t fy = (uint32_t)(((uint64_t)y << 16) * (GAL_H - 1) / (dh > 1 ? dh - 1 : 1));
    int y0 = fy >> 16, y1 = y0 + 1 < GAL_H ? y0 + 1 : y0; uint32_t wy = (fy >> 8) & 0xff;
    for(int x=0; x<dw; x++){
      uint32_t fx = (uint32_t)(((uint64_t)x << 16) * (GAL_W - 1) / (dw > 1 ? dw - 1 : 1));
      int x0 = fx >> 16, x1 = x0 + 1 < GAL_W ? x0 + 1 : x0; uint32_t wx = (fx >> 8) & 0xff;
      uint8_t *d = framebuf + ((oy + y) * PANEL_W + (ox + x)) * 3;
      for(int c=0; c<3; c++){
        uint32_t a = pgm_read_byte(src + (y0*GAL_W + x0)*3 + c), b = pgm_read_byte(src + (y0*GAL_W + x1)*3 + c);
        uint32_t e = pgm_read_byte(src + (y1*GAL_W + x0)*3 + c), f = pgm_read_byte(src + (y1*GAL_W + x1)*3 + c);
        uint32_t top = a*(256-wx) + b*wx, bot = e*(256-wx) + f*wx;
        d[c] = (uint8_t)((top*(256-wy) + bot*wy) >> 16);
      }
    }
  }
}
void drawGallery(uint8_t idx){
  if(idx>=GALLERY_COUNT) return;
  loadGalleryFrame(GALLERY_DATA[idx]);               // galeriyi framebuf'a al (gerekirse olcekle)
  haveFrame = true;
  renderFrame();                                     // mozaik dahil ortak render
  logf("Galeri: %s", GALLERY_NAMES[idx]);
}

// ===================== FLICKER SELF-TEST (opcode 0x0F) =====================
// Panelin flicker karakterini bir VIDEO ile teshis/kalibre etmek icin otomatik
// desen dizisi. Her faz panelin SOL-UST kosesine "Pxx kod" etiketi cizer (videoda
// hangi fazda oldugumuzu okuruz) ve web LOG'a faz adini yazar.
//   * STATIK fazlar TEK kare cizilir: surekli circular-DMA paneli flicker'siz
//     tutar -> goz/kamera SADECE saf refresh / PWM (dusuk-duty) flicker'ini ve
//     guc cokmesini gorur (update() basina olusan dim-sweep KARISMAZ).
//   * HAREKETLI fazlar her tik (~25fps) yeniden cizilir -> her update()'in
//     dim-sweep'i, yani ANIMASYON flicker'i gorunur.
//   * DCLK-SWEEP fazlari boleni 80..16 gezer (UI tuner kademeleri). Videodan
//     en az flicker + henuz mozaik/bozulma BASLAMAMIS kademe secilir = kalibrasyon.
// Test sirasinda goruntu hatti notr'e cekilir (kontrast/doygunluk/kazanc/mozaik/
// blur sifirlanir) ki sonuc kalintı ayarlardan etkilenmesin; bitince hepsi +
// DCLK boleni geri yuklenir.
enum { FT_SOLID, FT_HGRAD, FT_VGRAD, FT_HALVES, FT_HLINES, FT_VLINES,
       FT_CHECKER, FT_DIAG, FT_BLINK, FT_SCROLL, FT_PULSE };
struct FtPhase { uint16_t dur; uint8_t kind; uint8_t bright; uint8_t div;
                 uint8_t a, b, c; const char *code; };
// dur(ms), kind, bright(0=baz 160), div(0=baz/NVS), a,b,c(renk/param), etiket
static const FtPhase FT_SEQ[] = {
  {4000, FT_BLINK,   0,   0, 255,255,255, "BLINK2Hz"},  // zaman referansi (videodaki fps dogrulama)
  {2500, FT_SOLID,   0,   0, 255,255,255, "WHT"},       // saf beyaz (refresh + guc)
  {2500, FT_SOLID,   0,   0, 255,  0,  0, "RED"},
  {2500, FT_SOLID,   0,   0,   0,255,  0, "GRN"},
  {2500, FT_SOLID,   0,   0,   0,  0,255, "BLU"},
  {2500, FT_SOLID,   0,   0, 128,128,128, "GRY128"},
  {2500, FT_SOLID,   0,   0,  48, 48, 48, "GRY48"},     // dusuk-duty PWM flicker
  {2500, FT_SOLID,   0,   0,  16, 16, 16, "GRY16"},     // cok dusuk-duty (en zor)
  {2500, FT_SOLID, 255,   0, 255,255,255, "WHT-MAX"},   // tam guc -> brownout/sag testi
  {2500, FT_HGRAD,   0,   0,   0,  0,  0, "HGRAD"},      // yatay gradyan -> kolon/DCLK bant
  {2500, FT_VGRAD,   0,   0,   0,  0,  0, "VGRAD"},      // dikey gradyan -> satir bant
  {2500, FT_HALVES,  0,   0,   0,  0,  0, "HALVES"},     // ust/alt yari (iki-tarama siniri)
  {2500, FT_HLINES,  0,   0,   1,  0,  0, "HLINES"},     // 1px yatay cizgi -> satir flicker yukseltici
  {2500, FT_VLINES,  0,   0,   1,  0,  0, "VLINES"},     // 1px dikey cizgi -> DCLK yukseltici
  {2500, FT_CHECKER, 0,   0,   2,  0,  0, "CHECK2"},
  {2500, FT_DIAG,    0,  80,   0,  0,  0, "d80"},        // ---- DCLK sweep: ~2.0 MHz
  {2500, FT_DIAG,    0,  64,   0,  0,  0, "d64"},        //      ~2.5 MHz (varsayilan)
  {2500, FT_DIAG,    0,  53,   0,  0,  0, "d53"},        //      ~3.0
  {2500, FT_DIAG,    0,  46,   0,  0,  0, "d46"},        //      ~3.5
  {2500, FT_DIAG,    0,  40,   0,  0,  0, "d40"},        //      ~4.0
  {2500, FT_DIAG,    0,  36,   0,  0,  0, "d36"},        //      ~4.5
  {2500, FT_DIAG,    0,  32,   0,  0,  0, "d32"},        //      ~5.0
  {2500, FT_DIAG,    0,  27,   0,  0,  0, "d27"},        //      ~6.0
  {2500, FT_DIAG,    0,  23,   0,  0,  0, "d23"},        //      ~7.0
  {2500, FT_DIAG,    0,  20,   0,  0,  0, "d20"},        //      ~8.0
  {2500, FT_DIAG,    0,  18,   0,  0,  0, "d18"},        //      ~8.9
  {2500, FT_DIAG,    0,  16,   0,  0,  0, "d16"},        //      ~10.0 MHz (videoda temiz cikti)
  {2500, FT_DIAG,    0,  14,   0,  0,  0, "d14"},        //      ~11.4 (deneysel >10MHz)
  {2500, FT_DIAG,    0,  12,   0,  0,  0, "d12"},        //      ~13.3
  {2500, FT_DIAG,    0,  10,   0,  0,  0, "d10"},        //      ~16.0
  {2500, FT_DIAG,    0,   8,   0,  0,  0, "d8"},         //      ~20.0 MHz (mozaik beklenir = ust sinir)
  {4000, FT_SCROLL,  0,   0,   0,  0,  0, "SCROLL"},     // ---- hareket: kayan cubuk
  {4000, FT_PULSE,   0,   0,   0,  0,  0, "PULSE"},      //      ekran nabzi (update dim-sweep)
};
static const int     FT_COUNT       = sizeof(FT_SEQ)/sizeof(FT_SEQ[0]);
static const uint8_t FT_BASE_BRIGHT = 160;             // sweep/desenler icin sabit parlaklik

static bool     ftActive     = false;
static int      ftPhase      = 0;
static uint32_t ftPhaseStart = 0;
static bool     ftDrawn      = false;                  // mevcut faz cizildi mi (statik = bir kez)
static uint32_t ftLastTick   = 0;                      // hareketli faz son cizim ms
static uint32_t ftBlinkSub   = 0;                      // BLINK 500ms alt-faz sayaci
// bitince geri yuklenecek anlik ayarlar
static uint8_t  ftSvBr, ftSvGr, ftSvGg, ftSvGb, ftSvCon, ftSvSat, ftSvBlur, ftSvMz;
static uint32_t ftSvDiv = PANEL_DEFAULT_DIV;

static void ftLabel(int idx){
  char lab[16]; snprintf(lab, sizeof(lab), "P%02d %s", idx, FT_SEQ[idx].code);
  int w = (int)strlen(lab)*6 + 2; if(w > PANEL_W) w = PANEL_W;
  for(int y=0;y<9;y++) for(int x=0;x<w;x++) matrix.drawPixel((uint8_t)x,(uint8_t)y,0,0,0); // okunur kalsin diye siyah kutu
  matrix.setTextSize(1);
  matrix.setTextColor(0xFFFF);                         // beyaz (565)
  matrix.setCursor(1,1);
  matrix.print(lab);
}
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
void loop(){
  if(otaActive){            // OTA sirasinda SADECE OTA calisir:
    ArduinoOTA.handle();    // panel taramasi ve WS islemleri durur,
    // Async (web/espota) OTA yarida kesilirse takilip kalmasin: 30 sn ilerleme
    // yoksa paneli geri al. (checkGithubOTA senkron calisir, restart ile biter.)
    if(lastOtaActivity && millis()-lastOtaActivity > 30000){ otaActive=false; ws.enable(true); redrawCurrent(); }
    return;                 // flash yazimi kesintisiz tamamlanir
  }
  matrix.refresh();
  yield();                  // WiFi/TCP-IP yiginina CPU birak (ARP/ping cevaplari icin sart)
  ArduinoOTA.handle();
  // ---- gecici ag teshisi: 5 sn'de bir baglanti durumu ----
  static uint32_t dbg=0;
  if(millis()-dbg>5000){
    dbg=millis();
    logf("[NET] heap=%u min=%u blok=%u RSSI=%d",
      ESP.getFreeHeap(), ESP.getMinFreeHeap(), ESP.getMaxAllocHeap(), WiFi.RSSI());
  }
  if(msgReady){ handleMessage(rxbuf,(size_t)msgLen); msgReady=false; }
  if(ftActive) ftLoop();        // flicker self-test aktifse fazlari ilerlet (apps yerine)
  else if(!standby) apps.loop(); // uygulama aciksa zamani gelince fetch+render (kendi throttle'i var); uykuda durur
  sensorTick();                 // sensorler + enkoder/dokunmatik/alkis olaylari + oto parlaklik + telemetri
  static uint32_t t=0;
  if(millis()-t>2000){ ws.cleanupClients(); t=millis(); }
  // WiFi bekcisi: kopussa yeniden bagla, 60sn duzelmezse temiz baslangic
  static uint32_t wifiDownSince=0;
  if(WiFi.status()!=WL_CONNECTED){
    if(!wifiDownSince) wifiDownSince=millis();
    static uint32_t lastTry=0;
    if(millis()-lastTry>10000){ lastTry=millis(); WiFi.reconnect(); }
    if(millis()-wifiDownSince>60000) ESP.restart();
  } else wifiDownSince=0;

  if(otaNowRequested && WiFi.status()==WL_CONNECTED && !otaActive){
    otaNowRequested=false; checkGithubOTA();
  }
}

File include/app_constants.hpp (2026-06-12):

/******************************************************************************************
 * @file        app_constants.hpp
 * @brief       ESP32-S3 driver for FM6363C (S-PWM) based 80x40 1/20 scan HUB75E panel
 *              Ported from mrcodetastic's MBI5153 implementation (ESP32-PWM-MatrixPanel-DMA)
 *              Panel profile source: p4_indoor 1001 seri kodu FM6363 138 çip (.ssx)
 ******************************************************************************************/

#pragma once
#include "hal/gpio_types.h"

// =========================================================================
// KEMAL'S HUB75E WIRING (ESP32-S3 DevKitC) - matches existing Arduino sketch
// =========================================================================
// HUB75 connector pin -> FM6363 function:
//   CLK -> DCLK (data clock), LAT -> LE (command/latch), OE -> GCLK (grayscale clock)

#define ADDR_A_PIN              GPIO_NUM_18
#define ADDR_B_PIN              GPIO_NUM_8
#define ADDR_C_PIN              GPIO_NUM_3
#define ADDR_D_PIN              GPIO_NUM_9    // <-- if rows look interleaved/wrong, swap D and E
#define ADDR_E_PIN              GPIO_NUM_13

#define MBI_GCLK                GPIO_NUM_11   // HUB75 "OE" pin carries GCLK on S-PWM panels
#define MBI_LAT                 GPIO_NUM_10   // HUB75 "LAT" = LE (command line)
#define MBI_DCLK                GPIO_NUM_12   // HUB75 "CLK" = DCLK
#define MBI_SRCLK               GPIO_NUM_NC   // not used on this panel (74HC138 row decode)

// RGB data lines - this panel is a standard HUB75 "two scan": 2 RGB groups
#define MBI_R1                  GPIO_NUM_4    // top half  (rows  0..19)
#define MBI_G1                  GPIO_NUM_5
#define MBI_B1                  GPIO_NUM_6
#define MBI_R2                  GPIO_NUM_7    // bottom half (rows 20..39)
#define MBI_G2                  GPIO_NUM_15
#define MBI_B2                  GPIO_NUM_16

// -------------------------------------------------------
// Internals specific to code and hardware.
// -------------------------------------------------------

#define ESP32_GREY_DMA_STORAGE_TYPE uint16_t  // DMA output of one uint16_t at a time.

// For DMA GCLK and Address Line Data (GPSPI2 octal output bit positions)
#define BIT_GCLK  (1 << 0)
#define BIT_A     (1 << 1)
#define BIT_B     (1 << 2)
#define BIT_C     (1 << 3)
#define BIT_D     (1 << 4)
#define BIT_E     (1 << 5)

// For DMA Greyscale / command data (LCD peripheral parallel bit positions)
// Two RGB groups only (standard HUB75 two-scan panel)
#define BIT_G1   (1 << 0)
#define BIT_B1   (1 << 1)
#define BIT_R1   (1 << 2)
#define BIT_RGB1_CLR (0b111 << 0)
#define BIT_G2   (1 << 3)
#define BIT_B2   (1 << 4)
#define BIT_R2   (1 << 5)
#define BIT_RGB2_CLR (0b111 << 3)
#define BIT_LAT  (1 << 6)

#define BIT_ALL_RGB    (BIT_G1 | BIT_B1 | BIT_R1 | BIT_G2 | BIT_B2 | BIT_R2)
#define BIT_ALL_R      (BIT_R1 | BIT_R2)
#define BIT_ALL_G      (BIT_G1 | BIT_G2)
#define BIT_ALL_B      (BIT_B1 | BIT_B2)

// =========================================================================
// PANEL GEOMETRY: 80x40 pixels, 1/20 scan, FM6363C, 74HC138 row decoding
// =========================================================================
#define PANEL_SCAN_LINES        20  // 1/20 scan
#define PANEL_MBI_LED_CHANS     16  // channels per FM6363C

// ===== ZINCIR (v15): dikey istif, HUB75 OUT->IN, hepsi ayni yonde =====
#ifndef PANEL_CHAIN_PANELS
#define PANEL_CHAIN_PANELS       3  // 1 yaparsan tek-panel v14c davranisina doner
#endif
#define PANEL_MBI_CHAIN_LEN     (5 * PANEL_CHAIN_PANELS)  // renk hatti basina IC

#define PANEL_PHY_RES_X 80
#define PANEL_PHY_RES_Y (40 * PANEL_CHAIN_PANELS)   // 120 (portrait istif)

#define PANEL_MBI_RES_X 80
#define PANEL_MBI_RES_Y PANEL_PHY_RES_Y

// Panel-kimlik testinde kirmizi/yesil/mavi ASAGIDAN yukari cikiyorsa
// kablo sirasi terstir -> bunu 1 yap.
#ifndef FM_CHAIN_REVERSE
#define FM_CHAIN_REVERSE 0
#endif

// If the image is horizontally scrambled in 16px blocks, toggle this:
// FM6363 guide: "first 16-bit data is for channel 15" -> channel order may be reversed
#define FM6363_REVERSE_CHANNEL_ORDER 0

// =========================================================================
// FM6363C CONFIG REGISTER VALUES
// Extracted from the panel's own factory .ssx profile - per colour channel!
// =========================================================================
#define FM_CFG1_R  0x13F0   // 5104  : scan=20 (bits13:8=19), 74-GCLK mode, cfg1[5:4]=11
#define FM_CFG1_G  0x13B0   // 5040
#define FM_CFG1_B  0x13B0   // 5040

#define FM_CFG2_R  0xF39D   // 62365 : blanking + IGAIN per factory profile
#define FM_CFG2_G  0xE79D   // 59293
#define FM_CFG2_B  0xD79D   // 55197

#define FM_CFG3_R  0x60B6   // 24758
#define FM_CFG3_G  0x60B6
#define FM_CFG3_B  0x60B6

#define FM_CFG4_R  0x5A00   // 23040 : factory default reg4
#define FM_CFG4_G  0x5A70   // 23152
#define FM_CFG4_B  0x5A70
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

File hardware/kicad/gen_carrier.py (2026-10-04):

#!/usr/bin/env python3
# -*- coding: utf-8 -*-
"""
MagPanel Carrier — KiCad 8 proje ureticisi (sematik + PCB + uretim ciktilari).

Tasarim yaklasimi (enclosure/generate_case.py, hardware/gen_schematic.py ile ayni):
her sey bu dosyadaki tablolardan URETILIR, elle cizilmez. Pin atamalari
include/app_constants.hpp (HUB75), include/panel_sm16380.h (LAT2/LAT3) ve
include/sensors.h (sensorler) ile birebir ayni olmali.

Asamalar (KiCad 8'in python3'u ile: Linux /usr/bin/python3, macOS
/Applications/KiCad/KiCad.app/Contents/Frameworks/Python.framework/Versions/Current/bin/python3):
  python3 gen_carrier.py sch      # .kicad_sch + .kicad_pro + kutuphaneler   (sadece stdlib)
  python3 gen_carrier.py pcb      # yerlesim + kart cercevesi + on-yonlendirme (pcbnew)
  python3 gen_carrier.py route    # Freerouting 2.1.0 (Java 21+, yoksa work/'e iner) + GND dokumu
  python3 gen_carrier.py fab      # ERC/DRC kapisi + gerber/drill/BOM/CPL/PDF (kicad-cli)
                                  # + gorseller (Chromium/Chrome; yol icin CHROME=...)
  python3 gen_carrier.py all      # hepsi sirayla
"""
import os
import sys
import json
import math
import shutil
import argparse
import collections
import subprocess
from pathlib import Path

HERE = Path(__file__).resolve().parent
sys.path.insert(0, str(HERE))
import sexp                                  # noqa: E402
import schlib                                # noqa: E402
from sexp import Sym                         # noqa: E402
from schlib import uid, r4                   # noqa: E402

PROJ = 'magpanel-carrier'
OUT = HERE / PROJ
REV = '1.2'
DATE = '2026-10-02'
DIY = False      # --diy: ev yapimi cift yuz surum (dry film + MSLA ekran pozlama); set_variant_diy() tablolari degistirir
SS = False       # --ss: tek yuz ev yapimi kart, 150 x 100 mm (magpanel-carrier-ss/, fab-ss/); DIY kurallariyla
G = 2.54                                     # sematik izgara (100 mil)

# =============================================================================
#  ELEKTRIKSEL TASARIM (tek kaynak)
# =============================================================================
# ESP32-S3-DevKitC-1 basliklari (Espressif v1.1 dokumani + resmi DXF ile dogrulandi).
# Sembol/footprint pin no: J1 pin n -> n, J3 pin n -> 22+n.
DEVKIT_J1 = ['3V3', '3V3', 'RST', 'IO4', 'IO5', 'IO6', 'IO7', 'IO15', 'IO16', 'IO17', 'IO18',
             'IO8', 'IO3', 'IO46', 'IO9', 'IO10', 'IO11', 'IO12', 'IO13', 'IO14', '5V', 'GND']
DEVKIT_J3 = ['GND', 'IO43/TX', 'IO44/RX', 'IO1', 'IO2', 'IO42', 'IO41', 'IO40', 'IO39', 'IO38',
             'IO37', 'IO36', 'IO35', 'IO0', 'IO45', 'IO48', 'IO47', 'IO21', 'IO20', 'IO19', 'GND', 'GND']
DEVKIT_ROW_09 = 22.86      # resmi Espressif karti (0.9")
DEVKIT_ROW_10 = 25.40      # yaygin N16R8 klonlari (1.0"; YD-ESP32-S3 tipi, 2x USB-C)
# Sag soket sira(lar)i. Eldeki kart 1.0" (1:1 baski testinde dogrulandi, 2026-10-02).
# Resmi Espressif karti icin [DEVKIT_ROW_09], ikisi birden icin [DEVKIT_ROW_09, DEVKIT_ROW_10].
DEVKIT_RIGHT_ROWS = [DEVKIT_ROW_10]
DEVKIT_ROW_IN = min(DEVKIT_RIGHT_ROWS)      # sol siraya en yakin sag sira (yerlesim icin)

def devkit_pin(name):
    """'IO10' -> sembol pin numarasi (str)."""
    if name in DEVKIT_J1:
        return str(DEVKIT_J1.index(name) + 1)
    return str(DEVKIT_J3.index(name) + 23)

# HUB75: ESP GPIO -> sinyal (include/app_constants.hpp; LAT2/LAT3 panel_sm16380.h)
HUB_GPIO = {
    'R1': 'IO4', 'G1': 'IO5', 'B1': 'IO6', 'R2': 'IO7', 'G2': 'IO15', 'B2': 'IO16',
    'ADDR_A': 'IO18', 'ADDR_B': 'IO8', 'ADDR_C': 'IO3', 'ADDR_D': 'IO9', 'ADDR_E': 'IO13',
    'CLK': 'IO12', 'LAT': 'IO10', 'OE': 'IO11', 'LAT2': 'IO17', 'LAT3': 'IO14',
}
# 74HCT245 kanal eslemesi (PCB'de tamponlar 180 derece donuk: A pinleri DevKit'e,
# B pinleri HUB75'e bakar; sira DevKit J1 pin sirasini izler -> kesisimsiz yonlendirme).
# pin 2..9 = A0..A7, pin 18..11 = B0..B7 (Ai <-> Bi).
BUF_CH = {
    'U2': ['ADDR_A', 'LAT2', 'B2', 'G2', 'R2', 'B1', 'G1', 'R1'],          # A0..A7
    'U3': ['LAT3', 'ADDR_E', 'CLK', 'OE', 'LAT', 'ADDR_D', 'ADDR_C', 'ADDR_B'],
}
# Seri 33R: her hatta tek 0805 (el lehimi; 4x0603 dizi ince uc ister). PCB'de tek sutun, her direnc
# kendi B pininin satirinda: R10..R17 = U2 B7..B0 (satir 2..9), R18..R25 = U3 B7..B0 (satir 13..20).
# pin 1 tampon tarafi (*_5V), pin 2 konnektor tarafi (HUB_*). (ref, sinyal, DevKit satiri)
SERIES_R = ([('R%d' % (10 + k), sig, 2 + k) for k, sig in enumerate(reversed(BUF_CH['U2']))] +
            [('R%d' % (18 + k), sig, 13 + k) for k, sig in enumerate(reversed(BUF_CH['U3']))])
# HUB75E konnektor pinleri (standart). 14 = LAT (panel basina ayri).
HUB_PINS = {1: 'R1', 2: 'G1', 3: 'B1', 4: 'GND', 5: 'R2', 6: 'G2', 7: 'B2', 8: 'ADDR_E',
            9: 'ADDR_A', 10: 'ADDR_B', 11: 'ADDR_C', 12: 'ADDR_D', 13: 'CLK', 14: None,
            15: 'OE', 16: 'GND'}
HUB_CONN = [('J2', 'LAT', 'PANEL 1', 'LAT = IO10 (P4 ve P1.86)'),
            ('J3', 'LAT2', 'PANEL 2', 'LAT2 = IO17 (yalniz coklu P1.86)'),
            ('J4', 'LAT3', 'PANEL 3', 'LAT3 = IO14 (yalniz coklu P1.86)')]
# Acilista (GPIO henuz surulmezken) paneli karanlik tutan pull-down'lar
PULLDOWNS = [('R2', 'LAT'), ('R3', 'LAT2'), ('R4', 'LAT3'), ('R5', 'OE')]
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

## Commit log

2026-06-13 BLE provisioning + local build OTA fix
    - Local builds (FW_BUILD=0) no longer auto-OTA; prevents boot loop when
    CI firmware has wrong WiFi password after a credential change
    - BLE provisioning: if WiFi fails at boot, panel advertises as
    'MagPanel-Setup' over BLE; use nRF Connect to write 'SSID\nPASS' to
    the CRED characteristic; credentials saved to NVS, panel restarts
    - NVS credential priority: NVS (BLE-stored) > compiled wifi_config.h > BLE mode
    - Fix upload_port to 192.168.1.33 (panel current IP)
    https://claude.ai/code/session_01729z8mfuzpDVT8xM73TWmN
    [main.cpp]
2026-06-13 Replace BLE provisioning with WiFi AP-mode (fixes matrix DMA crash)
    BLE library reserved enough internal RAM that the HUB75 DMA buffer
    allocation in Matrix::initMatrix() failed (assert dma_grey_gpio_data
    != nullptr) -> boot loop. BLE + WiFi + large LED DMA do not fit
    together on this chip.
    Switch to WiFi AP-mode provisioning instead: on WiFi failure the panel
    serves an open 'MagPanel-Setup' network; user connects, opens
    http://192.168.4.1, enters SSID/password; saved to NVS; restart.
    Same wireless-reprovisioning goal, no extra RAM, no special app needed.
    NVS credential priority (NVS > compiled > AP mode) and the FW_BUILD==0
    OTA guard are retained.
    https://claude.ai/code/session_01729z8mfu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
    [main.cpp]
2026-06-13 Web UI: animate GIFs frame-by-frame instead of sending a single frame
    Loading a GIF via <img>+canvas only captured the first frame, so the
    panel showed a static image. Decode all GIF frames with the browser's
    native ImageDecoder (WebCodecs, no external lib), scale each to 80x120,
    and stream them to the panel in a delay-respecting loop. Falls back to
    the existing single-frame path for static images or browsers without
    ImageDecoder. Animation stops on any other action (gallery, draw,
    clear, test, new image). bufferedAmount guard avoids WS backlog.
    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
2026-06-13 Add CLAUDE.md with project working notes and open issues
    Captures: secrets/branch constraints, low-heap (~7KB max block) limit,
    fixed bugs (FW_BUILD==0 OTA guard, BLE->AP-mode DMA crash), the open GIF
    web-page JS error with diagnosis steps, flashing workflows (USB/espota/
    web-update), local env quirks (broken ~/.git, apostrophe path, IP hopping
    needing a DHCP reservation), and the WS protocol. No secrets included.
    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
2026-06-13 index sayfasini PROGMEM'den akitarak gonder (art/ws "is not defined" fix)
    Sorun: "/" handler'i sayfayi FPSTR ile ~9 KB'lik tek bir heap String'e
    kopyalayip (replace + send) gonderiyordu. Bellek baskisi/parcalanma altinda
    yanit yarim gidebiliyor; govde (butonlar) gorunuyor ama sondaki <script>
    blogu kesiliyor. Eksik script parse edilemiyor -> hicbir global tanimlanmiyor
    -> inline handler'lar "art is not defined" / "ws is not defined" firlatiyor.
    (Sayfa HTML/JS'i tam haliyle gecerli; node --check ve jsdom ile dogrulandi.)
    Cozum: sayfa artik dogrudan flash'tan, Content-Length ile, kucuk tamponlar
    halinde akitiliyor (beginResponse + filler). Buyuk contiguous heap ayrimi
    yok; {{VER}} yer tutucus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
    [main.cpp]
2026-06-13 enclosure: 320x480 P4 difüzör kasası (parametrik, 2x2 fayans)
    case20mm.stl (162x162 kare, ince difüzör + egg-crate) tasarımını 32x48cm
    panele uyarladım. Aspect 1:1->2:3 değiştiği için parametrik yeniden üretim:
    kapalı difüzör ön + egg-crate ışık boşluğu + 14mm panel yuvası + üst kablo çıkışı.
    2x2 fayans (163x243mm, ~250mm yatağa sığar) + 5 dikey-vidalı ek plaka.
    - generate_case.py: trimesh tabanlı parametrik üretici (tüm ölçüler P sözlüğünde)
    - stl/: 4 fayans + 5 plaka + tek parça referans (hepsi watertight)
    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
    [full_case_1piece.stl, splice_Hlf.stl, splice_Hrt.stl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]
2026-06-13 web UI GIF oynatma duzeltmesi: ImageDecoder.tracks.ready beklenmiyordu
    playGif() 'await dec.completed' yapip 'await dec.tracks.ready' yapmadan
    tracks.selectedTrack.frameCount okuyordu. Iz metadata'si hazir olmadigindan
    frameCount 0/1 gorunuyor -> playGif false donup statik tek-kare yoluna
    dusuyordu (konsol hatasi yok, panel ilk kareyi statik gosteriyor, animasyon
    oynamiyor). Duzeltme: once 'await dec.tracks.ready', sonra 'await dec.completed';
    ayrica selectedTrack null korumasi.
    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
2026-06-13 GIF debug: LOG paneline adim adim teshis mesajlari ekle
    ImageDecoder desteği yok mu, frameCount sifir mi, decode hatasi mi
    oldugu LOG panelinde gorunur. Kullanici F12 acmadan debug edebilir.
    https://claude.ai/code/session_01UawgRsDdLyXXe6JBSbmsXV
2026-06-13 Video/GIF banding fix: render sirasinda refresh + 15fps throttle
    TESHIS (kullanici ekran kaydindan): tek statik kare temiz gosteriliyor,
    ama video oynarken panel giderek yikanmis beyaz yatay bantlara donusuyor.
    KOK NEDEN: renderFrame() 9600 fm_set_pixel (doygunluk/kontrast/CIE +
    8 bit-duzlemi DMA yazimi) + blocking update() ile milisaniyeler suruyor.
    Bu sirada matrix.refresh() cagrilamadigi icin panel titreyip kararıyor;
    kamera bunu yatay bant olarak yakaliyor. RAF'in 60fps kare pompasi loop'u
    tamamen doyurunca refresh acliktan oluyor -> bantlanma kotuyor.
    COZUM:
    - main.cpp renderFrame(): agir render dongusu icinde her 8 satirda (mozaik
    modunda her blok satirinda) matrix.refresh() cagir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
    [main.cpp]
2026-06-14 DCLK canli tuner: WS 0x0A + NVS + runtime bolen degisimi
    Donanima 'en uygun' DCLK jumper-kablo bus'ina ozgu ve ancak panel uzerinde
    test edilerek bulunur (2.5MHz calisiyor, 7MHz ring->mozaik). Reflash dongusu
    olmadan bulmak icin canli tuner:
    - Bus_Parallel16::set_clock_divider(): LCD_CAM.lcd_clkm_div_num'u calisma
    aninda yazar (loop context, transferler arasi guvenli). div sadece kaydirma
    hizini degistirir; 1/20 scan yapisi (20 satir,74 GCLK,deadtime3) korunur.
    - Matrix::setClockDiv() ile disari acildi.
    - WS opcode 0x0A: boleni uygular + NVS 'panelcfg/dclkdiv'e kaydeder + yeniden
    cizer. Boot'ta NVS bolen okunup uygulanir (reboot'ta kalir).
    - Derlenmis varsayilan guvenli 2.5MHz'e (div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
    [Matrix.h, lcd_dma_parallel16.cpp, lcd_dma_parallel16.hpp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]
2026-06-14 UI: DCLK tuner'a 7.0–10.0 MHz seçenekleri eklendi
    Yeni butonlar: 7.0 (bölücü 23), 8.0 (20), 8.9 (18), 10.0 (16) MHz.
    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
2026-06-14 Flicker: surekli (circular) DMA refresh - panel artik CPU'suz, kesintisiz taranir
    Kok neden: eski model tek-atislik + bloklayan DMA idi. loop() her turda bir
    kez matrix.refresh() cagiriyordu; aralardaki WiFi/yield bosluklarinda GCLK
    durunca FM6363C S-PWM sayaci donuyor -> goz flicker'i. Icerik degisince de
    ~30ms'lik bloklayan grayscale push tek bir yavas refresh olarak akiyordu ->
    6 serit sweep.
    Cozum (ticari receiver mantigi):
    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
2026-06-14 Uygulamalar: Saat/Timer/Hava/Dunya Kupasi/Spotify (firmware-tarafi render)
    Panel verileri KENDISI ceker (NTP saat, HTTPS hava/skor) ve GFX_Lite ile
    cizer; tarayici gerekmez. Son secilen uygulama NVS'e ("appcfg") kaydedilir ->
    reboot'ta panel tarayicisiz ayni uygulamayla geri gelir.
    - include/apps.h: app framework (Apps sinifi). Saat (NTP, UTC+3), Timer
    (geri sayim), Hava (Open-Meteo, anahtarsiz, WMO kod->Turkce), Dunya Kupasi
    2026 (TheSportsDB, lig ID configurable), Spotify (ISKELET: token tarayici
    PKCE'den WS 0x0D ile gelir, panel currently-playing'i ceker). Cizim:
    Matrix/GFX_Lite setTextColor(CRGB)+print. JSON manuel parse (ArduinoJson yok);
    buyuk yanitlar PSRAM'e duser (CONFIG_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
    [apps.h, main.cpp]
2026-06-14 fix(apps): CRGB to RGB565 conversion in centerText
    GFX_Lite setTextColor template assigns to uint16_t internally;
    CRGB has no implicit uint16_t conversion. Convert explicitly via
    bit-shift formula before calling setTextColor.
    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
    [apps.h]
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2026-06-14 Blur: 2x2 kademesi ekle (daha granuler artis)
    Blur kaydiricisina Kapali ile 3x3 arasina 2x2 ara kademesi eklendi.
    img_blur artik yariçap degil kademe indeksi: 0=kapali, 1=2x2, 2=3x3,
    3=5x5, 4=7x7. 2x2 asimetrik (piksel+sag+alt+sag-alt), digerleri
    simetrik box blur. Web UI slider max=4, etiketler guncellendi.
    https://claude.ai/code/session_01DHsn8W5C13is6RgFUicV4z
    [Matrix.h, main.cpp]
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2026-06-18 fix(web): galeri isimlerini WS ile gonder, /api/gallery ERR_TIMED_OUT'u onle
    Galeri listesi artik acik olan WebSocket uzerinden "G:" onekli metin frame'i
    ile geliyor (sendGallery, WS_EVT_CONNECT'te). Boylece tarayici ayri bir
    /api/gallery HTTP istegi acmiyor. Dusuk heap'te (en buyuk blok ~7KB) sayfa
    yuklenirken zaten / (keep-alive) + /ws soketleri aciktiyken ucuncu bir TCP
    soketi ayrilamiyor, istek takiliyor ve net::ERR_TIMED_OUT olusuyordu.
    /api/gallery endpoint'i (iOS app gibi harici tuketiciler icin) korundu.
    Claude-Session: https://claude.ai/code/session_0173moEAdL6G43cV84D9ztsQ
    [main.cpp]
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2026-06-18 Allow DCLK above 10 MHz (divider down to 8) + UI/test steps
    Video analysis of the first flicker test showed real panel flicker that
    drops with faster DCLK (d18->d16 ~30% less amplitude) and NO mosaic at d16
    (10 MHz). To let the user push higher and find the true ceiling:
    - Lower the divider clamp from 16 (10 MHz) to 8 (20 MHz) in all three places:
    set_clock_divider(), the 0x0A WS handler, and the boot/NVS-restore check
    (so a saved fast divider actually survives reboot).
    - Add UI buttons 11.4 / 13.3 / 16.0 / 20.0 MHz (div 14/12/10/8) with an
    "experimental >10 MHz" note (jumper-bus ringing can cause mosaic).
    - Extend the flicker self-test DCLK sweep to d14/d12/d10/d8 (now 33 phases,
    ~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
    [lcd_dma_parallel16.cpp, main.cpp]
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2026-09-27 p186-test: WiFi diagnostics, setup-AP fallback, reliable serial log
    - Log the networks seen at boot (RSSI, channel, security) and the
    disconnect reason when joining fails.
    - If neither the NVS nor the compiled credentials connect, open the
    MagPanel-Setup AP: the test page works at 192.168.4.1 and /wifi saves
    new credentials to NVS ("wificfg", shared with the P4 firmware).
    - logf writes via printf: HWCDC Serial went silent when the monitor
    attached after boot, while stdout (ESP_LOG path) kept working.
    - Only call WiFi.reconnect() when the station is actually disconnected
    (stops the "sta is connecting" error spam).
    - CLAUDE.md: record the first successful hardware test.
    Co-Authored-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
    [p186_test.cpp]
2026-09-27 p186-test: silence TWDT log spam and first-boot NVS open errors
    Claude-Session: https://claude.ai/code/session_01TmYNfRTLWUaLVhxu4mFuDh
    [p186_test.cpp]
2026-09-27 p186: P1.86-Y52 column layout (dead channels 0,16,144,160)
    The grid photo showed 15-column gaps around x=16, 144 and 160, the x=0
    border missing and the rightmost 4 columns dark: chips 0, 1, 9 and 10
    drive only 15 LEDs and leave channel 0 unconnected. A lookup table maps
    the 172 physical columns onto the 176 chain positions, skipping those
    four. Linear mapping + X offset stays available as col_layout=0.
    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
    [p186_test.cpp, panel_sm16380.h]
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2026-10-01 Hardware: generated KiCad 8 schematic + PCB for the ESP32-S3 carrier board
    hardware/kicad/gen_carrier.py builds the whole KiCad project from tables,
    the same way enclosure/generate_case.py and hardware/gen_schematic.py work:
    - sch: A3 schematic with the ESP32-S3-DevKitC-1 socket, 2x 74AHCT245
    level shifters, 4x33R series arrays, LAT/OE pull-downs, three HUB75E
    outputs (per-panel LAT on IO10/IO17/IO14), 5 V input protection
    (PTC + TVS + bulk) and the five sensor headers plus an expansion header
    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
    [magpanel-carrier-bom.csv, magpanel-carrier-jlc-bom.csv, magpanel-carrier.kicad_pcb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]
2026-10-02 Hardware: fit the KiCad carrier to the parts on hand
    - Level shifters are CD74HCT245E in DIP-20 now (socketed footprint),
    stacked in one column with the A pins on the DevKit pin pitch
    - DevKit right socket row is 1.0in (25.4 mm): the N16R8 clone on hand
    seated there in the 1:1 paper test; DEVKIT_RIGHT_ROWS switches back
    to the official 0.9in board
    - Sensor headers follow the printed pin order of the JSUMO modules.
    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
    [magpanel-carrier-bom.csv, magpanel-carrier-jlc-bom.csv, magpanel-carrier.kicad_pcb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]
2026-10-02 Hardware: make the KiCad carrier hand-solder friendly (v1.2)
    - Replace the four 4x0603 resistor arrays (0.35 mm between pads) with
    16 discrete 0805 33R resistors (R10-R25) in one column, each in line
    with its 74HCT245 B pin (1.14 mm between neighbouring pads).
    - Use HandSolder footprints for every SMD part and LongPads DIP sockets.
    - Add a 0.5 mm courtyard clearance DRC rule. v1.1 had 13 violations
    (tightest 0.16 mm); v1.2 has none (tightest 0.58 mm).
    - Widen the gaps between the HUB75 box headers from 2.4 mm to 3.8 mm and
    move the SMD parts under the DevKit 4.5 mm away from the socket rows.
    - Re-lay the 5 V input block; tie the TVS anode straight to the input
    GND with a locked wid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
    [magpanel-carrier-bom.csv, magpanel-carrier-jlc-bom.csv, magpanel-carrier.kicad_pcb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]
2026-10-02 Hardware: SMT assembly files for Robotistan and JLCPCB with verified LCSC parts
    - Add SMT_PARTS: manufacturer, MPN and LCSC number for every SMD part,
    checked against LCSC's product API (all in stock). The schematic
    fields, the JLC BOM and the full BOM now carry them.
    - Generate Robotistan's BOM and pick-and-place spreadsheets with the
    columns of their sample files. xlsx.py is a small stdlib writer, so
    the fab stage needs no extra Python package.
    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
    [magpanel-carrier-bom.csv, magpanel-carrier-jlc-bom.csv, magpanel-carrier-robotistan-bom.xlsx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]
2026-10-02 Hardware: use 10k for R7 so every SMD part is in Robotistan's stock
    Robotistan's BOM check reported the 100k part (C17407, an LCSC "(SMT)"
    listing) as out of stock. R7 only pulls the unused IO2 input low, so its
    value does not matter. It now uses the same 10k part as R2-R6 and the
    assembly BOM shrinks to 8 lines. Placement and copper are unchanged.
    Also pin the creation time KiCad writes into gerber and drill files to
    DATE, so the gerber zip only changes when the board does.
    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
    [magpanel-carrier-bom.csv, magpanel-carrier-jlc-bom.csv, magpanel-carrier-robotistan-bom.xlsx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]
2026-10-02 Hardware: also export the SMT BOM in the Turkish "default_bomlist" layout
    fab now writes fab/magpanel-carrier-bomlist.xlsx with the columns of
    that template: Fabrika Kodu (MPN), Açıklama, Designatör, Malzeme
    Kılıfı, Adet (per board), on a plain Calibri sheet named "Worksheet".
    SMT_PARTS gains a short technical description per part for the
    Açıklama column; xlsx.py gains a plain style. Every other output is
    byte-identical.
    Claude-Session: https://claude.ai/code/session_01CdkdNf8EcXy8Er9VmQyghz
    [magpanel-carrier-bomlist.xlsx]
2026-10-02 Hardware: home-made double-sided carrier for an Elegoo Saturn 3 and dry film
    gen_carrier.py --diy builds a second KiCad project from the same
    schematic (magpanel-carrier-diy/, outputs in fab-diy/) for a board
    made at home: negative dry film exposed on the Saturn 3 LCD, no
    plated holes.
    - SMD parts move to the bottom. Through-hole pads keep copper on the
    bottom only, since socket pins cannot be soldered from the top, and
    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
    [magpanel-carrier-diy-bom.csv, magpanel-carrier-diy.kicad_pcb, magpanel-carrier-diy.kicad_sch]
2026-10-04 Hardware: single-sided build of the home-made carrier with 19 wire bridges
    Same DIY board, made from single-sided stock: only the bottom copper is
    exposed (fab-diy/saturn3/alt.goo, no second exposure, no flipping) and the
    13 top-layer bridges become insulated wires on the copper side, soldered
    to the via pads.
    - gen_carrier.py --ss fab: ss_wires groups vias joined by top tracks and
    takes a minimum spanning tree by straight distance in each group (one
    wire per edge, no splices in the air). ss_minimize checks the result
    with KiCad connectivity on a copy of the board (top copper removed,
    wires added as tracks: 0 unconnected) and drops wires whose pads are
    already joined on the bottom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
    [magpanel-carrier-ss-teller.csv]
2026-10-04 Hardware: 150 x 100 mm single-sided home-made carrier with 3 wire bridges
    The user's blank is a 15 x 10 cm single-sided board, so the single-sided
    build gets its own layout instead of reusing the 100 x 63.5 mm
    double-sided board (19 wires). Same schematic, separate KiCad project
    (magpanel-carrier-ss/), outputs in fab-ss/, guide in TEK-YUZ.md.
    - ss_place(): HUB75 headers left, series 33R column, buffers, DevKit,
    sensor headers in a column on the right, 5 V input on the bottom edge.
    DIY rules apply (SMDs on the copper side, THT pads on B.Cu only).
    - ss_hub_tracks(): the HUB75 ribbon is drawn as fixed tracks. Headers
    are staggered by 1.27 mm so the lines between them run straight; inside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
    [magpanel-carrier-ss-bom.csv, magpanel-carrier-ss-teller.csv, magpanel-carrier-ss.kicad_pcb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]
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2026-10-04 Hardware: exposure files for positive photoresist (Positiv 20)
    The user coats the board with Kontakt Chemie Positiv 20, a positive resist:
    exposed areas dissolve in the developer, the opposite of the negative dry
    film the existing files assume. With those files the board would come out
    inverted.
    - fab now also writes saturn3-pozitif/ for both home-made boards: the same
    placement layer and times, copper image inverted inside the board
    outline (UVtools InvertColor; the frame stays lit). Names start with
    pozitif- so they do not clash with the negative files on the printer.
    - fab checks the positive image is the exact inverse inside the board and
    identical outside it. Positive test: ban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
    [gen_carrier.py]
